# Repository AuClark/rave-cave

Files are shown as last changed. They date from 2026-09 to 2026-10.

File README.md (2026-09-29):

<p><picture><source media="(prefers-color-scheme: dark)" srcset="docs/brand/sektor5-stencil-white.svg">SEKTOR5</picture></p>

A light and visuals rig driven by the DJ decks. A Raspberry Pi Compute Module 4 (the **brain**) joins the Pioneer DJ Link network and listens to the mixer over USB. It reads what each deck is playing, analyses every loaded track ahead of time to find breakdowns, builds and drops, and drives the lights and projection from one scene engine.

**Status (27 Sep 2026):** running end to end in the workshop.
- Two XDJ-700s and a DJM-450 drive two LED tubes, a DMX par can and a mapped projector.
- The live deck follows the mixer faders.
- Generative visuals have 18 sketches with presets.
- Anyone can watch the dashboard from a public link; changes need an admin PIN.
- An LED pyramid is wired and taking test patterns, but isn't in the show yet.

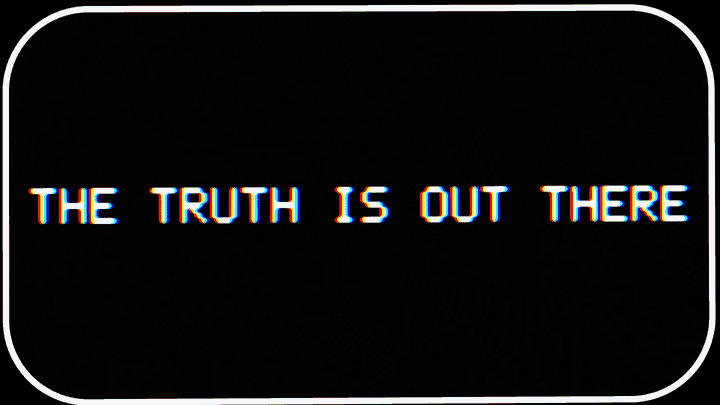
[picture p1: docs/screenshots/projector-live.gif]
The projector output: a generative sketch (subliminal) glitching in time with the music


## System

```mermaid
flowchart LR
  subgraph decks ["Decks"]
    d1["XDJ-700 #1"]
    d2["XDJ-700 #2"]
    djm["DJM-450"]
  end
  sw(["Ethernet switch<br/>Pro DJ Link"])
  d1 --- sw
  d2 --- sw

  subgraph brain ["brain/ · CM4"]
    dd["deckdash<br/>reads the decks · analyses tracks<br/>dashboard :8080"]
    mx["mixer<br/>fader levels · set recording"]
    sb["showbrain<br/>scene engine · 50 fps<br/>Commander :8090"]
    proj["projector<br/>projection mapping · stage :8100"]
    vis["visuals<br/>generative sketches :8110"]
    dd -->|"beats, status,<br/>track timelines"| sb
    mx -->|"which deck owns the mix"| sb
    sb -->|"scene state"| proj
    sb -->|"scene state"| vis
    vis -->|"sketch + live params"| proj
  end
  sw --- dd
  djm -->|"USB audio + MIDI"| mx

  subgraph fixtures ["fixtures/"]
    tubes["tubes/<br/>2 × ESP32 + WLED, 60 LEDs each"]
    pyr["pyramid/<br/>Pi 3 A+ → SP901E<br/>600 × WS2815"]
    par["parcan/<br/>RGBWA+UV uplight"]
    pj["Projector<br/>(Chrome)"]
  end
  sb -->|"DDP over Wi-Fi"| tubes
  sb -->|"DDP over Wi-Fi"| pyr
  sb -->|"USB DMX (uDMX)"| par
  proj -->|"WebGL page"| pj
```

## How it works

1. **Reading the decks.** `deckdash` joins Pro DJ Link as a virtual player (it shows up on the decks as *Sektor5*) using [beat-link](https://github.com/Deep-Symmetry/beat-link). It receives beats and each deck's status, and pulls metadata, artwork, beat grids and colour waveforms from the rekordbox USB.
2. **Reading ahead.** When a track loads, `deckdash` measures bass and energy for every bar and labels the track: intro, groove, breakdown, build, drop, outro.
3. **Following the mix.** `mixer` reads the DJM-450's post-fader levels over USB. The deck holding most of the mix drives the lights, with deck-state rules as a fallback. It also reacts to bass kills, filter and FX, and records every set to FLAC. See [docs/show-engine.md](docs/show-engine.md#which-deck-drives-the-lights).
4. **Scenes.** `showbrain` steps through GROOVE → BREAKDOWN → BUILD → PRE-DROP → DROP, timed in beats, so tempo changes and loops are handled. Each fixture renders its own look for the scene. LED fixtures get frames over DDP on UDP 4048, and the par can gets DMX over USB. Per-fixture delays make everything hit the drop together.
5. **Projection.** `projector` maps content onto surfaces with per-pixel homography in WebGL. One content source is the live sketch from `visuals`, which reacts to the beat, the scene and the playing track's waveform.
6. **Tempo.** The brain can be the DJ Link tempo master: BPM reset, tempo ramps, and an automix that lines up the kicks so drops land together. See [docs/show-engine.md](docs/show-engine.md#tempo-master-bpm-reset-and-automix-tempo-ramps).

## Pages

All pages are served by the brain (`sektor5.local` on the rig's network). Changing anything needs the admin PIN; viewers can look but not touch ([details](docs/brain.md#admin-pin-viewers-and-admins)).

| Page | Where | What it does |
|---|---|---|
| **Decks** (dashboard) | `:8080` | Live decks in XDJ-style waveform lanes with predicted sections and drops, plus a Serato-style track library. Click the logo for the **System** view: temperature, CPU, memory, services, clients, hardware and Tailscale. |
| **Lighting** (Commander) | `:8090` | Performance pads (strobe, blinder, blackout, flash), latched scenes, colour lock, per-fixture mute and level, tap clock, drop control. |
| **Projection** | `:8100/edit` | Mapping editor: surfaces, masks, content, presets. The projector itself opens `:8100/`. |
| **Visuals** | `:8110` | Choose and reshape the live generative sketch and its presets. `:8110/rd.html` is a GPU test lab. |
| **Stage** | `:8100/stage.html` | 3D view of the whole rig lit live from the show, with laser shows, projector brightness and a stage designer. |

| | |
|---|---|
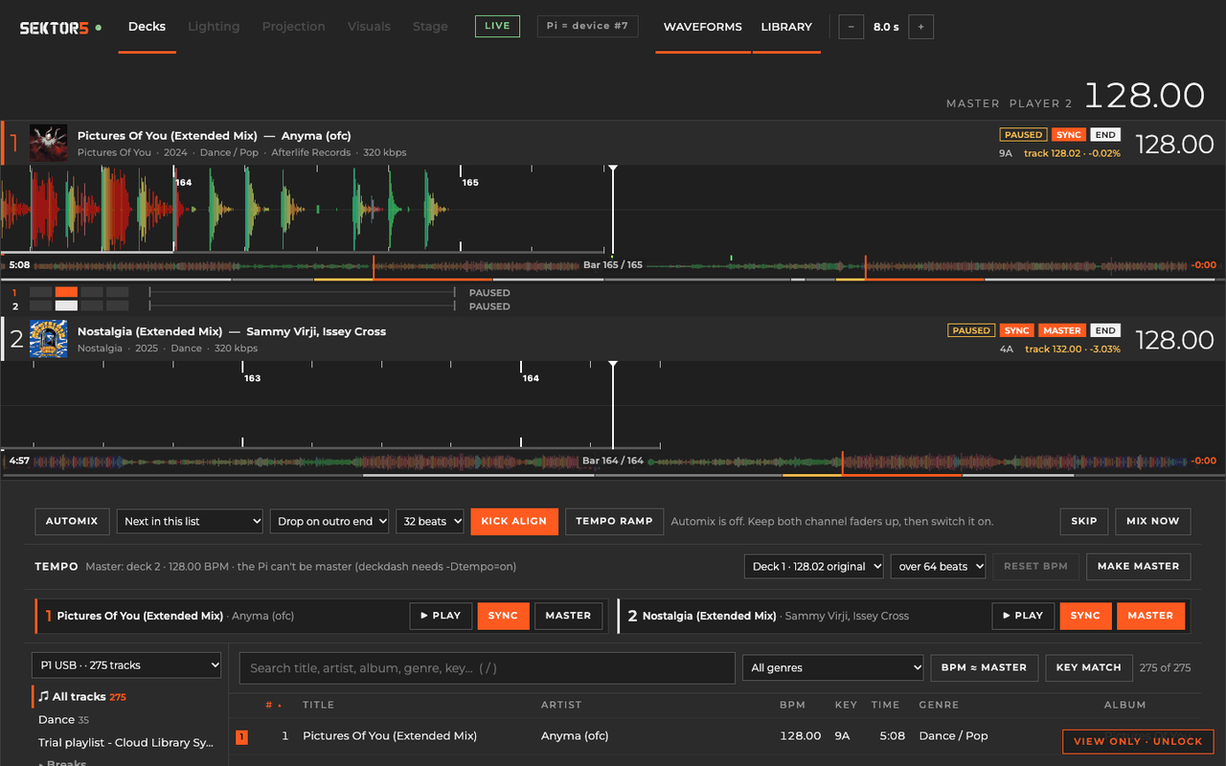
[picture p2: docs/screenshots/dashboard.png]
Decks: waveform lanes, automix and tempo controls, track library
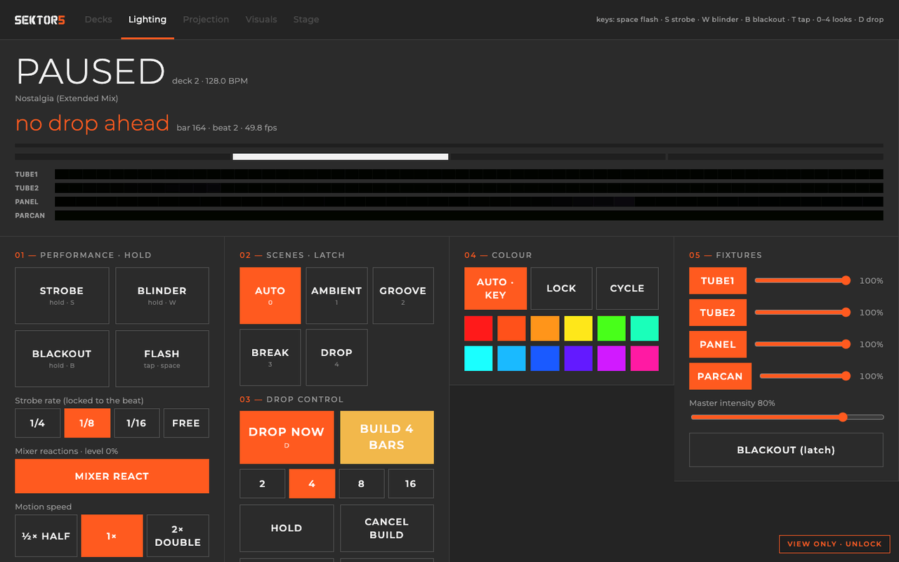
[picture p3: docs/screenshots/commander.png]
Lighting: performance pads, scenes, drop control, colours, fixture levels
|  **Decks** |  **Lighting** |
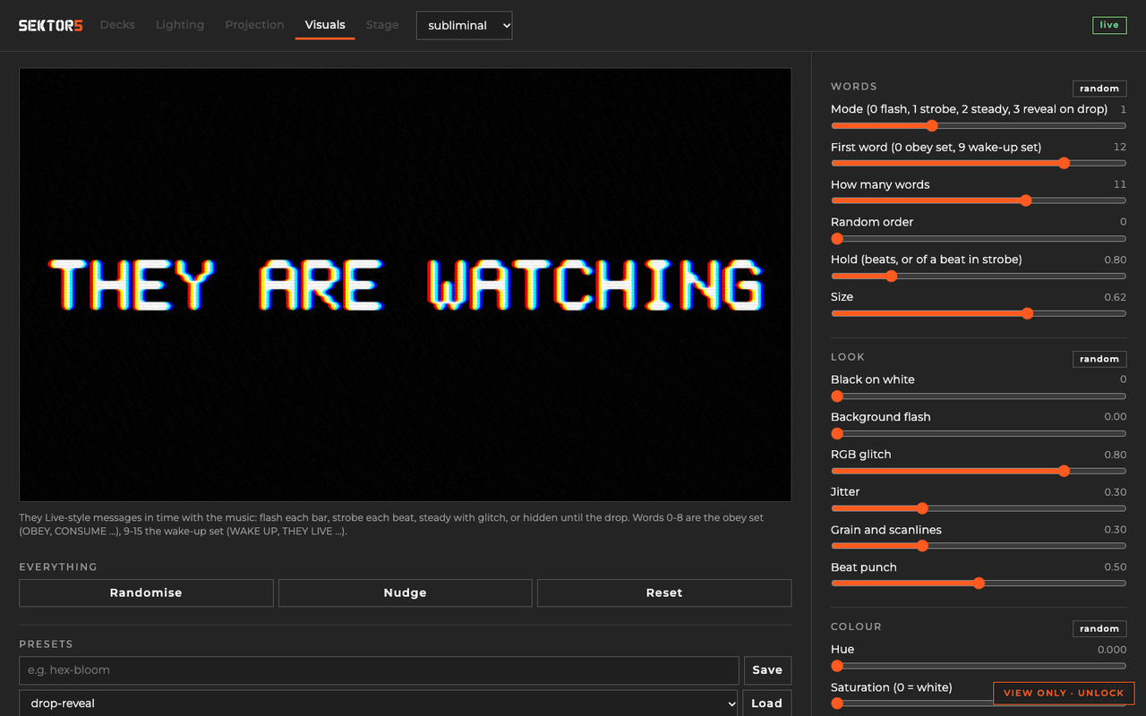
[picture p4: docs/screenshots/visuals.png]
Visuals: the live sketch with its parameters and presets
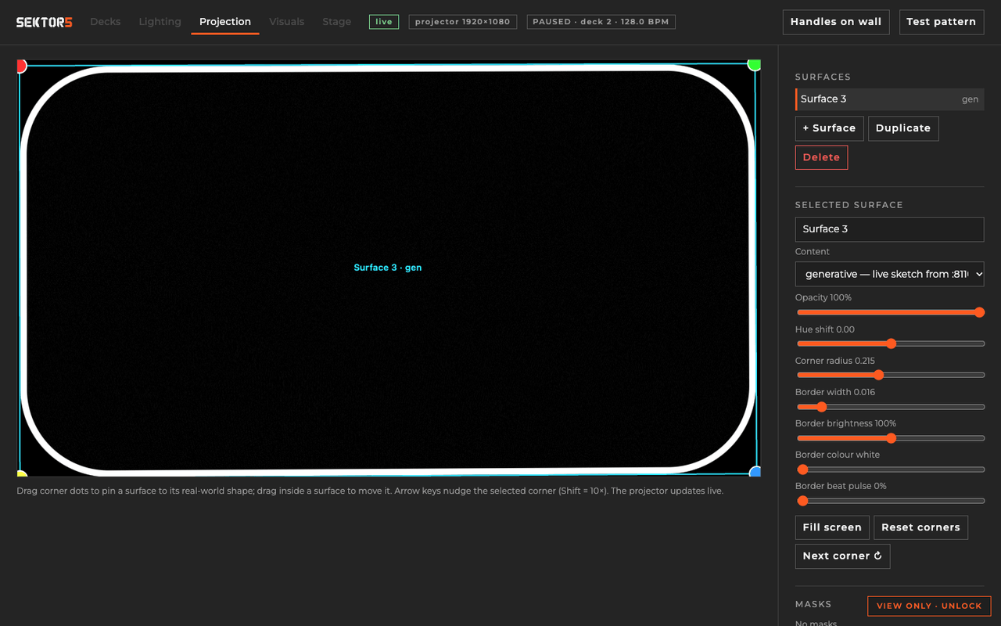
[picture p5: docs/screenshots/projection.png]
Projection: the mapping editor with a surface and its settings
|  **Visuals** |  **Projection** |
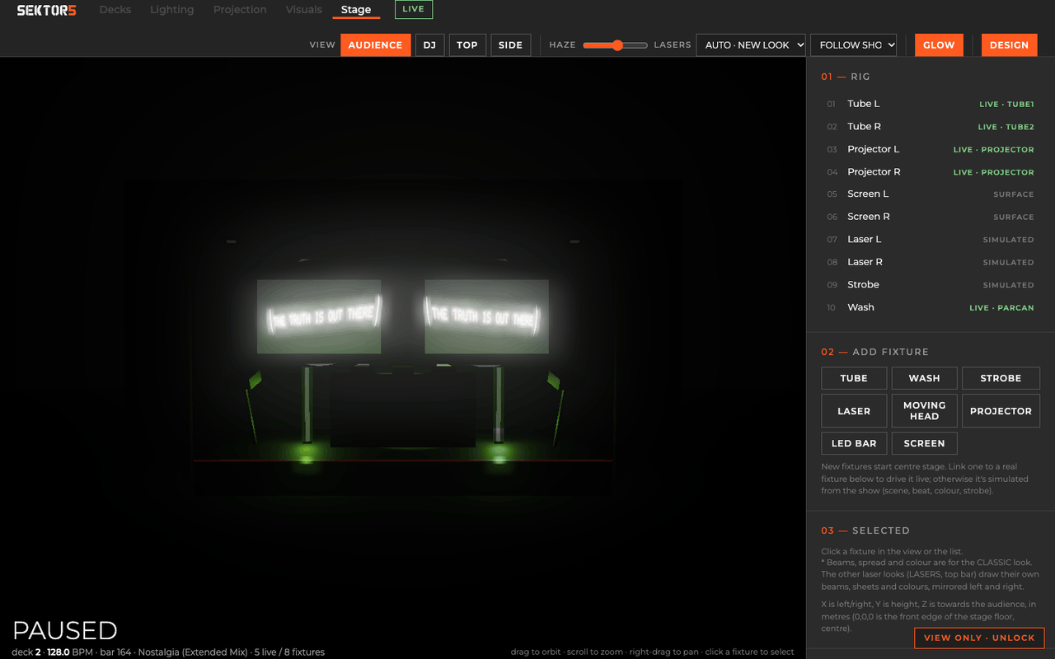
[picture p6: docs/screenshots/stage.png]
Stage: 3D view of the rig lit from the show
|  **Stage** | |

**Remote:** the brain is on Tailscale. The dashboard has a public, view-only link; the other pages are available to the team over the tailnet. See [docs/brain.md](docs/brain.md#remote-access-tailscale).

## Repository layout

| Folder | What's in it | Docs |
|---|---|---|
| [`brain/deckdash/`](brain/deckdash/) | Java Pro DJ Link client, track analyser, dashboard, system info, auth | [show-engine.md](docs/show-engine.md), [api.md](docs/api.md) |
| [`brain/showbrain/`](brain/showbrain/) | Python scene engine, looks, fixture outputs, Commander, `config.json` | [show-engine.md](docs/show-engine.md) |
| [`brain/mixer/`](brain/mixer/) | DJM-450 USB bridge: levels, MIDI, set recording | [show-engine.md](docs/show-engine.md#mixer-reactions-and-set-recording) |
| [`brain/projector/`](brain/projector/) | Projection mapping and the Stage visualiser | [projector.md](docs/fixtures/projector.md), [stage.md](docs/stage.md) |
| [`brain/visuals/`](brain/visuals/) | Generative sketches (GLSL + presets) and their control page | [visuals.md](docs/visuals.md) |
| [`brain/common/`](brain/common/) | Shared by every service: the admin PIN (`s5auth.py`, and `web/s5auth.js` for the pages) | [brain.md](docs/brain.md#admin-pin-viewers-and-admins) |
| [`brain/system/`](brain/system/), [`brain/provision/`](brain/provision/) | systemd units and config; cloud-init for flashing the CM4 | [brain.md](docs/brain.md#build-it-from-scratch) |
| [`brain/tools/`](brain/tools/) | `set_pin.py`, a receive-only DJ Link decoder | |
| [`brain/deploy.sh`](brain/deploy.sh) | Push code to the rig and restart services | |
| [`fixtures/`](fixtures/) | Tubes, pyramid, par can, and the retired HUB75 panels | [docs/fixtures/](docs/fixtures/) |
| [`docs/`](docs/) | Everything else, including [brand/](docs/brand/), [design.md](docs/design.md), `history/` and `manuals/` | |

## Hardware

| Part | Role |
|---|---|
| 2 × Pioneer XDJ-700 (fw 1.13) | Decks, linked through an unmanaged Ethernet switch |
| Pioneer DJM-450 | Mixer, USB to the brain for fader levels and recording |
| Raspberry Pi CM4 (4 GB, 32 GB eMMC, Wi-Fi), carrier board, fan | The brain. Ethernet to the decks, Wi-Fi to the fixtures |
| 2 × 103 cm RGB floor tubes, each with an ESP32 running WLED | LED tubes |
| Battery RGBWA+UV uplight, anyma uDMX | Par can, 10-channel DMX at address 1 |
| Projector with Chrome | Projection mapping and generative visuals |
| Raspberry Pi 3 A+, SP901E amplifier, 2 × 5 m WS2815 (12 V) | LED pyramid (not in the show yet) |

## Working on it

- **Team:** Richard owns the front end (dashboard, Stage), Chris owns projection mapping and visuals. The brain and fixtures expose everything they need through the [API](docs/api.md).
- **Changes** go through a PR to `main`; collaborators merge their own. `main` is what's running. See [CONTRIBUTING.md](CONTRIBUTING.md).
- **Deploy:** `brain/deploy.sh live <target>` deploys `origin/main`, one target at a time: `deckdash`, `web`, `preview`, `showbrain`, `mixer`, `projector`, `visuals`, `tools`, `pyramid`, `panel`. With no target it deploys every brain service.
- **Try page changes** at `:8080/preview/` against live data before going live.
- **Add a fixture:** list it in [`brain/showbrain/config.json`](brain/showbrain/config.json) (`strip`, `panel` or `dmx_par`) and deploy `showbrain`.
- **Secrets and site settings** (Wi-Fi, host overrides) live in a git-ignored `.env`; copy [`.env.example`](.env.example). Settings are `S5_*` (old `RAVE_*` names still work). Never commit SSIDs, passwords or addresses.

## Rebuilding the rig

1. **Brain:** flash and set up the CM4 → [docs/brain.md](docs/brain.md).
2. **Decks:** both players and the brain's Ethernet on one switch; a rekordbox-exported USB in a player. DJM-450 USB to the brain.
3. **Tubes:** ESP32 + WLED in each tube → [docs/fixtures/tubes.md](docs/fixtures/tubes.md).
4. **Par can:** uDMX into the brain, light on 10-channel DMX at address 1 → [docs/fixtures/parcan.md](docs/fixtures/parcan.md).
5. **Pyramid:** Pi 3 A+ → SP901E → strips → [docs/fixtures/pyramid.md](docs/fixtures/pyramid.md).
   **Leg pyramids** (the two side ones, not built yet): ESP32 + WLED, a strip per leg, a laser at the apex → [docs/fixtures/leg-pyramids.md](docs/fixtures/leg-pyramids.md).
6. List the fixtures in `config.json`, run `brain/deploy.sh`, then set the admin PIN (`ssh -t pi@sektor5.local 'python3 ~/tools/set_pin.py'`).

## Known limitations

- **Track analysis and drop detection aren't done.** The live decks use a waveform-only analyser checked by eye on a handful of tracks; it doesn't read rekordbox's phrase analysis yet, and it has known failure modes (a drop called inside a build). Commander marks fix individual tracks. The plan, with a labelled test set from the DJ's library, is in [docs/track-analysis.md](docs/track-analysis.md).
- **The pyramid's Wi-Fi** has dropped several times.
- **The Pi has no RTC**, so its clock is wrong until time syncs after boot.

## Next

Pyramid pixel map and looks, drop-prediction calibration, and laser and smoke outputs. Smoke will have hardware-enforced off-by-default, burst limits and arming. The brain is `sektor5` (the old `ravecave.local` still answers for now). The fixtures' hostnames, service account and `/srv/rave` paths still use the old Rave Cave name and move to `s5-box` / `s5-tube-N` in a later rename; logos and colours are in [docs/brand/](docs/brand/).
- **No hardware?** `brain/sim/run.sh` runs the whole app on your computer against a synthetic rig: decks, mixer and an auto-mixed set. See [docs/sim.md](docs/sim.md).

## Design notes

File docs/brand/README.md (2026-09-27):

# Sektor5 brand

**App logo: the stencil wordmark** (`sektor5-stencil-*.svg`, 568 × 100). It's cut from heavy, chamfered stencil letters, with **SEKTOR** in the text colour and the **5** in orange `#ff5a1f`. On the rig's pages it's inline SVG: `.s5word` takes `--text` and `.s5five` takes `--accent`. It's drawn as plain paths, with no font, mask or ids. The favicon (`sektor5-stencil-favicon.svg`) is the orange stencil 5 on charcoal.

Earlier set (radar mark + Michroma wordmark), kept for reference:

| File | Use |
|---|---|
| `sektor5-stencil-current/white/black.svg` | Stencil wordmark (the app logo) |
| `sektor5-stencil-favicon.svg` | Favicon: stencil 5 |
| `sektor5-logo-*.svg` | Mark + wordmark, horizontal (137.46 × 24) |
| `sektor5-wordmark-*.svg` | Wordmark only (105.46 × 9.6) |
| `sektor5-mark-*.svg` | Mark only, square (24 × 24): favicons, small spaces |
| `png/` | Raster versions: `sektor5-mark-16/32/64/180/512.png`, `sektor5-logo-orange.png`, `sektor5-logo-orange-on-black.png` |

Variants: `black`, `white`, `orange`, and `current` (uses CSS `currentColor`, so it takes the surrounding text colour; used inline on the rig's pages).

- **Accent:** orange `#ff5a1f` (the pages' `--accent`). On the pages the mark is orange and the wordmark is in the text colour.
- **Type:** the wordmark is set in **Michroma** (SIL Open Font License, `Michroma-OFL.txt`), converted to outlines in the SVGs, so no font needs installing.

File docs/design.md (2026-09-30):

# Design

Every control page (dashboard :8080, Commander :8090, projection mapping :8100/edit, the Stage view, visuals :8110) uses one look: **near-black and flat, zinc neutrals with 1 px borders, one orange accent, system type, sentence case**. Somewhere between a Pioneer screen, Ableton and shadcn. The projector's output page (:8100/) doesn't; it's what the audience sees.

## Where it lives

- **The shared theme** is in `brain/common/web/s5auth.js` (`themeCss()`), which every control page loads. It's appended last in `<head>`, so it wins over each page's own styles: the tokens, type, sentence case, control shapes, focus rings, inputs and scrollbars. Change the look there first.
- **Each page's own "design system" block** still sets its layout. Its colours are on the same neutral scale (below), so a page and the theme agree even where the theme doesn't reach, like canvas drawing.
- The top bar, section tabs and phone tab bar are styled in the same file (`barCss`).

## Light and dark

The sun / moon in every top bar cycles **Dark → Light → Match device**. It's one setting for the whole app, shared with Live (`localStorage` `s5theme`), applied before the first paint, and it follows other open tabs.

How it works: every neutral grey in the pages' styles is written as `var(--nRRGGBB, #rrggbb)`, the same colour in dark mode. Light mode (`html[data-theme=light]`, in `s5auth.js`) mirrors each one onto a light zinc scale with its role kept: page, panels, hover, lines, outlines, faint, dim, text. White overlays are `rgba(var(--inv), a)`, which flips to black. **Write new greys the same way**, or they won't flip.

**Displays stay dark in both:** the previews, deck waveforms, the 3D stage and the fixture strips are canvases, and they're what the room sees. Controls that sit on top of a display (`#hud`, `.lanectl`) keep the dark values.

## Tokens

| Token | Value | Use |
|---|---|---|
| `--bg` | `#0c0c0e` | page |
| `--panel` / `--card` | `#131316` | panels and cards |
| `--well` | `#08080a` | canvases, inputs, meters, the insides of things |
| `--line` / `--line2` | `#26262b` / `#3a3a41` | hairlines / button and input outlines |
| `--text` / `--dim` / `--faint` | `#fafafa` / `#a1a1aa` / `#6b6b74` | text / secondary text / hints |
| `--accent` | `#ff5a1f` | the one accent. It means live or on: an active button, drops, master, deck 1 |
| `--good` / `--warn` / `--bad` | `#4ade80` / `#fbbf24` / `#ef4444` | status only, as outlines or text, rarely fills |

**Deck colours:** 1 orange, 2 light grey, then amber and green. rekordbox's track colour tags keep their own colours.

**Type:** system fonts (Inter if installed, then SF / Segoe / Roboto). Nothing is fetched from the web: the brain is often offline at a venue.
- **Sentence case everywhere**, no uppercase labels or letter-spacing. The theme enforces it, so write labels the way they should read. Acronyms (BPM, USB, DJ) stay as they are.
- **Big numbers and scene names:** light weight, large.
- **Headings:** 600, in the dim colour.

## Page frame

The same on every page (in `s5auth.js`): the **display** (waveforms, preview, status, 3D view) and its **section tabs** run edge to edge; the chosen section sits in **one centred column**, `--s5col` (1280 px), straight on the page background, no box or border round it. Stage keeps its side panel. Don't cap a page at a max width or frame it.

## Components

- **Top bar:** the logo, then the page links as quiet text with the current page in a white pill, then the page's own controls. The **SIM / NO DECKS** pill and the **lock** sit at the right end.
- **Section tabs:** a row of quiet text tabs; the chosen one sits in a raised pill.
- **Buttons:** 8 px corners, a 1 px outline that brightens on hover, filled orange when on. Pressing nudges them down half a pixel.
- **Inputs and selects:** the well colour, a 1 px outline, and an orange focus ring.
- **Status tags:** small, 6 px corners, outlined in their status colour.
- **Pictures** (previews, the stage): square, like the projector's frame.
- **Intensity fader** (`VJ.fader` in `vj.js`, styled in `s5auth.js`): the whole bar is the control, an orange fill that breathes on the beat. On the Visuals page, the Launchpad and Live.
- **Live** (`/show.html`) has a design system of its own, with a light mode; it opts out of the shared theme with `<html data-s5-own-theme>`.

## Top bar and phones

- **One top bar on every page** (`.s5bar`, styled by `brain/common/web/s5auth.js`): 48 px (`--s5bar`, which everything pinned under it uses), never wraps. Logo (opens System) and page links on the left, in the same place on every page; page-specific bits fade in; the **SIM / NO DECKS** pill and the **lock** (orange view only, green admin) sit at the right end.
- **Phones (≤ 760 px):** the page links move to a bottom tab bar with icons, in the same order as Live's: Decks · Lighting · Visuals · Projection · Stage · Live. Pages must never be wider than the screen: tables and wide rows scroll sideways inside their panel.
- **Display first, controls in tabs:** on Lighting, Projection, Visuals and Stage the live view (Lighting's status and fixture strips, the projection preview, the visuals preview, the 3D stage) is pinned under the top bar, with **section tabs** under it (`S5AUTH.sectionTabs`); only the chosen section of controls shows, and the page remembers it. Projection and Visuals previews fill the width on phones and keep the projector's aspect ratio.

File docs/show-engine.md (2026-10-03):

# Show engine: read-ahead lighting from the decks

How the Sektor5 CM4 (`sektor5`) turns Pro DJ Link data from the XDJ-700s into lighting that anticipates the music: it detects drops ahead of time, builds suspense into them, and hits the drop on the beat.

Code: [`brain/deckdash/`](../brain/deckdash/) (deck data, timelines, dashboard) and [`brain/showbrain/`](../brain/showbrain/) (scenes, looks, Commander).

**Status (27 Sep 2026): phases 1-4 running** on `sektor5`:
- `deckdash` (Java, :8080): deck data, the track timeline analyser (`Timeline.java`, `/api/timeline/N`), a dashboard with sections, drops and a countdown on the waveforms, a stacked scrolling two-deck waveform, and a UDP feed to showbrain (127.0.0.1:9100).
- `showbrain` (Python + numpy, :8090 Commander): the scene engine at 50 fps (about 2.5 ms per frame), driving `rave-tube-1`, `rave-tube-2` (flipped role, comet hand-off) over DDP and the par can over USB DMX. Per-track overrides and drop-calibration marks are saved in `overrides.json` on the Pi, not in git.
- Deploy with `brain/deploy.sh`.

Still to do: add the pyramid, tune latency by eye, calibrate drop detection across the library, smoke controller.

## What the decks give us

| Data | Source | Use |
|---|---|---|
| Beat packets: beat-in-bar, BPM, pitch, time to next beat/bar | Broadcast by each player on every beat | The beat clock. Every effect locks to this. |
| Player status: playing, cued, looping, master, sync, beat number | Status packets to our virtual CDJ (#7) | Which deck is live; where it is in the track; detects loops and jumps |
| Beat grid: time of every beat | USB export via CrateDigger | Converts beats to bars and phrases; lets us schedule ahead in beats, not milliseconds |
| **Detailed colour waveform**: 150 frames/s for the whole track, red = bass, green = mids, blue = highs | USB export (.EXT) | **Read-ahead**: bass and energy per bar, so we find breakdowns, builds and drops before they play |
| Hot cues and memory points | USB export | Many DJs mark drops. Treat them as strong hints. |
| rekordbox phrase analysis (Intro / Up / Down / Chorus / Outro) | USB export, **only if analysed** | Best-quality labels. Not present in this library yet (see "Improve the input"). |
| Track metadata and artwork | USB export | Per-track palette (from the artwork or the key), dashboard |

Not available: channel faders and on-air (no DJM on the link). "Live deck" is inferred instead (below).

## Evidence so far

Bar-by-bar bass and energy from the detailed waveform, with bars grouped in 8s (`|`), for the two tracks loaded on 2026-09-26:

```
Five (Original Mix) - Dennis Cruz
energy ▁▁▁▁▁▁▁▁|▆▆▆▆▆▆▆▆|...|█▇▇▇▇▇▇▇|▁▁▁▁▁▁▁▁|▁▁▁▁▁▁▁▁|▁ ▁▂▂▅▇▇|▇▇█▇▇▆█▇|...
bass          |▇▇▇▇▇▇▇▇|...|█▇▇▇▇▇▇▇|▂▂▂▂▂▂▂▁|▁▁▁▁▁▁▁▁|▁ ▁▁▂▄▇▇|▇▇█▇▇▅█▇|...
-> beat-in bar 9 (0:15); breakdown bars 81-100; build 99-104; DROP bar 105 (3:16)

It Feels So Good (Extended Mix) - Sonique, Matt Sassari, Hugel
-> beat-in bar 25 (0:45); DROP bar 57 (1:45); DROP bar 113 (3:30), each after a bass-less breakdown
```

The rule used was: a phrase boundary (every 8 bars) where the next 4 bars carry at least 1.6x the bass of the previous 8. It caught every drop in both tracks, with no false positives. It needs validating across the whole library (285 tracks on the USB).

## Architecture

```mermaid
flowchart LR
  decks["XDJ-700 × 2"] -- "Pro DJ Link<br/>(Ethernet, link-local)" --> dd
  subgraph brain ["brain/ (CM4 sektor5)"]
    dd["deckdash<br/>beat-link client<br/>timeline analyser<br/>dashboard :8080"]
    sb["showbrain<br/>beat clock · scene state machine<br/>looks per fixture · Commander :8090"]
    dd -- "UDP :9100 beats + status<br/>HTTP /api/timeline/N" --> sb
  end
  sb -- "DDP over Wi-Fi" --> tubes["rave-tube-1 / 2"]
  sb -- "DDP over Wi-Fi" --> pyr["pyramid (rave-box)"]
  sb -- "USB DMX" --> par["par can"]
```

- **deckdash** is the single owner of the DJ Link connection (only one process can hold the ports).
- **showbrain** is Python for fast iteration on looks. It never talks to the decks directly.
- Each fixture has its own delay (`delay_ms`) so near-instant USB DMX lands with the Wi-Fi fixtures (about 40 ms).

## Track timeline (computed when a track loads)

For each loaded track, build a list of sections in **beats**:

```json
{"track": "Five", "bars": 166, "sections": [
  {"type": "intro",     "startBar": 1,   "endBar": 8},
  {"type": "groove",    "startBar": 9,   "endBar": 80},
  {"type": "breakdown", "startBar": 81,  "endBar": 98},
  {"type": "build",     "startBar": 99,  "endBar": 104},
  {"type": "drop",      "startBar": 105, "endBar": 120, "confidence": 0.9, "source": "waveform"},
  {"type": "groove",    "startBar": 121, "endBar": 158},
  {"type": "outro",     "startBar": 159, "endBar": 166}]}
```

Detection, in priority order (**the design; today only the waveform analysis and cue hints are implemented**, see [track-analysis.md](track-analysis.md)):
1. **rekordbox phrases** if present (not read yet): `Up` means build, `Down` means breakdown, and `Chorus` after `Up`/`Down` means drop (high-mood tracks).
2. **DJ cues**: a hot cue or memory point within a bar of a waveform candidate raises confidence. A cue comment containing "drop" confirms it.
3. **Waveform analysis**: per-bar bass share and energy. A breakdown is a run of at least 4 low-bass bars. The drop is the first phrase boundary (8/16/32 bars) where bass returns strongly. The build is the rising-energy bars before the drop, or at least the last 8 bars of the breakdown.
4. **Beat-in** (first bass after the intro) is its own event type. It gets a smaller hit than a real drop.

Per-track overrides from the Commander ("mark drop here", "not a drop") are saved by rekordbox ID and title, and take precedence next time.

## Which deck drives the lights

Rules in priority order (`Engine.live_deck`, reason shown as `show.live_reason` in the API):

1. **Locked** in the Commander ("follow deck 1 / 2").
2. **Mixer** (DJM-450 over USB, via `brain/mixer`): each channel's **post-fader** level gives its share of the mix. A deck takes over when its (smoothed) share stays at or above **70% for 2 s**, i.e. the DJ has brought its fader up and the other down. During a blend neither dominates, so the lights stay put. A deck cued in headphones with its fader down has ~0% share and can't take over. Settings: `mixer` in `config.json` (`channels` maps mixer channel → player, `takeover_share`, `takeover_s`, `smoothing`, `silent_db`).
3. **Deck state** (no mixer connected): mixer on-air flags if a DJ Link mixer is present; otherwise sticky: stay on the current deck while it plays, hand over when it stops/ends, when it has been in its outro 16 s while the other has played 30 s, or when the incoming deck hits a predicted drop while the outgoing one is in its outro.

## Scene flow (state machine)

```
IDLE ──track playing──> GROOVE <──────────────┐
                          │ section=breakdown  │ 8-16 bars after drop
                          v                    │
                       BREAKDOWN               │
                          │ build window opens │
                          v                    │
                        BUILD ──(DJ loops)──> HOLD (stay at current intensity)
                          │ 1 beat before drop │
                          v                    │
                       PRE-DROP (blackout/inhale)
                          │ drop beat (minus output latency)
                          v                    │
                        DROP ──────────────────┘
```

| Scene | Looks (tube and panel) | Timing |
|---|---|---|
| IDLE | WLED's own ambient effect (Pi stops streaming) | No deck playing |
| INTRO / OUTRO | A hit on every kick over a slow colour breath; the outro at 80% | Beat-locked |
| GROOVE | Hard pulse on every beat, stronger on beat 1, a flick on the off-beat hi-hat; palette from the artwork or key; comet or chase every bar | Beat-locked |
| BREAKDOWN | Slow breathing, desaturated, around 30% brightness, sparkles on the hi-hats | Bar-locked |
| **BUILD** | Brightness climbs; strobe rate doubles every 2 bars (1/4 → 1/8 → 1/16 → 1/32); fill rises up the tube; colour drifts to white; panel chase accelerates | Intensity = progress through the build window |
| HOLD | Freeze build intensity, keep strobing at the current rate | DJ is looping the build |
| **PRE-DROP** | Near-blackout for the last beat (or half bar) | The "inhale" |
| **DROP** | Full white hit on the drop beat, then 8-16 bars of the high-energy scene (strobe on the beat, saturated palette hits); **smoke burst** if armed | Fires early by the measured output latency |

Outside drops and builds the kick's punch scales with the track's energy in that bar (`drive()` in `looks.py`: 0.8× in the quietest bars, 1.3× in the loudest).

Robustness:
- **Loops**: never drop while looping. Drop when the loop exits and the playhead crosses the drop beat.
- **Pitch and tempo changes**: schedule in beats, so they're handled automatically.
- **Jumps and hot cues**: a position discontinuity re-evaluates the current section immediately.
- **DJ mixes out before the drop**: if the live deck changes or stops, cancel the build and fade to the new deck's state.
- **Paused / cued**: freeze, then fade to IDLE after about 5 s.

## Timing

- Beat packets carry *time until the next beat and bar*, so showbrain runs a beat clock (a phase-locked loop) and schedules effects ahead of time.
- **Output latency** (Wi-Fi plus WLED buffering, likely 20-60 ms) is measured once per output and subtracted, so drops land on the kick. Measure with a slow-motion phone video of the deck's beat counter next to the tube, or a tap test in the Commander.
- DDP frames at 60 fps. WLED's realtime mode falls back to its own effect if the stream stops, so the lights never freeze.

## Commander (control page on the Pi)

`http://sektor5.local:8090`, built for a phone or a laptop next to the decks. It works like SoundSwitch or rekordbox Lighting: the auto show runs underneath, and the Commander layers performance controls on top.

- **Status and live view:** scene, live deck, "DROP in N beats", build progress, beat-in-bar, and a live colour strip of what every fixture is outputting right now.
- **Performance pads (hold):** STROBE (locked to the beat at 1/4, 1/8 or 1/16, or FREE at 12 Hz), BLINDER (full white), BLACKOUT, and FLASH (tap: a white hit that decays over about a beat).
- **Scenes (latch):** AUTO, AMBIENT, GROOVE, BREAK, DROP. A latched scene overrides the auto show until AUTO is pressed. DROP NOW and BUILD still take priority.
- **Drop control:** DROP NOW, BUILD 2/4/8/16 bars, HOLD, CANCEL BUILD, SKIP NEXT DROP, MARK DROP HERE (saved as a per-track override).
- **Colour:** AUTO (from the track key), LOCK (tap a swatch), or CYCLE (moves round the wheel every 4 bars).
- **Motion speed:** ½× (half-time), 1×, 2× (double-time) for the beat-driven looks.
- **Fixtures:** on/off and a level fader per fixture, plus master intensity and a latched blackout.
- **Tap clock:** tap tempo, ±1 BPM, SYNC (downbeat now). It drives latched scenes and DROP/BUILD when no deck is playing, so the lights can still run between sets.
- **Setup:** AUTO/MANUAL, follow deck (auto / 1 / 2), output latency, RESET ALL OVERRIDES (fixture levels are kept).
- **Keyboard:** space flash, hold S strobe / W blinder / B blackout, T tap, 0–4 scenes, D drop now.
- To do: **Smoke: ARM / DISARM**, with the burst length shown and the cooldown remaining.

API: `POST /api/cmd {"cmd": ..., "value": ...}` with `mode`, `follow`, `intensity`, `lead_ms`, `hold`, `strobe`, `strobe_div`, `blinder`, `black_hold`, `flash`, `look`, `palette` (`{"mode", "hue"}`), `speed`, `fixture` (`{"name", "on", "level"}`), `tap`, `tap_bpm`, `tap_sync`, `drop_now`, `build`, `skip_drop`, `mark_drop`, `clear`.

## Dashboard: waveforms and library

`http://sektor5.local:8080`. The waveforms are the page's display: always on, pinned under the top bar with a one-line show-engine readout (scene, the deck it follows, the drop countdown, master BPM, zoom). Section tabs under them pick what shows below: **Library**, **Automix** (automix and tempo), **Mixer**, **Show engine**, **DJ Link**, **Media**, **Raw data**.
- **Waveforms:** one lane per deck, deck 1 on top, like the XDJ and rekordbox. Each lane has everything the old deck cards showed: artwork; title, artist, album, genre, label, rating and bitrate; status tags (PLAYING, CUED, LOOP, SYNC, MASTER, END); key, drop countdown, track BPM, pitch and effective BPM; the scrolling waveform with the beat grid and hot/memory cues in their rekordbox colours; and a whole-track overview with sections, drops, cues, playhead, and elapsed · bar · remaining. A phase meter between the lanes shows each deck's beat in the bar and its phase against the master.
- **Library** (tab) is a Serato-style browser for the rekordbox export on the USB/SD in the players (read with CrateDigger). It has crates and playlists on the left, and search, genre, "BPM ≈ master" and "key match" (Camelot) filters with sortable columns. Tracks already loaded on a deck and tracks already played are marked.
  - **Drag and drop:** drag a row (or a deck) onto a deck's waveform to load it there; Shift while dropping loads and plays. **On a phone,** press and hold the row for a moment, then drag it up onto the deck's waveform and let go.
  - **Load** with the per-row deck buttons, a double-click (loads the first deck that isn't playing), or ↑/↓ then Shift+←/→ for deck 1/2. `/` focuses search and Esc clears it. Loading onto a playing deck asks for confirmation first, and the server refuses unless it's forced.
  - **Deck buttons** are on each deck's waveform lane, right of its BPM: play/stop (DJ Link fader start), sync, tempo master.
  - **Columns:** load buttons first, then the track (artist under the title on phones), BPM, key, length, genre; album and date added on wide screens. Played tracks get a tick. On phones the crates are a row of chips above the list.
  - **Untested on the XDJ-700s:** load and transport are sent from virtual player 7. Pioneer players accept these from rekordbox and other players, but whether the XDJ-700 (fw 1.13) accepts them from a non-standard player number still needs checking on the rig. If it ignores them, the next thing to try is `setUseStandardPlayerNumber(true)` in `DeckDash.java`, since with only two decks, numbers 3 and 4 are free.

## Tempo master, BPM reset and automix tempo ramps

A deck that is tempo master can't be retimed remotely: nothing can move its pitch fader. So to glide the tempo, the **Pi becomes tempo master** and every deck with **SYNC** on follows it. `brain/deckdash/TempoMaster.java`, `/api/tempo`:

- **Off by default.** deckdash needs `-Dtempo=on`. That makes it join as a standard player number (1–4, so 3 with two decks) and send status packets, which the decks need before they'll take the Pi as master. It appears on the decks as another player. To turn it on, the owner adds a drop-in:
  ```bash
  sudo systemctl edit deckdash     # then:
  # [Service]
  # ExecStart=
  # ExecStart=/usr/bin/java -Dtempo=on -Djava.awt.headless=true -Xmx384m -Dweb=/srv/rave/deckdash-web -Dpreview=/srv/rave/deckdash-preview -Dorg.slf4j.simpleLogger.defaultLogLevel=warn -Dorg.slf4j.simpleLogger.log.org.deepsymmetry.beatlink.data.MetadataFinder=off -cp lib/*:classes DeckDash
  sudo systemctl restart deckdash
  ```
- **Taking master doesn't jolt the playing track.** The Pi waits for the current master's next beat, starts its own beat clock on that beat at the same tempo and beat-in-bar, and only then takes master.
- **Glides** ease in and out, and are counted in beats as they play.

**Dashboard, Tempo row** (library panel):
- **RESET BPM:** the Pi takes master if it hasn't, then glides every synced deck back to the chosen deck's **original track BPM** over 16, 32, 64 or 128 beats.
- **MAKE MASTER:** hands master to the chosen deck, ending the Pi's.

**Automix:**
- **Drop on outro end** (default): the incoming track starts early enough that its **first drop lands on the beat after the outgoing track's outro**, and the outgoing deck stops on that beat.
  - The Pi can load a track but can't move its playhead, so the lead-in is the distance from where the track loads to its drop.
  - If that's more than 128 beats, or it's already too late, automix uses the fixed overlap and says why.
- **Fixed overlap:** 16, 32 or 64 beats, starting where the outgoing track's outro begins.
- **KICK ALIGN** (default on): SYNC lines up the rekordbox beat grids, and a grid that sits a few ms off its kicks makes synced decks flam. So automix reads each track's grid error from its detailed waveform: the bass onset nearest each grid line in groove and drop sections, trusted only when the middle half agree within 15 ms. On the rig, the middle half of beats agreed within about 7.5 ms. Then:
  - just before the mix it takes SYNC off the incoming deck, but only if that deck still holds the same BPM without it;
  - it starts the incoming deck on the playing deck's actual beat (from its beat packets), shifted by the difference in grid errors, so the kicks line up rather than the grids;
  - after about 2.5 s it measures where the two grids actually landed (beat packets, about 1 ms), learns the deck's start delay for next time (saved in the browser), and puts SYNC back on if the kicks are over 25 ms apart.
  - It's off during TEMPO RAMP, which needs SYNC.
- **TEMPO RAMP** (needs `-Dtempo=on`): the Pi holds master, both decks get SYNC on, and during each mix the tempo glides to the incoming track's original BPM, arriving as the outgoing deck stops.

## Mixer reactions and set recording

`brain/mixer/mixer.py` reads the DJM-450 over USB. As well as the channel levels that pick the live deck (above), it analyses the master mix every 50 ms and records sets.

**Master-mix analysis** (`audio` in the mixer message): bass, mid and high energy; kicks; and **bass out**. Bass out compares the loudest bass of the last beat with the mids, against a slow reference taken while the bass is in. So it fires on an EQ kill, a filter sweep or a bass-less breakdown, whatever the volume. On synthetic test audio it trips about 0.75 s after the bass goes, which is within a beat, and clears 0.1 s after it comes back. It doesn't trip on the gaps between kicks.

**What the lights do** (`Engine.react`, toggle **MIXER REACT** in the Commander, default on from `mixer.react` in `config.json`):
- **Bass out:** GROOVE, DROP, INTRO and OUTRO switch to the sparse breakdown look. When the bass comes back there's a white hit (not during BUILD or HOLD, which have their own drop).
- **Fader level:** master loudness scales brightness from 60% to 100%, so the lights come down with the faders.
- **Kicks:** on a track with no beat grid, the kicks in the mix drive the beat.
- **Beat FX on:** strobes at the Commander's strobe rate.
- **Filter:** sweeps the colour on the live deck's channel.

Beat FX and filter need their MIDI controls mapped in `config.json`:

```json
"midi": { "fx_on": "B0 47", "ch1_filter": "B0 17", "ch2_filter": "B0 18" }
```

Those values are examples, not the DJM-450's. To find the real ones, move one control at a time and read the MIDI line in the dashboard's Mixer panel: each message is `status control value`, and the mapping is the first two bytes. `fx_on` is on when the value is 64 or more. A filter is centred at 64.

**Set recording** (`rec` in the mixer message, shown as **● REC** in the dashboard's Mixer panel):
- The master mix (Rec Out) is written to `/srv/rave/recordings` (`S5_REC_DIR`) as 24-bit 48 kHz **FLAC**, about 0.5 GB an hour. It needs `sudo apt install flac` on the brain. Without that it writes WAV, about 1 GB an hour.
- Recording starts after 3 s of music (keeping 3 s of pre-roll) and stops after 90 s of silence. It won't start with less than 2 GB free.
- Next to each recording it writes a tracklist, `set-….txt` and `set-….cue`, of the deck the lights follow, with timestamps.
- `S5_REC=off` in the mixer service's environment turns it off.

## Smoke safety (non-negotiable)

- Relay defaults **off** at boot and when commands stop (heartbeat timeout).
- Hard cap per burst (e.g. 3 s) and a minimum cooldown (e.g. 60 s), enforced **on the smoke controller itself**, not just in showbrain.
- Must be **armed** in the Commander. Auto drops only fire smoke while armed.
- Respect venue rules and detectors.

## Build phases

| # | Deliverable | Done when |
|---|---|---|
| 1 | **Beat clock + latency**: showbrain pulses the tube on the live deck's beats, with latency compensation | Tube pulses land on the kick by eye at 120-130 BPM |
| 2 | **Timeline analyser** in deckdash, `/api/timeline/N`, sections and drop markers on the dashboard waveform | Predicted drops match by ear on 20+ tracks from the USB |
| 3 | **Scene engine**: GROOVE / BREAKDOWN / BUILD / PRE-DROP / DROP on the tube | Cue a track 16 bars before a drop and it builds and hits on the beat |
| 4 | **Commander**: manual controls, deck follow, overrides, background pre-analysis of the whole USB library | The DJ can override anything from a phone; the next track's drops are known before it loads |
| 5 | **More fixtures**: tubes, par can (done); pyramid, stage strips, laser (DMX), smoke with the interlocks above (to do) | All outputs follow the same scene engine |
| 6 | **Rehearsal**: full set, log every scene decision, tune thresholds | A full set with no missed or false drops that matter |

## Improve the input (free)

In rekordbox: **Preferences > Analysis > Track Analysis Setting**, enable **Phrase**, re-analyse the library and re-export to the USB. That adds Intro / Up / Down / Chorus / Outro labels at exact beats. The waveform analyser stays as the fallback for anything not phrase-analysed.

## Open questions

- Pyramid pixel map (shape, edge lengths, strip route) and pyramid looks.
- Mixer: which DJM, and does it have a LINK port? On-air data would replace the live-deck rules.
- Smoke machine: DMX or switched mains? Which relay or controller?
- The rig network for shows: a dedicated travel router, so home, workshop and venue look identical.

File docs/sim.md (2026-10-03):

# Synthetic rig (working without the hardware)

`brain/sim/run.sh` runs the whole app on your computer against a **synthetic rig**, so you can work on it with the decks, mixer, lights and brain switched off.

```bash
brain/sim/run.sh               # an endless auto-mixed set at 126 BPM
brain/sim/run.sh --bpm 132     # faster
brain/sim/run.sh --no-auto     # nothing mixes itself; load and play from the dashboard
```

It opens the Decks page. The other pages are at the usual ports on `localhost`:

| Page | Address |
|---|---|
| Decks | http://localhost:8080 |
| Lighting (Commander) | http://localhost:8090 |
| Projection | http://localhost:8100/edit |
| Stage | http://localhost:8100/stage.html |
| Visuals | http://localhost:8110 |

Press Ctrl-C to stop everything. Each service's log is in `brain/sim/logs/`. Edits to the pages show when you refresh; edits to the Python services need a restart.

## What's real and what's synthetic

- **Real:** showbrain, the projector service and the visuals service. They're the actual code from the repo, unchanged, doing exactly what they do on the brain.
- **Synthetic:** `brain/sim/fakerig.py` stands in for deckdash (the Java service that talks to the XDJs) and the DJM mixer bridge.
  - It speaks the same protocols: the dashboard API on :8080, and showbrain's UDP feed on :9100 (deck status 20×/s, a packet per beat, and mixer messages).
  - It plays an endless DJ set of 40 generated tracks. Each track has a real phrase structure: intro, grooves, breakdowns, 8–16 bar builds, drops, outro.
  - For each track it provides what the real deckdash would: a timeline with drops, sections, energy and a beat grid; overview and detailed waveforms; and library entries. Playlists are Warm up, Peak time and Trance.
  - **Auto-mix:** the next track starts on the outgoing track's outro, synced to its tempo. Its fader comes up over 8 bars, then the bass and tempo master swap. The old track fades out over 8 bars, and the next track is loaded behind it.
  - **Mixer:** channel levels, share, bass-out (in breakdowns and on the bass swap) and kicks all follow what's playing.
  - **Dashboard controls:** load, play (it starts on the other deck's next beat), stop, SYNC, MASTER and seek all work. With `--no-auto`, you run the set yourself.
- **Not simulated:**
  - Light output: showbrain sends to 127.0.0.1, so nothing lights up. Use the Commander's fixture preview or the Stage view instead.
  - The admin PIN: it's off locally, so everyone is admin.
  - Tempo-master control, album art, set recording and the System view's Pi stats.

## Requirements

- Python 3 with `numpy`. On macOS with Homebrew Python, a global `pip install` is refused (PEP 668), so `run.sh` makes a virtualenv at `brain/sim/.venv` and installs numpy there the first time it needs to. It only does this if `numpy` is genuinely missing, so a machine that already has it is untouched.
- Ports 8080, 8090, 8100 and 8110 must be free. The script checks and names any that are taken.

**About `s5auth.js`:** on the brain, `deploy.sh` copies it next to each service. Locally, `run.sh` links it into place instead. The links are git-ignored.

## On the brain

The brain can run the same synthetic rig, so a Pi on the bench (or at home, with no decks) shows the whole app working, and the real lights follow the generated set.

- **When no decks are found**, every page shows a **NO DECKS** pill at the top right, next to the lock. Tap it for **Start simulation** (needs admin, the PIN) or **Not now**.
- **While it runs**, an amber **SIM** pill replaces the page's LIVE pill (it's the simulator, not the decks). Tap it for sound, volume and **Back to real decks**. Everything else is real: showbrain, the lights, projection, visuals, the Stage view, the admin PIN and the System view.
- **Nothing sticks:** stopping it, restarting deckdash or rebooting goes back to the real decks.
- API: `GET /api/sim`, `POST /api/sim {"on": true|false, "bpm": 126}` (admin). Also in `/api/system` as `sim`.

How it works: deckdash ([`Sim.java`](../brain/deckdash/Sim.java)) runs `fakerig.py` (copied to `~/sim/` by `brain/deploy.sh deckdash`) on port 8079, passes the deck data API through to it (`/api/state`, `/api/events`, timelines, waveforms, library, `/api/deck`, `/api/tempo`), and stops sending its own deck feed to showbrain while fakerig sends the synthetic one. The mixer service is paused meanwhile, because with no DJM it would keep telling showbrain the mixer is unplugged. Its log is `/tmp/fakerig.log`.

### Sound

Tap the **speaker** (left of the SIM pill in the top bar) for sound in that browser, in time with the show. The sound lives in a small player page (`/shell`, [`s5shell.html`](../brain/common/web/s5shell.html)) that shows the control pages inside itself, so it keeps playing while you switch between Decks, Lighting, Projection, Visuals and Stage. Tapping the speaker on a normal page moves you into the player (it looks the same; the address bar shows `/shell#…`); going back to the real decks leaves it. Browsers need one tap before they'll make sound: until then the speaker pulses. The **SIM** pill's panel has the volume.

- **Real tracks** (below) play their actual audio, one player per deck, following the deck's position, pitch, fader and bass EQ as the sim mixes (the bass swap is a real low cut). It stays within a few tens of milliseconds of the deck, at the deck's exact pitch. When the page is busy (a heavy sketch or a transition on the same machine) it holds its course instead of jumping to catch up: a late position reading is ignored, and it only jumps when the smoothed drift is over 200 ms or the deck really moved (a seek, a new track).
- **Synthetic tracks** have no audio, so [`s5audio.js`](../brain/common/web/s5audio.js) synthesises house music that follows showbrain's beat clock: kick, hats, clap and bassline in grooves and drops; a pad and a dark filter in breakdowns; a filter sweep, snare roll and riser in builds; a beat of silence before the drop.

### Your own tracks

The sim on the brain can play real tracks: put them in `/srv/rave/sim/tracks/` (never in git: they're the DJ's music). They come first in the library (**My tracks**), and the auto set plays only them when there are any. One folder per track:

```
/srv/rave/sim/tracks/01-artist-title/
  track.mp3                          the audio
  track.json                         {"title", "artist", "genre", "bpm", "key", "duration"}
  ANLZ0000.DAT  ANLZ0000.EXT  ANLZ0000.2EX   the track's rekordbox analysis, from the USB's PIONEER/USBANLZ/…
```

[`realtracks.py`](../brain/sim/realtracks.py) reads the analysis: the beat grid (so the decks run on the track's real grid, first downbeat included), rekordbox's phrases (intro / up / down / chorus / outro become intro / build / breakdown / drop / outro) and the colour waveform for the dashboard. Keys become Camelot. Restart the sim (or deckdash) to pick up new folders.

**Only tracks with full rekordbox analysis are used:** phrases (turn on **Phrase** in rekordbox's analysis settings), a key, and at least one drop in the phrases. Anything else is skipped (the reason is in `/tmp/fakerig.log`): the sim is for testing the show against tracks whose structure is known, so nothing is guessed. The current set (2026-09-29) is six tech house tracks from the DJ's USB, 123–127 BPM.

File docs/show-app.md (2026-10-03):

# The Show app (Live)

The app has two modes. The **full pages** (Decks, Lighting, Projection, Visuals, Stage) are for setting up and for detail; **Live** is this page, the phone-first remote for running the night. Every full page's top bar (and the phone tab bar) has a **Live** link. In Live, **Full controls** (top right) opens the full page for the screen you're on. The Launchpad is on Live's Visuals screen, and its back button returns to wherever you came from. The **Launchpad** (`/pad.html`, from the Visuals page) is the visuals played as pads.

One page for running a night: the lights and the visuals, each on its own screen (the decks, mapping and stage are on their full pages), with the controls laid out round the picture rather than in tabs. It's served by the `visuals` service: **`http://sektor5.local:8110/show.html`** (on a phone, use the brain's IP). Code: [`brain/visuals/web/show.html`](../brain/visuals/web/show.html).

It drives the rig through the existing APIs, so nothing on the servers changes and every other page keeps working alongside it:

| Screen | Talks to |
|---|---|
| Lights | showbrain `:8090` (`/api/state`, `/api/cmd`) |
| Visuals | visuals `:8110` (this service); the projectors' level from projector `:8100` (`/api/layout`); the track that's playing from deckdash `:8080` (`/api/state`, `/api/art/N`) |

Addresses go through `S5AUTH.url`, so the page works on the rig's network and over HTTPS alike. POSTs go through the shared PIN check; a refused one says why in a toast instead of failing silently.

## The screens

- **Lights.** Scene, the hits (Strobe, Blinder, Flash, Blackout), a colour ring with **Follow the music** in the middle, and the master level.
- **Visuals.** **Now playing**, right above the picture (and pinned with it on phones): the track the show is following (showbrain's live deck, else whichever is on air), its artwork, artist and key, the tempo, the time left and a line with its drops, and what's loaded and waiting on the other deck (Up next). Then the preview (with a Live / Frozen / Reconnecting badge top left and the bar's four beats top right, with the bar number in the phrase beside them: 1 to 4, tap it to count to 8, 16 or 2, one setting shared with the Visuals page) with Freeze and Next look, an **Intensity** fader (calm to full on, played live: it glides, and only moves how strongly the picture reacts, the A / B / C drive amounts and amplitudes like kick punch and glow, never speeds, counts or the look itself; a sketch can opt a setting in or out with `"intensity": true/false`; see `VJ.intensityValues`), and the projectors' output level. On the left, the **look**: the themes, the looks in the one you pick (tap one to mix to it), and **Shuffle** (on/off, every 1–32 bars, Skip, and when the next change lands). The theme you pick is the one Shuffle plays from. On the right, energy (Calm / Groove / Drop), the presets, **Randomise** (a random preset for this look, **R**), and **Words** for looks that draw type. On a phone the picture stays pinned at the top while everything else scrolls under it; the Intensity fader and energy come straight after. The **Audio monitor** (Setup → Audio monitor, shared with the Visuals page's waveform button and the V key) is the track's waveform in its own panel under the picture, for the person running the visuals: never on the projector. Scroll, pinch or −/+ to zoom from 1 to 16 bars. On phones Lights' fixture strips are pinned the same way. **Changes** (under Randomise, in both views) sets how one look hands over to the next: Auto, Cut, Fade, **Pick** (tick the transitions you like; each change picks one of them at random, never the same twice running) or any other transition, landing now, on the beat, on the bar or on the drop (the visuals service's `/api/transition`).

The **Autopilot** pill at the top says what the room is doing that the music didn't ask for (a latched scene, a locked colour, frozen visuals…); tap it to hand everything back. **Setup** (the gear) holds Appearance (dark, light or match the device), the Audio monitor, and links to the full pages for everything done before the night.

## Keys

Space flash · S / W strobe, blinder (hold) · B blackout · 0–4 scenes · D drop now · Z / X / C visuals calm, groove, drop · N next look · R randomise · L Shuffle on/off · F freeze · ? Setup and the key list · Esc closes Setup. Esc no longer hands everything back to autopilot: it's the key you reach for to get out of something, and it shouldn't also drop a blackout mid-set. Use the pill, which says **Reset** while anything is overridden.

## Look

The page has its own design system (it opts out of the shared theme with `<html data-s5-own-theme>`, which is what keeps its light mode working; the lock sits in its header, in `[data-s5lock]`), not the charcoal-and-hairline one in [design.md](design.md): near-black and flat, zinc neutrals with 1 px borders, sentence case, a light mode. The tokens are at the top of the stylesheet. One accent, Sektor orange, and it only means live or on: the look, energy or preset that's playing, Shuffle running, a held hit. A selected choice (a segment, a chip, a theme) is white; blackout is red. Radius 8 / 12 / 16; controls 32–40 px on desktop and at least 44 px on phones. It uses system fonts, so nothing is fetched from the web (the brain is often offline at a gig). The screen stays awake while the page is open (Wake Lock), and hover styles are off on touch screens so a tapped tile doesn't stay lit. The pictures (preview, mapping, stage) stay dark in both themes. On a laptop or desktop every screen fits the window; on a phone the picture comes first and the controls stack under it, at 40 px or more to tap.

## Not here yet

Live has two screens, Lights and Visuals; the decks (automix, the music, waveforms), projection mapping and the stage are on their full pages (Setup, or **Full controls** from the screen you're on). Also still only on the full pages: every sketch setting, saving presets, transition settings, Shuffle's per-look tick-outs and queueing a look for next, the Launchpad's effects and quantised launch; build lengths other than 4 bars, hold / cancel build, skip or mark a drop, strobe rate, motion speed, tap tempo, Mixer React, per-fixture levels; kick align and tempo ramps; projector output latency and resolution; the simulation and System controls.

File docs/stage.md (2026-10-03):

# Stage: 3D visualiser and designer

`http://sektor5.local:8100/stage.html` (the **Stage** link at the top of every control page). It's served by the projector service. The 3D engine is three.js r160, included in `brain/projector/web/vendor/` with its MIT licence, so it works offline.

## What it shows

The stage in 3D: a 4.8 × 3 m platform, a back wall, a lighting truss, and the DJ booth with two XDJs, and the mixer. Your rig sits on it, lit from the running show.

| Fixture | Default position | Driven by |
|---|---|---|
| Tube L / Tube R | Either side of the DJ | **Live:** each tube's real 60 LEDs (`tube1`, `tube2`) |
| Projector L | Outside the tubes, on a stand | **Live:** the projector's output as mapped (its own `render.js` and layout), onto Screen L |
| Projector R | Outside the tubes, on a stand | **Live:** the Visuals page's generative sketch (`:8110`), full frame, onto Screen R |
| Screen L / R | Back wall | Projection surfaces |
| Laser L / R | Top left and right of the truss | **Simulated** laser shows from the show's beat clock and scene (see [Laser shows](#laser-shows)) |
| Strobe | Top middle | **Simulated:** Commander strobe, blinder, and the drop hits |
| Wash | Top middle | **Live:** the par can's DMX colour (`parcan`) |

- **Live fixtures** use what the show engine actually sends each light: `preview` in its state (every LED of a strip, with the fixture's brightness applied; the par can's emitters mixed into one colour), via the projector's `/api/events` feed. Showbrain keeps its last four output frames (50 fps, time-stamped, each fixture as one hex string). The projector sends each frame once, only to pages that ask for them (`/api/events?frames=1`, the Stage page), and leaves the per-LED preview out of the normal state stream. The page plays the frames back at their real spacing, behind by the measured delivery spread plus 50 ms (it adapts if Wi-Fi delivery gets bursty), so rain, sparkles and fills move as smoothly as on the real tubes.
  - Tubes and LED bars are drawn as one continuous strip blended between LEDs, like the real diffuser. A tube is the real one: a 26 mm OD, 1.03 m tube standing in the collar of a four-leg fold-out base.
  - Leg pyramids ([leg-pyramids.md](fixtures/leg-pyramids.md)) draw their four legs' strips from one 225-pixel fixture (56 per leg, foot to apex, then the laser), and their laser straight up from the apex.
  - Drive levels are linear light, so they're read as linear RGB and scaled as a whole (never clipped per channel), which keeps hues exact.
  - Strobe, blinder and the drop's white hit are drawn by the page on the same beat clock, frame-exact, so they can't fall between updates.
  - **Match real lights** (saved with the layout): an LED display gain, a wash gain, a **Projectors** trim, and gamma (1.0 = as sent, WLED's realtime default; 2.8 if the fixture applies its own gamma). Set these by eye against the real rig.
- **Projectors** each show the projector output (as mapped), the Visuals page (generative), or nothing. To make the *real* projector show the visuals, set its surface content to "generative" on the Projection page.
  - A projector throws a 16:9 picture, **Throw** being its horizontal angle, so it lands where the real one would. It's also a camera: **LOOK THROUGH**, **SEND TO EDITOR** (the Projection editor's backdrop) and **MAP ONTO** (surfaces for the faces of a part of the set, e.g. the pyramid), under Selected. See [projector.md](fixtures/projector.md#mapping-from-the-stage-view).
- **Simulated fixtures** follow the scene, beat, colour, strobe and blackout.
- **Linking:** any fixture can be linked to a real fixture from the panel.

## Laser shows

The simulated lasers play full laser shows, locked to the show's beat clock and following its scene. The engine is in `brain/projector/web/lasershow.js`.

- **Looks (LASERS in the top bar, saved with the layout).** They're modelled on the big touring shows, but none of them uses an artist's actual show data.
  - **Epic:** Prydz-style. Cool white plus the track's colour; liquid skies, tunnels, rippling fans.
  - **Red & white:** SHM-style. Crossfire, knives, chases and lattices, chopped in drops.
  - **Trance green:** ASOT-style. Cones, liquid skies, fan waves.
  - **Dark & cinematic:** Afterlife-style. Sparse white and violet blades, slow sheets.
  - **Mainstage rainbow:** Garrix-style. Rainbow bursts, scans, zigzags.
  - **Warehouse techno:** strobing white with amber.
  - **Classic:** the old simple fan, using the fixture's own colour, beam count and spread.
  - **Auto** (the default) picks a new look for each track.
- **Cues:**
  - **Fan:** a wide fan swinging on the beat.
  - **Wave:** a dense fan with a ripple travelling across it.
  - **Tunnel:** a turning cone, drawn as a scanned surface.
  - **Liquid sky:** a rippling sheet over the crowd's heads.
  - **Crossfire:** beams from each side shooting across the centre.
  - **Knives:** a vertical fan slicing sideways.
  - **Chase:** beams jumping to new spots on every step.
  - **Audience scan:** a fan tilting from the floor up over the crowd.
  - **Sunburst:** spokes bursting out once a bar.
  - **Zigzag lattice:** beams crossing into a diamond mesh.
  - **Converge:** a fan closing to a point, used in builds.
- **When cues change:** every 8 bars, or every 4 in a drop, so the show follows the track's phrasing.
- **Mirroring:** every laser in the rig takes part. Left and right mirror each other.
- **Sections:**
  - **Builds** narrow, spin faster and stutter at ¼, then ⅛, then 1/16 as they rise.
  - **Drops** open after the white hit. The 4th bar of each drop phrase stutters.
  - The **pre-drop blackout** cuts them.
- **Physical behaviour:** beams stop at the floor, and **HAZE** sets how visible they are.
- **Section preview:** the second LASERS menu makes the lasers play one section (GROOVE, BUILD, DROP, BREAKDOWN or INTRO) on the show's clock, or at 128 BPM when no deck is playing. It's for designing and only affects your view. **FOLLOW SHOW** returns to normal.
- **Laser fixtures:** add more with **Add fixture → Laser** and place them on the truss or the stage front for a fuller field. Each fixture draws up to 72 beams plus a sheet.

## Venues

A layout can stand in a **venue** instead of the built-in room: a set modelled elsewhere, with its own cameras, ground and light. Pick one under **Layout → Venue**. That loads the venue with its starting rig and replaces the current layout, so EXPORT the current one first to keep it. **RESET TO MY RIG** goes back to the room.

- Venues live in `brain/projector/web/venues/`. `index.json` lists them. Each `<id>.json` holds the venue (`model`, `floor`, `cams`, `light`) and its fixtures; `<id>.glb` is the set as glTF (three.js's GLTFLoader, in `vendor/`).
- The set is only scenery. The fixtures are ordinary Stage fixtures, so they're linked, simulated and edited as usual. Projectors' images land on the set, and the set casts shadows from them. In a venue, fixtures don't get the room's stands or truss clamps, because the model has its own mounts.
- **Lights inside the set:** a wash with `inside` set to the name of a part of the venue model (for example `"inside": "Side_Pyramid_L"`) lights that part from within. The part glows in the light's colour and level, and spills a little light around it; there's no beam.
- **Parts the rig replaces:** `venue.hide` lists parts of the model that aren't drawn (they're hidden, not deleted), for when a fixture now models the thing itself. The outdoor venue hides `Side_Pyramid_L` / `_R`, which the leg pyramids replace.
- **LED strips on the set:** an LED bar with `onto` set to a strip in the venue model (`"onto": "Arch_LED_Strip"`) lays its LEDs along that strip, from one foot of the arc to the other, with a soft halo like the tubes. It's driven like any strip: simulated, or linked to a real one.
- **Daylight** (View tab, saved with the layout) runs from night (0, the room as it always was) to a day sky (1): the sky, haze colour, ambient light and a low sun with shadows come up together. A venue sets its own default (`light.day`) and can override the colours (`light.sky`, `hemiSky`, `hemiGround`, `sun` position). The outdoor venue starts at dusk (0.55), so you can see the set and still see the lights.
- Venue coordinates are the same as the room's (metres, x right, y up, z towards the audience). The venue says where (0, 0, 0) is.

**Outdoor tarp stage** (`outdoor-tarp`) is Chris's Blender design: a 3 × 3 m tarp on four poles, the DJ table with a half-pyramid facade, a side pyramid and PA stack each side, a moon-gate arch 18 m out and the star chill tent beyond it. (0, 0, 0) is the tarp's front edge, on the ground.

| Fixture | Where | Driven by |
|---|---|---|
| Mapping projector | Crossbar between the front poles, aimed at the centre pyramid's front faces (72° short throw, 35% so a 2 m throw doesn't blow out) | Projector output (as mapped) |
| Laser (tripod) | Behind the DJ, on the laser/smoke tripod at 3 m, aimed at the tent roof | Simulated |
| Table par (uplight) | On the DJ table, straight up at the tarp | Live: `parcan` |
| Tube L / R | Floor tubes just outside the gazebo, beside the speakers | Live: `tube1`, `tube2` |
| Leg pyramid L / R | The two side pyramids, built to the real frame ([leg-pyramids.md](fixtures/leg-pyramids.md)): LED strips up the legs, a red laser up from the apex, cover optional (Selected → Cover) | Simulated; View → Section previews their looks |
| Arch LED strip | Round the inside of the arch, foot to foot (240 LEDs) | Simulated (link to a real fixture from the panel) |
| Tent par | Base of the tent pole, up into the roof | Simulated |

It's exported from the Blender file with `export_sektor5.py` (next to `stage.blend`): `Blender -b stage.blend -P export_sektor5.py -- brain/projector/web/venues`. That script reads positions, aims, beam angles and colours from the model, so re-run it after changing the design. The leg pyramids, the tubes' new positions and `venue.hide` were edited into `outdoor-tarp.json` by hand (30 Sep 2026): carry them into the Blender file before the next export, or it will put the old side pyramids and tube positions back.

## Designing

- **Add** a tube, wash, strobe, laser, moving head, projector, LED bar, leg pyramid or screen.
- **Select** a fixture by clicking it in the view or the list.
- **Move and aim:** **MOVE** (or M) drags the fixture; **AIM** (or A) drags the orange dot it points at. You can also type positions in metres. X is left/right, Y is height, Z is towards the audience, and (0, 0, 0) is the front edge of the stage floor, centre.
- **Per-fixture settings:** projector **brightness** (0–150%), beam angle or projector throw, LED or beam count, colour for simulated fixtures, and screen size.
- **Views:** AUDIENCE, DJ, TOP and SIDE. **HAZE** controls how visible the beams are. **GLOW** is a bloom effect; turn it off on slow machines. **DESIGN** hides the panel for a full-screen show view.
- **Saving:** the layout saves to the brain (`/api/stage`, stored in `brain/projector/layouts/stage.json`, not in git) and updates on every open copy. **EXPORT** and **IMPORT** move a layout as a JSON file. **RESET TO MY RIG** restores the table above.

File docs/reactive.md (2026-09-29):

# Audio-reactive drivers

Sketches whose features are driven by *frequency* and *tempo* together: the kick's low end punches one thing, the hats tick another, the chords swell a third, each on its own loop length.

After pwnisher's [How I Create Audio-Reactive Art](https://www.youtube.com/watch?v=12J2XH2UxDc) (Touch Designer crash course, Aug 2025). `sisyphus` is the first sketch built on it; `cathedral` and `inkwell` followed.

## What carries over from the video

He builds one look and then bolts a handful of named **moves** onto it — Swell, Flip, Pulse, Shift, Colours, Float — and each move is one driver wired to one parameter:

| In the video | Here |
|---|---|
| Swell: an **LFO CHOP** on a size parameter | a loop of *N* beats, shaped as a swell |
| Flip / Pulse: a **KeyboardIn CHOP** or MIDI note fires an event | a frequency band crossing into a beat slot |
| Shift: a slow **Noise** value wandering | a slow loop re-rolling a random value |
| Playing it live on a MIDI controller | the track itself plays it |

Two things are worth stealing beyond the operators. First, **the moves are few and named** — six knobs you can hold in your head and perform, not a routing matrix. Second, **each move runs at its own speed**, so they drift in and out of phase and the picture never looks like one metronome. That's what makes an 8-bar swell under a 4/4 punch read as music rather than as a strobe.

What we drop: he triggers by hand (keyboard, MIDI, game controller). We trigger from the track, because the brain already knows the beat grid and the frequency content.

## What we already have to drive it with

No new service, no FFT, no extra plumbing. Every sketch already gets these (see [`render.js`](../brain/projector/web/render.js) `COMMON`):

| Source | What it is |
|---|---|
| `wave(beat)` | `(height, bass, mids, highs)`, each 0..1, at any beat of the **live track**, from the rekordbox colour waveform. 8 samples per beat. |
| `u_beat` | the track's beat position, smooth and fractional |
| `u_bwb` | beat within the bar, 1..4 — gives us the downbeat |
| `u_frac`, `kick()` | position within the beat; `kick()` is 1 on the beat, decaying |
| `u_energy`, `u_scene`, `u_sp` | the show engine's energy, section and progress through it |

So `wave().y` **is** the kick's low end, `wave().w` **is** the hats, `wave().z` **is** the chords and mids. See [visuals.md](visuals.md#the-live-tracks-waveform).

Two honest limits. It's the **analysed** waveform of the track as rekordbox measured it, not live audio off the mixer — so a bass kill, a filter sweep or a fader move doesn't show up in it, and the level is the recording's, not the room's. And it's per beat-grid, so the finest event it resolves is a 32nd note. In exchange it's rock solid through tempo changes, it's identical on every surface with no drift, and it can **read ahead**: `wave(u_beat + 16.0)` is four bars from now, so a visual can start a swell before the chord actually lands.

## The model: band × loop × shape × depth

One driver = four numbers. Everything below is one slot.

```
      BAND            LOOP             SHAPE            DEPTH
   which frequency  how often it    what it does     how much it
   decides how      fires           between fires    moves the picture
   hard it hits
```

Band and loop are the pairing the whole thing turns on: **the loop says *when*, the band says *how hard*.** Set the loop to a bar and the band to kick, and you get a thump on every downbeat, hard on the loud ones and barely there on the quiet ones. Set the loop to 8 bars and the band to mids, and the picture opens up on whichever chord change happens to be loudest.

### Bands

| Value | Band | Reads |
|---|---|---|
| 0 | **Off** | always 1.0 — not gated by sound, pure tempo (the video's LFO) |
| 1 | **Kick** | `wave().y` — the low end |
| 2 | **Chords** | `wave().z` — the mids |
| 3 | **Hats** | `wave().w` — the highs |
| 4 | **Everything** | `wave().x` — overall level |
| 5 | **Energy** | `u_energy` — the show engine's read on the section |

### Loops

Bar-aligned, so anything a bar or longer lands on the downbeat.

| Value | Loop | Beats |
|---|---|---|
| 0 | 1/2 beat (8ths) | 0.5 |
| 1 | every beat (4/4) | 1 |
| 2 | 1 bar | 4 |
| 3 | 2 bars | 8 |
| 4 | 4 bars | 16 |
| 5 | 8 bars | 32 |
| 6 | 16 bars | 64 |

### Shapes

What the driver does across one loop.

| Value | Shape | Curve |
|---|---|---|
| 0 | **Follow** | tracks the band continuously — no trigger, just the level |
| 1 | **Punch** | snaps to the band's level at the trigger, decays away |
| 2 | **Ramp** | climbs 0 → 1 across the loop, then drops |
| 3 | **Swell** | eases 0 → 1 → 0 across the loop |
| 4 | **Gate** | hard on for the first half of the loop, off for the second |
| 5 | **Step** | holds one random value, re-rolls every loop |

Follow + kick is a woofer cone. Punch + kick + 4/4 is a strobe on the beat. Swell + chords + 8 bars is a breath. Step + off + 16 bars is the video's slow noise wander. Gate + hats + 8ths is a shutter.

## The dictionary: three slots, fixed jobs

Every reactive sketch exposes the **same three slots with the same ids**, and each sketch documents what its three are wired to. Learn it once and every sketch works the same way — that's the point.

| Slot | Job | Wired to something that is… | Typical |
|---|---|---|---|
| **A — Hit** | short, sharp, per-event | instant and forgiving of being spammed | scale punch, flash, shake, RGB split |
| **B — Move** | continuous motion | smooth, cumulative | rotation, drift, scroll, warp, wobble |
| **C — Change** | structural, slow | expensive or jarring to change often | re-roll the layout, shift the palette, switch mode, reveal |

Twelve parameters in one **Reactivity** group, always identical:

```json
{"name": "Reactivity", "params": [
  {"id": "aband",  "label": "A Hit · band (0 off, 1 kick, 2 chords, 3 hats, 4 all, 5 energy)", "min": 0, "max": 5, "step": 1, "default": 1},
  {"id": "aloop",  "label": "A Hit · loop (0 ½beat, 1 beat, 2 bar, 3 2bar, 4 4bar, 5 8bar, 6 16bar)", "min": 0, "max": 6, "step": 1, "default": 1},
  {"id": "ashape", "label": "A Hit · shape (0 follow, 1 punch, 2 ramp, 3 swell, 4 gate, 5 step)", "min": 0, "max": 5, "step": 1, "default": 1},
  {"id": "aamt",   "label": "A Hit · amount", "min": 0, "max": 1, "step": 0.01, "default": 0.6},

  {"id": "bband",  "label": "B Move · band",  "min": 0, "max": 5, "step": 1, "default": 3},
  {"id": "bloop",  "label": "B Move · loop",  "min": 0, "max": 6, "step": 1, "default": 0},
  {"id": "bshape", "label": "B Move · shape", "min": 0, "max": 5, "step": 1, "default": 0},
  {"id": "bamt",   "label": "B Move · amount","min": 0, "max": 1, "step": 0.01, "default": 0.4},

  {"id": "cband",  "label": "C Change · band",  "min": 0, "max": 5, "step": 1, "default": 2},
  {"id": "cloop",  "label": "C Change · loop",  "min": 0, "max": 6, "step": 1, "default": 5},
  {"id": "cshape", "label": "C Change · shape", "min": 0, "max": 5, "step": 1, "default": 3},
  {"id": "camt",   "label": "C Change · amount","min": 0, "max": 1, "step": 0.01, "default": 0.5}
]}
```

Those defaults are the house sound: kick punching on every beat, hats shimmering in 8ths, chords swelling over 8 bars. A sketch keeps its own look parameters (size, colour, detail) in its own groups on top, same as every sketch today.

## The code

One block in `COMMON` in [`render.js`](../brain/projector/web/render.js), next to `kick()`. No new uniforms — it's built from what's already there, so every sketch and the projector's built-in content get it for free.

```glsl
// --- Audio-reactive drivers (docs/reactive.md) ------------------------------
// One frequency band of the live track, 0..1. 0 = off, and off means 1.0:
// not gated by sound, so the shape runs on tempo alone.
float band(float b, float beat) {
  if (b < 0.5) return 1.0;
  vec4 w = wave(beat);
  if (b < 1.5) return w.y;          // kick / low end
  if (b < 2.5) return w.z;          // chords / mids
  if (b < 3.5) return w.w;          // hats / highs
  if (b < 4.5) return w.x;          // everything
  return u_energy;                  // the show engine's energy
}

// Loop length in beats: half a beat, a beat, then 1, 2, 4, 8, 16 bars.
float loopBeats(float r) {
  if (r < 0.5) return 0.5;
  if (r < 1.5) return 1.0;
  if (r < 2.5) return 4.0;
  if (r < 3.5) return 8.0;
  if (r < 4.5) return 16.0;
  if (r < 5.5) return 32.0;
  return 64.0;
}

// The beat counter shifted so that every downbeat is a multiple of 4, which puts
// every loop of a bar or longer on the "1" rather than wherever the track started.
float barBeat() { return u_beat - mod(floor(u_beat) - (u_bwb - 1.0), 4.0); }

// A driver, 0..1: the loop says when it fires, the band says how hard.
float drive(float bd, float rate, float shape, float amt) {
  float L  = loopBeats(rate);
  float bb = barBeat();
  float ph = fract(bb / L);                                     // 0..1 through this loop
  float n  = floor(bb / L);                                     // which loop we're in
  // How loud the band was when the loop fired. Two samples over the first beat, so a long
  // loop isn't decided by whatever happened to be in one 32nd note.
  float hit = max(band(bd, n * L + 0.15), band(bd, n * L + 0.55));
  float v;
  if      (shape < 0.5) v = band(bd, u_beat);                   // follow
  else if (shape < 1.5) v = hit * exp(-5.0 * ph * max(L, 1.0)); // punch
  else if (shape < 2.5) v = hit * ph;                           // ramp
  else if (shape < 3.5) v = hit * (0.5 - 0.5 * cos(6.2831 * ph));  // swell
  else if (shape < 4.5) v = hit * step(ph, 0.5);                // gate
  else                  v = hit * hash(vec2(n, bd));            // step
  return amt * clamp(v, 0.0, 1.0);
}
```

A sketch then reads its three slots in one line each:

```glsl
uniform float p_aband, p_aloop, p_ashape, p_aamt,
              p_bband, p_bloop, p_bshape, p_bamt,
              p_cband, p_cloop, p_cshape, p_camt;

vec3 content(vec2 uv) {
  float A = drive(p_aband, p_aloop, p_ashape, p_aamt);   // Hit    -> scale punch
  float B = drive(p_bband, p_bloop, p_bshape, p_bamt);   // Move   -> spin
  float C = drive(p_cband, p_cloop, p_cshape, p_camt);   // Change -> palette
  ...
}
```

`drive()` is four texture lookups at worst and runs per pixel; on a scene using all three slots that's fine, but a sketch that wants a driver in a loop should hoist the three calls to the top of `content()` and pass the values down.

## Presets

Ship the combinations as named presets so a slot config is one tap, not twelve slider moves.

## Gotcha: band 0 is not "off"

Band 0 means *not gated by sound* — `band()` returns 1.0, so the driver runs on tempo alone at full strength. To actually silence a slot, set its **amount** to 0. Setting the band to 0 does the opposite of what the label suggests.

## Gotcha: a driver must not be able to empty the picture

A slot's amount is a range, not a nudge, and the sketch has to be worth looking at across all of
it — including the loudest hit in the track, which is the one the audience sees. `cathedral`
learned this the hard way: B Move was wired straight to the fold angle of its fractal, and about
a seventh of a turn on that angle throws the fractal apart, so on the loud hats the picture went
black. The fix was to map the slider and the driver onto the window of the parameter that always
builds something, rather than onto its whole mathematical range.

So before wiring a slot to a parameter, sweep that parameter end to end and look at it. Anything
with a dead zone gets remapped, not just given a smaller amount — a smaller amount only makes the
blackout rarer, which is worse than making it reliable.

The same habit catches parameters no driver is anywhere near. `wormhole`'s **Mirror** folds the
angle into a wedge of `TAU/(2m)`, but the word lookup was still dividing by a whole `TAU` — so
every setting above 1 quietly sampled only the first `1/(2m)` of the word, a quarter of it at
Mirror 2. It read as the letterforms falling apart, which looked enough like "kaleidoscopes are
just hard on type" to be written off; it was arithmetic, and the fix was one term. A fold, a `mod`
or a `clamp` narrows the domain of everything downstream of it, and nothing warns you.

## The one exception: Hz

Everything in this rig is in cycles per beat, and that is the rule. There is exactly one place it
is broken on purpose. A parameter's **automation** (see [visuals-live.md](visuals-live.md)) has a
**Hz** toggle: with it on, that one LFO free-runs on wall time (`u_time`) instead of the beat.

It is there because some movement should not be musical — a hue drifting over a minute and a half,
a slow wander that would look mechanical if it locked to the bar. Turning it on is a decision to
come off the grid, so it is labelled on the control and it is off by default.

Note what it does **not** do. A sketch's own speed parameters (the ones marked `"kind": "rate"`,
like `speed` in `rings.json`) are multiplied by `u_beat` inside the shader, so they cannot free-run
without changing the shader; they snap to note values and stay on the beat. Hz applies to the
automation LFOs only, which are evaluated in `render.js` where wall time is to hand.

## Testing at home

`wave()` falls back to the looped demo track when no deck is live, so all of this can be dialled in on a laptop. For a real track's bands, capture one on the rig: `python3 brain/visuals/tools/capture_wave.py http://<brain IP>:8080`. Note that `u_energy` and `u_scene` only move when showbrain is running, so bands 5 and the section-driven looks stay flat at home.

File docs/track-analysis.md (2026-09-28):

# Track analysis and drop detection

**Status: not done.** The show engine needs to know, ahead of time, where each track's breakdowns, builds and drops are. What we have works on some tracks and is wrong on others, and it has only been checked by eye on a handful. This page says what exists, where it fails, and how we'll get it right, measured rather than assumed.

## Why it matters

The lights build suspense into a drop and hit it on the beat ([show-engine.md](show-engine.md#scene-flow-state-machine)). A drop called too early fires the big look while the track is still building (and then there's nothing left for the real drop); a missed drop just plays as a groove. Wrong is worse than missed.

## What exists today

There are three separate pieces, and they don't share logic yet.

| Where | Used for | How | Reads rekordbox phrases? |
|---|---|---|---|
| `brain/deckdash/Timeline.java` | **The real decks** (live shows) | Waveform only: bass and energy per bar from the player's detailed waveform. A breakdown is 4+ bars with normalised bass under 0.30. A drop is a 4- or 8-bar phrase boundary (counted from the beat-in) where the next 4 bars carry ≥1.6× the bass of the previous 8 (2.24× off the 8-bar grid), refined to the beat where bass returns. A hot cue or memory point within a bar raises its confidence. | **No.** [show-engine.md](show-engine.md#track-timeline-computed-when-a-track-loads) describes phrases as the first source; that's the design, not the code. |
| `brain/showbrain/showbrain.py` (Commander) | Fixing individual tracks live | **Mark drop here** / **skip drop** in the Commander, saved per track in `overrides.json` and used next time. | n/a |
| `brain/sim/realtracks.py` | **Simulation** with the DJ's own tracks | rekordbox phrases (PSSI) only: tracks without phrases, a key or a drop are skipped. (A crude bass fallback was tried and removed after the Dombresky failure below.) | **Yes**, required. |

## Evidence so far

Checked by eye only. No systematic test has been run.

| Track | Method | Result |
|---|---|---|
| Dennis Cruz – Five (Original Mix) | Timeline.java | Drop at bar 105 correct (2026-09-26) |
| Sonique, Matt Sassari, Hugel – It Feels So Good (Extended Mix) | Timeline.java | Drops at 57 and 113 correct |
| Patrick Topping – Be Sharp Say Nowt | rekordbox phrases (sim) | Correct: build 5–20, drop 21, breakdown 69–84, build 85–100, drop 101 |
| FISHER, Kita Alexander – Atmosphere | rekordbox phrases (sim) | Not checked yet |
| **Dombresky – Simple Hit** | bass rule (sim) | **Wrong:** marked a drop while the track was still building (2026-09-29). Removed from the sim with the rule. |

Two correct tracks from the live analyser and one clear failure from the fallback is not evidence that either works.

## Where the waveform approach goes wrong

Expected failure modes (the first is the one we've seen):

- **Builds that keep the bass**: risers, snare rolls and filtered basslines carry low end, so "bass came back" can fire inside the build. That's the Dombresky case.
- **Drops without a bass change**: in tech house the drop is often the same groove with the bass line or percussion arriving, not bass returning from nothing.
- **Tracks whose intro has bass**: no low-bass stretch before the first drop, so no drop is found, or the beat-in is taken as the drop.
- **Many candidates**: psytrance and minimal have bass nearly throughout; bass dips give false drops.
- **Off-grid phrasing**: drops not on 4/8-bar boundaries from the beat-in, or a wrong beat grid, put the drop a bar or more out.
- **The sim's old bass fallback** worked on 8-bar blocks with fixed thresholds, couldn't place a drop inside a block and misread builds. Removed: the sim now only takes tracks with rekordbox phrases.

## What rekordbox already gives us

On the DJ's USB (JC-A, 1,033 tracks, 2026-09-29):

- **459 tracks (44%) have phrase analysis** (PSSI: Intro / Up / Down / Chorus / Outro at exact beats, for "high mood" tracks). 458 of them have a chorus, i.e. a drop. rekordbox 6 masks this data; `realtracks.py` unmasks it.
- **1,032 have the 3-band waveform** (PWV7: low / mid / high per 1/150 s), much better input than the single-band waveform the live analyser uses.
- Turning on phrase analysis in rekordbox (**Preferences → Analysis → Track Analysis Setting → Phrase**, then re-analyse and re-export) would label the other 56%.

## Plan

1. **Test set.** Take the 459 phrase-analysed tracks as labelled data: rekordbox's drops, builds and breakdowns are the reference. Spot-check a sample by ear, since rekordbox is also sometimes wrong. Keep the labels and analysis files private (outside git, like the sim tracks); commit only the evaluation code.
2. **Measure.** An offline harness runs each analyser over the test set's analysis files (no decks needed) and reports, per method: drops found within ±1 bar (recall), drops that aren't drops (false drops), and section accuracy. Results go in this page, per change, so we can see if a change helps.
3. **Use phrases on the real decks.** When the loaded track has phrases, Timeline.java uses them first (beat-link can fetch the PSSI tag from the player), with the waveform as the fallback. Then the doc claim becomes true.
4. **A better fallback for the rest.** Rebuild the waveform analyser on the 3-band waveform, with the thresholds fitted on the test set, not guessed. Share one implementation between the live decks and the sim.
5. **Learn from the Commander.** Every "mark drop" / "skip drop" is a labelled mistake: log them with the track and feed them into the test set.
6. **Done means measured.** For example: at least 90% of drops within a bar, and under 10% false drops, on the test set, for tracks without phrases. Until a number like that is met and written here, this page's status stays "not done".

Related: [show-engine.md](show-engine.md) (how the show uses the timeline), [sim.md](sim.md#your-own-tracks) (real tracks in the simulation).

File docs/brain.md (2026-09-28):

# The brain (`sektor5`)

The computer that reads the decks and runs the show. Code: [`brain/`](../brain/).

- **Hardware:** a Raspberry Pi with 4 GB RAM and Wi-Fi. `sektor5` is a Compute Module 4 (32 GB eMMC) on a carrier board with heatsink and fan; `sektor5-2` is a Raspberry Pi 4 Model B on a microSD card. Power either from a solid 5 V / 3 A USB-C supply: a bad cable caused brownouts. The CM4's fan runs flat out from 5 V: at full load the CPU stays under 40 °C.
- **OS:** Raspberry Pi OS Lite 64-bit (Debian 13), user `pi`, SSH key login only.
- **Network:** Ethernet to the deck switch (link-local only, never the default route), Wi-Fi to the fixtures and the rest of the network.
- **Services:** `deckdash` (dashboard :8080), `showbrain` (Commander :8090), `mixer` (DJM-450 USB bridge) `projector` (projection mapping :8100, opened in Chrome on the projector) and `visuals` (generative visuals control :8110, see [visuals.md](visuals.md)). All start on boot and restart on failure.

## Set up a new brain

From a blank card to a working brain in about 30 minutes, mostly waiting. Everything runs from the Mac, in this repo, on a clean `main`.

**You need:** a Pi 4 (4 GB) and a microSD card of 32 GB or more in a card reader, or a CM4 with eMMC on its carrier; a 5 V / 3 A USB-C supply; [Raspberry Pi Imager](https://www.raspberrypi.com/software/); Raspberry Pi OS Lite 64-bit (`.img.xz`) in `~/tools/rpi/`; your SSH key in `~/.ssh/id_ed25519.pub`. The Mac must be on the same Wi-Fi as the brain for the `.local` names to work.

1. **Write the first-boot config.** Pick a name that isn't already on the network (`sektor5` is taken):
   ```bash
   S5_HOSTNAME=sektor5-2 python3 brain/provision/make_cloudinit.py
   ```
   It asks for every Wi-Fi network the brain should know (workshop, home…) and joins whichever is in range. Passwords are typed hidden and stay in `~/tools/rpi/cloudinit/`, outside the repo. Forgot one? `python3 brain/provision/make_cloudinit.py --add-wifi`.
2. **Flash it.** Pi 4: put the card in the reader. CM4: set the boot jumper and run `rpiboot` first (see step 1 below).
   ```bash
   brain/provision/flash_card.sh
   ```
   It only offers external, removable disks, shows the disk, image, hostname and Wi-Fi networks, and asks you to type `yes`. Imager ejects the card when it's done.
3. **Boot it.** Card in the Pi (or remove the CM4's jumper), power on, wait 2–3 minutes, then `ssh pi@sektor5-2.local`.
4. **Set it up** (packages, accounts, folders, services, deck Ethernet):
   ```bash
   brain/provision/setup_brain.sh sektor5-2.local
   ```
5. **Deploy the code** and reboot:
   ```bash
   S5_BRAIN_HOST=sektor5-2.local brain/deploy.sh
   ssh pi@sektor5-2.local 'sudo reboot'
   ```
6. **Set the admin PIN** (typed hidden): `ssh -t pi@sektor5-2.local 'python3 ~/tools/set_pin.py'`
7. **Check it.** Open `http://sektor5-2.local:8080/` and click the logo: the System view should show every service running and no under-voltage. With no decks connected, the **NO DECKS** pill at the top right offers **Start simulation**, which runs the whole rig on a synthetic DJ set ([sim.md](sim.md#on-the-brain)).
8. **Optional:** [Tailscale](#remote-access-tailscale) for remote access and a public link (set the PIN first), and [accounts for collaborators](#access-for-collaborators).

To work on it from the Mac, put `S5_BRAIN_HOST=sektor5-2.local` in front of `brain/deploy.sh …`, or in `.env`.

### If something goes wrong

- **The card doesn't show up on the Mac.** Card readers behind USB hubs and docks drop out (the hub's USB 3 side disconnects). Plug the reader straight into the Mac and push the card fully in; `diskutil list external` should list it.
- **A card with only `recovery.bin`, `pieeprom.bin` and `vl805.bin` on it** is the Pi 4 bootloader recovery image, not an OS. It's fine for updating a new Pi 4's firmware (boot it once: the green LED blinks fast when done), then flash the card properly.
- **The brain never appears on the network.** It only knows the networks you gave `make_cloudinit.py`, and it reads them on the first boot only: changing the file on the card afterwards does nothing. Either reflash, or plug the Pi into your router with a network cable (Ethernet uses DHCP until `setup_brain.sh` runs) and add the network: `ssh -t pi@sektor5-2.local '~/tools/add_wifi.sh "Home Wi-Fi"'`.
- **Nothing on USB when the Pi is plugged into the Mac.** Normal: the Pi 4's USB-C port only takes power. A Mac port may not supply enough for a Pi 4; check `vcgencmd get_throttled` is `0x0`.
- **`ssh` warns the host key changed** after reflashing a card with the same name: `ssh-keygen -R sektor5-2.local`.

## What the setup does, step by step

The scripts above do all of this. It's here for reference, and for building a brain by hand.

### 1. Flash the eMMC (from a Mac)

1. Set the carrier's USB boot jumper and connect its USB port to the Mac. It shows up as `BCM2711 Boot`.
2. Build and run `rpiboot` (from [raspberrypi/usbboot](https://github.com/raspberrypi/usbboot), needs `brew install libusb pkgconf`). The eMMC appears as a disk.
3. Put the Wi-Fi SSID and password in the repo's `.env` ([`.env.example`](../.env.example)), then write the cloud-init files:
   ```bash
   python3 brain/provision/make_cloudinit.py      # writes ~/tools/rpi/cloudinit/ (outside the repo)
   ```
   It asks for as many Wi-Fi networks as you like (workshop, home…); the brain joins whichever is in range. `--add-wifi` adds one more to files you've already written, keeping the rest. In `.env` they're `S5_WIFI_SSID`/`S5_WIFI_PASSWORD`, `S5_WIFI2_…`, `S5_WIFI3_…`.
   This sets hostname `sektor5` (`S5_HOSTNAME` in `.env` to change it), user `pi` with your `~/.ssh/id_ed25519.pub`, no password login, Australia/Sydney, Wi-Fi, and `avahi-daemon`.
4. Flash with Raspberry Pi Imager's command-line mode:
   ```bash
   "/Applications/Raspberry Pi Imager.app/Contents/MacOS/rpi-imager" --cli \
     --cloudinit-userdata ~/tools/rpi/cloudinit/user-data \
     --cloudinit-networkconfig ~/tools/rpi/cloudinit/network-config \
     raspios-trixie-arm64-lite.img.xz /dev/diskN
   ```
5. Remove the boot jumper and power-cycle. First boot takes 2–3 minutes. Then `ssh pi@sektor5.local`.

### 2. Network: Ethernet to the decks

The deck switch has no router or DHCP. The decks give themselves 169.254.x.x addresses, so the brain does the same on `eth0` and never routes through it:

```bash
sudo nmcli con mod netplan-eth0 ipv4.method link-local ipv4.never-default yes \
  ipv6.method link-local ipv6.never-default yes
```

On Raspberry Pi OS the NetworkManager profile is generated by netplan. Also put `dhcp4: false`, `dhcp6: false` and `link-local: [ipv4, ipv6]` under `eth0` in `/etc/netplan/90-NM-*.yaml` so it survives regeneration. IP forwarding stays off, so the brain never bridges the deck network and Wi-Fi.

Plug `eth0` into a free port on the deck switch. Every device connects to the switch; don't also cable the decks to each other, or you create a loop.

### 3. Packages and system config

**One command does this step, the `/srv/rave` folders and accounts, the eth0 link-local setup (step 2) and the beat-link download (step 4)**, from the Mac:

```bash
brain/provision/setup_brain.sh sektor5-2.local     # or no argument for S5_BRAIN_HOST / sektor5.local
S5_BRAIN_HOST=sektor5-2.local brain/deploy.sh      # then the code
ssh pi@sektor5-2.local 'sudo reboot'               # eth0 switches to link-local at boot
```

It's safe to run again. What it does, by hand:

```bash
sudo apt-get update && sudo apt-get -y full-upgrade
sudo apt-get -y install openjdk-21-jdk-headless python3-numpy python3-usb tcpdump alsa-utils flac avahi-utils
```

I2C on and the IR receiver overlay (`dtoverlay=gpio-ir,gpio_pin=23`) for an [Argon ONE case](#argon-one-case). Accounts and folders: group `rave`, system user `ravesvc` (group `rave`, no login), `pi` in `rave`, and `/srv/rave/{deckdash-web,deckdash-preview,projector,visuals,recordings}` owned `pi:rave`, mode `2775`. eth0: `/etc/netplan/60-sektor5-eth0.yaml` with `dhcp4: false`, `dhcp6: false`, `link-local: [ipv4, ipv6]`.

From [`brain/system/`](../brain/system/):

| File | Install to | Purpose |
|---|---|---|
| `deckdash.service`, `showbrain.service`, `mixer.service`, `projector.service`, `visuals.service` | `/etc/systemd/system/` | The services (then `sudo systemctl enable deckdash showbrain mixer projector visuals`) |
| `50-udmx.rules` | `/etc/udev/rules.d/` | Lets the `pi` user drive the uDMX (par can) without root |
| `journald-rave.conf` | `/etc/systemd/journald.conf.d/rave.conf` | Persistent logs, capped at 100 MB |
| `argon-fan.service`, `argon_fan.py` | `/etc/systemd/system/`, `/usr/local/lib/sektor5/` | Argon ONE case fan: speed from the CPU temperature over I2C (off below 50 °C, full at 65 °C). Installed, not enabled: turn on after testing (see [Argon ONE case](#argon-one-case)). Shown in the System view. |
| `avahi-alias-ravecave.service` | `/etc/systemd/system/` | Transition only: also answers the old name `ravecave.local` (needs `avahi-utils`). Only on the brain renamed from `ravecave`; remove it once nothing uses the old name. |

### 4. Code

From the Mac, in the repo:

```bash
ssh pi@sektor5.local 'mkdir -p ~/deckdash/web ~/showbrain'
scp brain/deckdash/fetch_libs.sh pi@sektor5.local:deckdash/ && ssh pi@sektor5.local 'bash ~/deckdash/fetch_libs.sh'
brain/deploy.sh          # copies every brain service, compiles, restarts them
```

It refuses unless your checkout is a clean `main` matching `origin/main`. To test a pull request use `brain/deploy.sh --pr N <target>`, and `brain/deploy.sh live` to go back to `main`. See [CONTRIBUTING.md](../CONTRIBUTING.md#deploying-to-the-rig). Each deploy records its commit in `~/.deployed/<target>` on the Pi.

`deploy.sh` also copies the repo's `.env` to the Pi (as `~/showbrain/.env`) if present. It's never committed.

## How the two services fit together

- **deckdash** ([`brain/deckdash/`](../brain/deckdash/)) is the only process on the DJ Link network. It joins as virtual player 7, which stays clear of the decks' numbers. Metadata comes from the rekordbox export over NFS (CrateDigger), because the players' database server only answers to players 1–4.
  - Web: `/` dashboard, `/api/state`, `/api/events` (SSE), `/api/art/N`, `/api/waveform/N`, `/api/wavedetail/N`, `/api/timeline/N`.
  - Pushes beat events and 20 Hz status to `showbrain` over UDP on localhost:9100.
- **showbrain** ([`brain/showbrain/`](../brain/showbrain/)) runs the scenes. See [show-engine.md](show-engine.md). Fixtures are listed in `config.json`, where hosts can use `${VAR:-default}` from `.env`.
- **tools/prodj_listen.py** is a receive-only Pro DJ Link decoder, useful for checking a new deck setup without joining the network.

## Access for collaborators

Each collaborator gets their own account on the brain, never the `pi` user (which has passwordless root and runs the show).

| Account | Can | Can't |
|---|---|---|
| `pi` | Everything (owner) | |
| `richard` | Edit the dashboard page in `/srv/rave/deckdash-web` (live) and `/srv/rave/deckdash-preview`; `sudo systemctl restart deckdash` / `status deckdash`; read logs (`systemd-journal` group) | Touch `showbrain`, the fixtures, system config, or anything else as root |
| `chris` | Edit the projection mapping and generative visuals in `/srv/rave/projector` and `/srv/rave/visuals` (code, sketches, saved layouts and presets); `sudo systemctl restart` / `status` for `projector` and `visuals`; read logs | Touch `showbrain`, `deckdash`, the fixtures, system config, or anything else as root |
| `ravesvc` | Runs the `projector` and `visuals` services (no login, no sudo, group `rave`), so editing their code never gives anyone root | |

Shared folders are owned by `pi:rave`, group-writable and setgid, so files stay editable by the group. The narrow sudo rule lives in `/etc/sudoers.d/<user>`.

**Adding someone:**
```bash
sudo adduser --disabled-password --gecos "Name" name
sudo usermod -aG rave,systemd-journal name
sudo install -d -m 700 -o name -g name /home/name/.ssh
echo "<their ssh-ed25519 public key>" | sudo tee /home/name/.ssh/authorized_keys
sudo chown name:name /home/name/.ssh/authorized_keys && sudo chmod 600 /home/name/.ssh/authorized_keys
```
Removing them: `sudo deluser --remove-home name` (and delete any `/etc/sudoers.d/name`).

**Working on projection mapping and visuals (Chris):**
- Code lives in `/srv/rave/projector` and `/srv/rave/visuals`, and runs as `ravesvc`. Edit in place over SSH (`ssh chris@sektor5.local`), then `sudo systemctl restart visuals` (or `projector`). A new sketch in `/srv/rave/visuals/sketches/` shows up in the control page's menu after a restart.
- Page-only changes (`web/`) just need a browser reload.
- Anything worth keeping goes into a PR. `brain/deploy.sh projector` / `visuals` overwrites the code with what's in git (saved layouts, presets and live values are kept).

**Working on the dashboard page:**
- `http://sektor5.local:8080/` serves `/srv/rave/deckdash-web/index.html`, re-read on every request (no restart).
- `http://sektor5.local:8080/preview/` serves `/srv/rave/deckdash-preview/`, a work-in-progress copy with the same live data. Break it freely.
- API reference: [api.md](api.md). The API allows cross-origin requests, so the page can also be developed on a laptop against `http://sektor5.local:8080/api/...`.
- From the repo: `brain/deploy.sh preview` (test) and `brain/deploy.sh web` (live). Live changes go through a PR to `main` first.

## Admin PIN (viewers and admins)

Anyone can open the pages and watch. **Changing anything needs admin**: loading or playing tracks, tempo, the Commander, projection layouts, visuals. Each service enforces this itself: a change without the admin cookie gets `401`. So hiding a button isn't what protects the rig.

- **Unlocking:** enter the PIN once (any page: the orange lock at the right end of the top bar, or the prompt that appears when you try to change something). The browser gets a signed `s5_admin` cookie for 5 years. Cookies are per host, not per port, so one unlock covers every page on that address (`sektor5.local`, the Tailscale name and the public link each need one unlock).
- **Locking a browser:** click the green (open) lock.
- **Set or change the PIN** (hidden input, stored only as a salted PBKDF2 hash in `/srv/rave/auth.json`, group `rave`, mode 640):
  ```bash
  brain/deploy.sh tools                                # once, copies set_pin.py to the brain
  ssh -t pi@sektor5.local 'python3 ~/tools/set_pin.py'
  ```
  Changing the PIN signs every browser out. `--sign-out` keeps the PIN and signs everyone out (lost phone); `--off` removes it. Services pick changes up immediately.
- **Brute force:** each check takes about 0.5 s, and 8 wrong PINs in 10 minutes lock PIN entry for 10 minutes (per service). Use 6+ digits if the rig is on a public link.
- **Until a PIN is set, auth is off** and everyone is admin, as before.
- Code: `brain/common/s5auth.py` (Python services) and `brain/deckdash/Auth.java` (same token format, so the cookie works on every port). `brain/common/web/s5auth.js` is the shared page script. `deploy.sh` copies these into each service.

## Remote access (Tailscale)

The brain is on the owner's tailnet as `sektor5` (MagicDNS `sektor5.<tailnet>.ts.net`; the real name is in the Tailscale admin console, not in git).

- **Public link (Tailscale Funnel):** `https://sektor5.<tailnet>.ts.net/`. Funnel can only publish one port, so it publishes the dashboard, and **every other page goes through the dashboard's address by path**: `/lighting/`, `/projection/edit`, `/projection/stage.html`, `/visuals/` (deckdash [`Proxy.java`](../brain/deckdash/Proxy.java) passes them to showbrain, the projector and visuals, event streams included). Anyone with the link can look at every page; changes need the admin PIN, as everywhere (each service checks the cookie, which is passed through). Over the tailnet the same `https://…ts.net/` address and paths work.
- **On the rig's network** each page keeps its own port (`http://sektor5.local:8090/` etc.). The page links (and the phone tab bar) pick the right form: ports over plain HTTP, paths over HTTPS. [`s5auth.js`](../brain/common/web/s5auth.js) sends a page's own `/api/...` requests and event streams through its path.
- **Top-bar page links** (`a[data-port]`, wired by `s5auth.js`) are greyed out for viewers.
- **Controls:** the System panel (click the logo) has a Tailscale card: status, devices online, the public link, and buttons to turn the public link or Tailscale itself off and on (admin). Turning Tailscale off while you're using it cuts you off; turn it back on from the rig's Wi-Fi.
- **Setup (done once):** `sudo tailscale up --hostname=sektor5`, `sudo tailscale set --operator=pi` (so deckdash can run the CLI without sudo) and `tailscale funnel --bg --https=443 http://127.0.0.1:8080`. That's all: every page is on 443 by path. Never serve a service's own port (8090/8100/8110) over Tailscale: that service then can't restart (`Address already in use`). All of it survives reboots. Check with `tailscale serve status`.
- **Sharing with a collaborator:** share the `sektor5` machine from the admin console (Machines → sektor5 → Share) or invite them to the tailnet.
- Funnel needs HTTPS certificates and the `funnel` node attribute enabled in the tailnet policy (both already on).

## Renaming the brain

The brain was renamed from `ravecave` to `sektor5` on 27 Sep 2026. What that took, for next time:
- `sudo hostnamectl set-hostname sektor5`, and the `127.0.1.1` line in `/etc/hosts`.
- cloud-init resets the hostname on every boot from `/boot/firmware/user-data` (`hostname:`), so change it there too. `/etc/cloud/cloud.cfg.d/99-sektor5-hostname.cfg` (`preserve_hostname: true`) stops it resetting.
- `sudo systemctl restart avahi-daemon` for the new `.local` name. `avahi-alias-ravecave.service` keeps the old name answering (it publishes the Wi-Fi address at start; restart it if that address changes).
- Tailscale: `tailscale set --hostname=sektor5`, then rebuild the serve config for the new name: `tailscale serve reset` and the funnel line from above. The old `ts.net` link stops working.

## Auto-update

The brain follows GitHub's `main` on its own: `s5-update.timer` runs [`s5_update.sh`](../brain/system/s5_update.sh) 3 minutes after boot and every 15 minutes. It keeps a copy of the repo in `~/sektor5`, compares each target's deployed commit (`~/.deployed/<target>`) with `main` for that target's files, and deploys only what's behind (`S5_BRAIN_HOST=local brain/deploy.sh live <target>`, running on the brain itself). So a merged PR is live within about 15 minutes, without anyone running `deploy.sh`.

- **It waits while a real deck is playing** (a restart would drop the lights mid-set) and tries again next time. The simulation doesn't count.
- **It never touches `/preview/`** (the dashboard test page).
- `setup_brain.sh` installs and enables it. Check with `/usr/local/lib/sektor5/s5_update.sh --check`; logs: `journalctl -u s5-update`; turn it off with `sudo systemctl disable --now s5-update.timer`.
- Deploying from the Mac still works as before and records the same markers, so the two don't fight: a PR deployed for testing (`--pr N`) is replaced by `main` at the next check.

## Argon ONE case

`sektor5-2` (the Pi 4) lives in an Argon ONE case. `setup_brain.sh` sets it up; on another board those parts do nothing.

- **Fan:** run by a chip in the case at I2C address `0x1a` (`sudo i2cdetect -y 1` shows `1a`). The speed is one byte, 0-100; other values are commands to the case (0xFF cuts the power), so only `argon_fan.py` should write to it. `setup_brain.sh` installs the `argon-fan` service but doesn't start it: test the fan first (`python3 -c "import smbus; smbus.SMBus(1).write_byte(0x1a, 100)"`, then `0`), then `sudo systemctl enable --now argon-fan`. The service sets it from the CPU temperature: off below 50 °C, then 25 / 50 / 75 / 100 % from 50 / 55 / 60 / 65 °C, stepping down 3 °C later than up. The System view shows it (Hardware). Logs: `journalctl -u argon-fan`.
- **IR receiver:** on GPIO 23, as `/dev/lirc0`. Test with `sudo ir-keytable -c -p all -t` and press buttons on any remote. The case can't send IR: that needs an IR LED (with a transistor) on a spare GPIO under the case's magnetic top, and the `gpio-ir-tx` overlay.
- **Power button:** a long press (3 s) cuts power in hardware. Short presses aren't wired to a clean shutdown yet, so use `sudo poweroff` first.

## Operations

- Logs: `journalctl -u deckdash -f`, `journalctl -u showbrain -f`.
- Health: `vcgencmd get_throttled` (should be `0x0`), `vcgencmd measure_temp`.
- **No RTC:** the clock is wrong until time syncs after boot. deckdash builds its show feed from per-device status lookups because of this (a timestamp-based lookup came back empty after the clock jumped).
- **The fan's control wire** is unused. If you use it, check its voltage first (a GPIO pin can't take 5 V) and use GPIO18 (pin 12) with the `gpio-fan` overlay.

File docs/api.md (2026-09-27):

# Dashboard API (deckdash, port 8080)

The data the brain exposes for the dashboard front end. Served by `deckdash` on the brain: `http://sektor5.local:8080`. Every response sends `Access-Control-Allow-Origin: *`, so a page on any origin (a laptop, `/preview/`) can use it.

Ownership: the **front end** (the page) is Richard's. The **data behind it** (these endpoints, the fixtures, the services) is maintained by the rig side. If you need something that isn't here, ask for it in an issue or PR. Fields are only ever added, not renamed or removed, without warning.

## Endpoints

**Changes need admin.** Every `POST` (e.g. `/api/deck`, `/api/tempo`) returns `401 {"error":"admin PIN required"}` without the `s5_admin` cookie once a PIN is set. `GETs` stay open. Pages that include `/s5auth.js` get the PIN prompt and retry automatically. See [brain.md](brain.md#admin-pin-viewers-and-admins).

| Endpoint | Returns |
|---|---|
| `GET /api/state` | Full snapshot (JSON), described below |
| `GET /api/events` | Server-Sent Events: the same snapshot pushed about 10× per second as `data: {...}` lines. Use `new EventSource(url)`. |
| `GET /api/timeline/N` | Read-ahead timeline for player N's loaded track: sections, predicted drops, per-bar energy and bass, beat times. `404` until analysed. |
| `GET /api/wavedetail/N` | Detailed colour waveform for player N as binary: 150 frames/s, 4 bytes per frame (height 0-31, r, g, b). Header `X-Wave-Key` identifies the track. |
| `GET /api/waveform/N` | Waveform preview (1200 segments) as JSON: `heights`, `colors`, `maxHeight` |
| `GET /api/art/N` | Album art for player N (JPEG), `404` if none |
| `GET /api/auth` | `{"enabled", "admin"}` for this browser. `POST /api/auth {"pin"}` sets the admin cookie; `POST /api/auth/logout` clears it. Same on every service's port. |
| `GET /api/system` | Brain health, sampled every 2 s (see below). Shown in the dashboard's System panel (click the logo). |
| `POST /api/system/tailscale` | Admin. `{"funnel": true\|false}` turns the public link on/off (off keeps the dashboard on the tailnet); `{"up": true\|false}` turns Tailscale on/off. Returns the new `tailscale` object. |
| `GET /` | The live page (`/srv/rave/deckdash-web/index.html`) |
| `GET /preview/…` | The preview page and any files beside it (`/srv/rave/deckdash-preview/`) |

## `/api/state`

Top level: `now` (ms epoch), `uptimeSec`, `self`, `master`, `devices`, `media`, `mixer`, `show`, `players`.

### `self`, `master`, `devices`, `media`

| Field | Meaning |
|---|---|
| `self.deviceNumber`, `self.name`, `self.address` | The brain on the DJ Link network (virtual player 7) |
| `master.player`, `master.name`, `master.bpm` | The current tempo master and its BPM |
| `devices[]` | Every DJ Link device: `number`, `name`, `address`, `mac`, `seenMsAgo` |
| `media[]` | Mounted rekordbox media: `player`, `slot`, `name`, `created`, `tracks`, `playlists`, `totalBytes`, `freeBytes`, `type` |

### `players[]` (one per deck)

| Field | Meaning |
|---|---|
| `number`, `name`, `address`, `firmware` | Deck identity |
| `status.playing`, `paused`, `cued`, `looping`, `searching`, `atEnd`, `reverse` | Play state flags |
| `status.tempoMaster`, `synced`, `bpmSynced`, `onAir` | Sync state. `onAir` needs a DJ Link mixer, so it's always false here. |
| `status.trackBpm`, `pitchPct`, `effectiveBpm` | Track BPM, pitch fader %, the resulting live BPM |
| `status.beatWithinBar` (1-4), `beatNumber` | Beat position |
| `status.playState1/2/3`, `cueCountdown`, `loopBeats` | Raw player state |
| `status.rekordboxId`, `trackSourcePlayer`, `trackSourceSlot`, `trackType` | Where the loaded track comes from |
| `beat.msSinceLast`, `beat.count` | Time since this deck's last beat packet (flash on < 120 ms), beats seen |
| `position.ms`, `definitive`, `precise` | Playhead position in the track |
| `track.title`, `artist`, `album`, `genre`, `key` (Camelot), `label`, `remixer`, `comment`, `durationSec`, `bpm`, `rating`, `year`, `bitRate`, `dateAdded`, `color`, `colorHex`, `ref` | rekordbox metadata (`track` is absent until loaded) |
| `track.cues[]` | Hot cues and memory points: `hotCue` (0 = memory point, 1 = A…), `loop`, `ms`, `loopMs`, `comment`, `color` |
| `grid.beats`, `grid.bar`, `grid.bars` | Beat grid: total beats, current bar, total bars |
| `hasArt`, `waveformKey`, `timelineKey` | Whether art is available; keys that change when the track changes (use them to refetch waveform or timeline) |
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

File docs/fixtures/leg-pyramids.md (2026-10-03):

# Leg pyramids

Two small pyramids, one either side of the stage. Each is four aluminium legs slotted into a 3D-printed top junction. A WS2815 strip runs up the outside of each leg, an ESP32 at the top drives each leg from its own pin, and a red laser points straight up out of the apex. A white fabric cover over the frame is optional.

**Status (3 Oct 2026):** being built. Pyramid L's controller is set up (WLED, below); strips are being cut. Pyramid R isn't started. Showbrain already drives them (`pyramidL`, `pyramidR` in [`config.json`](../../brain/showbrain/config.json), kind `pyramid`), and the Stage view shows what it sends, so the show can be worked out before the hardware exists. Until the controllers are on the network the output goes nowhere.
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

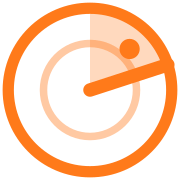
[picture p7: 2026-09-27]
docs/brand/png/sektor5-mark-180.png

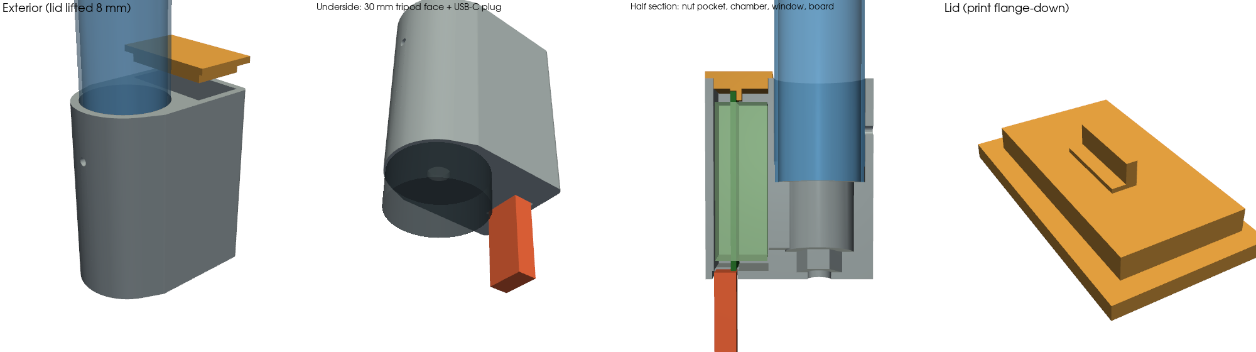
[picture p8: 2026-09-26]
fixtures/tubes/enclosure/out/esp32_devkit38_preview.png

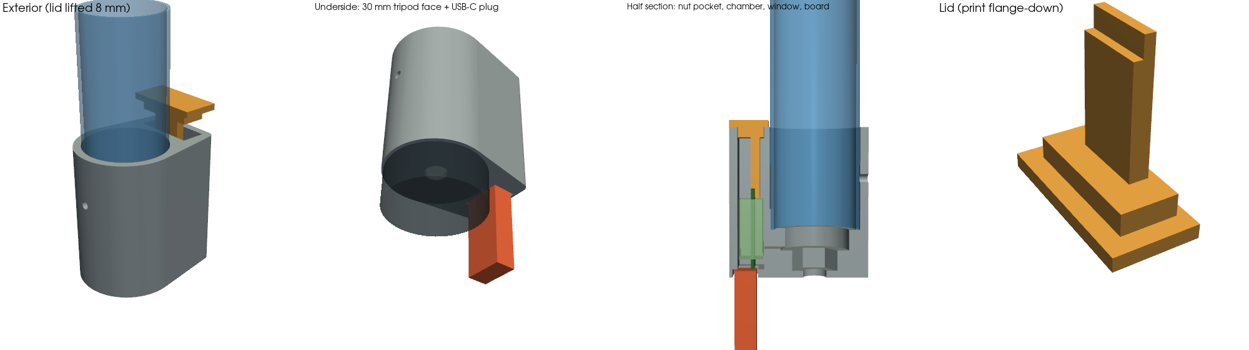
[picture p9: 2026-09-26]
fixtures/tubes/enclosure/out/esp32_c3_zero_preview.png

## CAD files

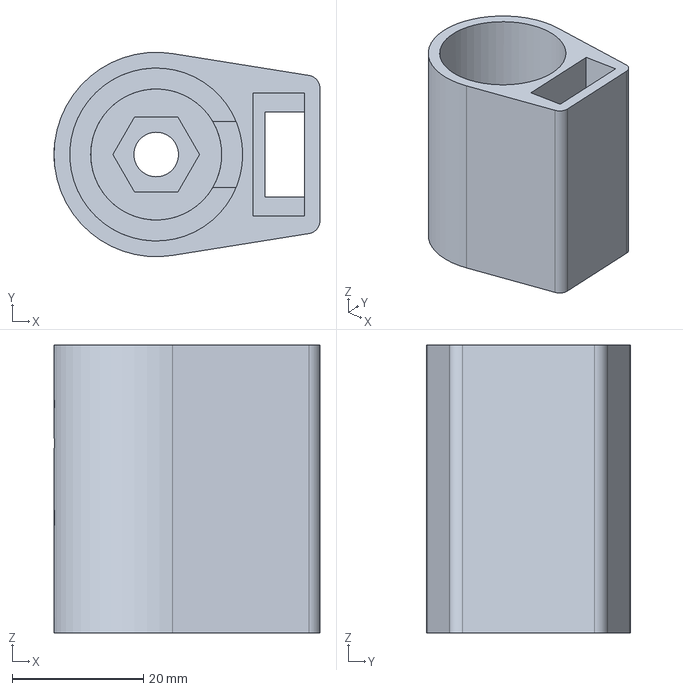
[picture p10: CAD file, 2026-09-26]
fixtures/tubes/enclosure/out/esp32_c3_zero_body.step
40.6 x 31.2 x 44.0 mm

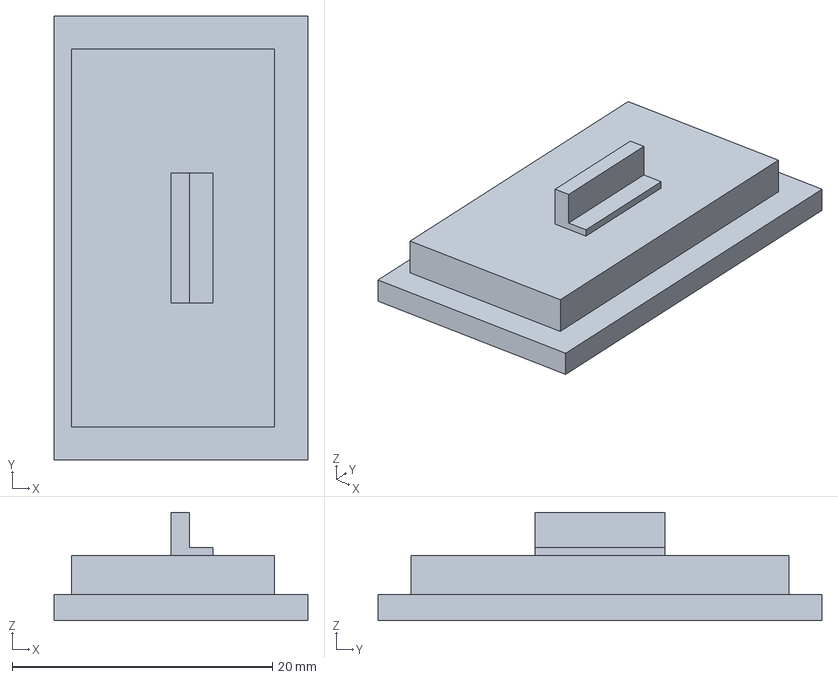
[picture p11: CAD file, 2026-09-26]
fixtures/tubes/enclosure/out/esp32_devkit38_lid.step
19.5 x 34.1 x 8.30 mm

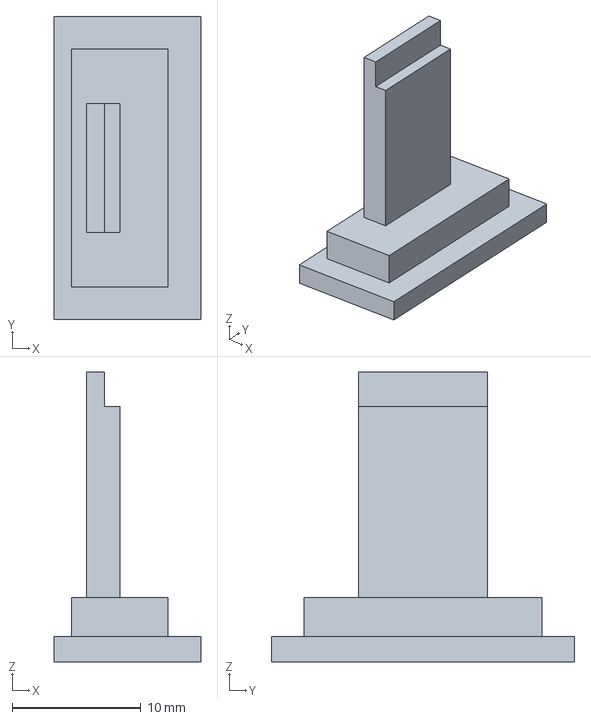
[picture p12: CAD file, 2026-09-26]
fixtures/tubes/enclosure/out/esp32_c3_zero_lid.step
11.4 x 23.6 x 22.6 mm

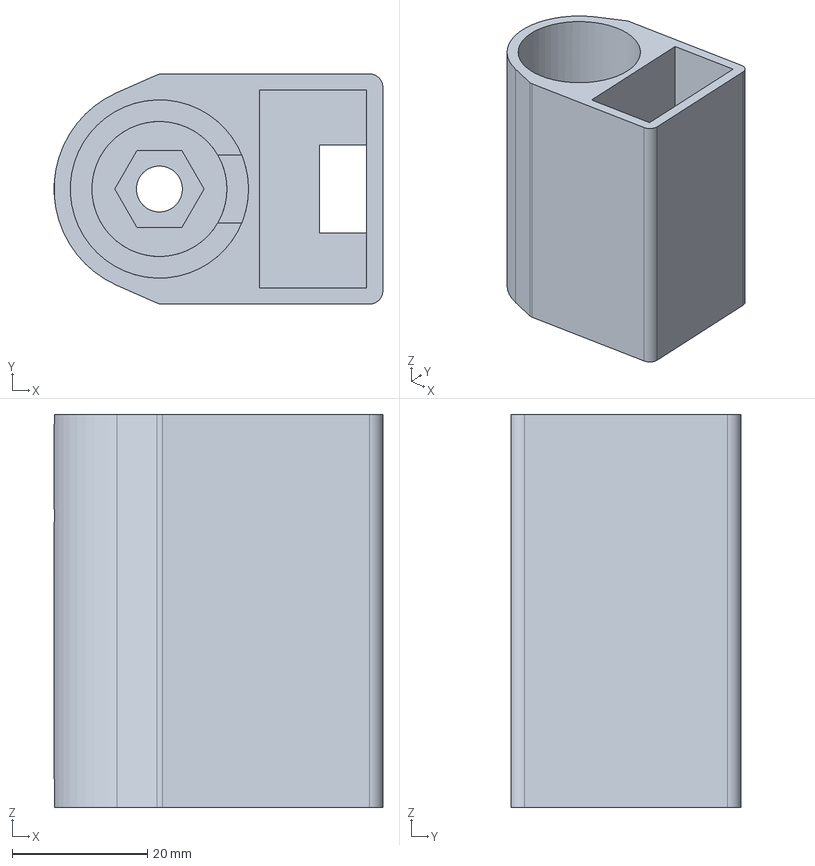
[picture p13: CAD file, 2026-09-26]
fixtures/tubes/enclosure/out/esp32_devkit38_body.step
48.7 x 34.1 x 58.2 mm

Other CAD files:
fixtures/tubes/enclosure/out/esp32_c3_zero_body.stl
fixtures/tubes/enclosure/out/esp32_c3_zero_lid.stl
fixtures/tubes/enclosure/out/esp32_devkit38_body.stl
fixtures/tubes/enclosure/out/esp32_devkit38_lid.stl

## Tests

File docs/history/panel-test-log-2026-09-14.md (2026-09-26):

> **Historical.** First panel bring-up session (14 Sep 2026). The later per-panel tests are in [../fixtures/panel.md](../fixtures/panel.md).

# Panel test log (rave-box)

## Hardware under test
- Pi: Raspberry Pi 3 Model A+ (`rave-box`, `rave-box.local` on workshop Wi‑Fi), user `raver`, SSH key auth (`ssh rave-box`)
- Replaced a BeagleBone controller that was dead (no power LED, no Ethernet link)
- Driver: genuine Adafruit RGB Matrix Bonnet (ADA3211, Core Electronics) — no HAT EEPROM on i2c-1 (expected)
- Library: hzeller/rpi-rgb-led-matrix on Pi at `~/rpi-rgb-led-matrix`, mapping `adafruit-hat`, `--led-slowdown-gpio=2`
- Panels: 4× outdoor HUB75 `YR PH6-8S-V1.2` (P6, 1/8 scan), 192×96 mm, 32×16 px, ~13–18 mm thick, labelled A–D, daisy-chained — treat modules as **32×16** unless proven otherwise
- Power: 5V brick into Bonnet barrel / LED board (not Mac microUSB). Throttle went from active undervolt `0x50005` to historical-only `0x50000` once on proper brick, **but undervoltage warnings still showed after the switch to the barrel jack** — power is not yet proven clean.

## Software commands that worked
```bash
cd ~/rpi-rgb-led-matrix/examples-api-use
# rotating square
sudo ./demo --led-rows=16 --led-cols=32 --led-chain=1 --led-gpio-mapping=adafruit-hat --led-slowdown-gpio=2 -D0
# full wash (custom)
sudo ./rgb-wash --led-rows=16 --led-cols=32 --led-chain=1 --led-gpio-mapping=adafruit-hat --led-slowdown-gpio=2 --led-brightness=40
```
Note: demos were often run with `--led-chain=1` while multiple panels were physically daisy-chained — remapped/half-looking output can be config, not just faults. **To fix:** set `--led-chain=N` to the number of panels physically connected (4 for the full chain → 128×16 logical), and keep `--led-rows=16 --led-cols=32`.

## Session observations (2026-09-15)
Solid R / G / B washes: dead regions in the **same places** across colours → not single-colour LED dies or software; points to interconnects (ribbons, IDC connectors), row/column drivers, traces, or old tiles.
- Horizontal black lines (esp. first/left panel) → row path (decoder / row FETs / cracked row trace).
- Vertical notches / dark columns → column shift-register / IDC pin / ribbon.
- Bottom half often OK while top half dies further down chain → suspect daisy ribbon or first panel OUT / `R2G2B2` upper-half data path; also verify chain length in software.
- Rainbow wash top≠bottom colour is partly normal (per-row hue); trust solids for fault mapping.

Bonnet+Pi path: **works**. Old PH6 tiles: some salvageable, some maybe turf.

## Next steps (summary)
1. Better bracket, off the ground.
2. Reseat every ribbon and connector.
3. Inject 5V power per panel.
4. Bring up one panel at a time; swap chain order to isolate the bad tile or cable.
5. Correct chain/rows/cols in software before judging chained output.

## Careful bring-up guide (do this next)
Goal: get as many of the 4 panels honest as possible; turf only after isolated proof.

1. **Mechanical** — off the floor on a proper bracket; strain-relief ribbons; label panels A–D and both ribbon ends IN/OUT.
2. **Power** — 5V to **each** panel's pads (or inject every panel). Confirm `vcgencmd get_throttled` is `0x0` (or only historical bits) before judging LEDs. Multimeter ≥4.9V on Pi 5V pin under load.
3. **One panel alone** — Bonnet → panel A only. Run solid R, G, B, white at brightness ~40. Photograph. Record dead rows/cols on a sketch.
4. **Swap order** — put B in the first slot alone. If dead row moves with the panel → panel fault. If it stays "first position" → cable/Bonnet/power.
5. **Add second panel** — set `--led-chain=2`. Reseat daisy IDC. Solids again. If upper half of panel 2 dies, reseat/replace daisy cable before condemning panel 2.
6. **Chain 3 then 4** — only after 1–2 look sane. Use `--led-chain=N` matching physical count.
7. **Turf criteria** — whole rows/cols dead when tested **alone** with known-good cable + good 5V → candidate scrap. Cosmetic single pixels OK for stage.

## Panel scorecard (fill in later)
| ID | Alone solids OK? | Dead rows | Dead cols | Notes | Keep? |
|----|---|---|---|---|---|
| A  | | | | | |
| B  | | | | | |
| C  | | | | | |
| D  | | | | | |

## Out of scope for now
- Pi Camera Rev 1.3 / OV5647: enumerates on I2C, CSI capture times out — likely ribbon or undervoltage. Parked. Fix: reseat the ribbon; no need to reflash the SD card.
- Chrome `ERR_ADDRESS_UNREACHABLE` to :8080 while Safari works — use Safari.
- Web UI MJPEG stream auto-start wedged the browser — stream now stays off until "Start stream" is pressed.

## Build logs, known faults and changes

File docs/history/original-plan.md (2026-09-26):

> **Historical.** This is the original weekend plan, written before the hardware was known. It assumes Engine DJ decks over StageLinQ and a Pi 4B. The rig as built uses Pioneer XDJ-700s over Pro DJ Link and a CM4; see the [README](../../README.md). Kept for the parts list, power budget and safety notes.

# Rave Cave: Generative DJ-Synced Lighting (Pi 4B + StageLinQ)

**Goal:** Build a beat-synced lighting rig in one weekend that pulls live data from Engine DJ decks via StageLinQ and drives generative lighting code on a Raspberry Pi 4B. Outputs: ESP32 WLED pixel strips (stage left/right/backdrop), cheap USB-DMX laser, optional BLE tubes, optional smoke relay. MAX open data, NOT proprietary fixture puppets. This is for Jonathan Clark's Sydney show—vibe-coded with friends, parts on the table Friday night, live by Sunday.

---

## Architecture Diagram

```mermaid
flowchart TD
    DECK1[Engine DJ Deck 1<br/>SC5000/SC6000/Prime]
    DECK2[Engine DJ Deck 2<br/>SC5000/SC6000/Prime]
    MIXER[X1800/X1850 Mixer<br/>or All-in-One]
    
    DECK1 -.->|StageLinQ UDP 51337| SWITCH[Gigabit Switch]
    DECK2 -.->|StageLinQ UDP 51337| SWITCH
    MIXER -.->|StageLinQ UDP 51337| SWITCH
    
    SWITCH -->|Ethernet| PI[Raspberry Pi 4B<br/>Show Brain<br/>StageLinQ client + generator]
    
    PI -->|WiFi/Ethernet<br/>DDP or Art-Net| ESP32_L[ESP32-WROOM-32<br/>WLED Segment: Stage Left]
    PI -->|WiFi/Ethernet<br/>DDP or Art-Net| ESP32_R[ESP32-WROOM-32<br/>WLED Segment: Stage Right + Backdrop]
    
    ESP32_L -->|Data + 12V| SP901E_L[SP901E Pixel Amp<br/>Level Shift]
    ESP32_R -->|Data + 12V| SP901E_R[SP901E Pixel Amp<br/>Level Shift]
    
    SP901E_L -->|12V 10A| WS2815_L[WS2815 5m Strip<br/>300 LEDs, Stage Left]
    SP901E_R -->|12V 10A| WS2815_R[WS2815 5m Strip<br/>300 LEDs, Stage Right/Backdrop]
    
    PI -->|USB DMX<br/>cheap Ali FTDI stick| LASER[ALIEN SLP-RGB500<br/>500mW RGB Laser<br/>10ch DMX, IEC C14 240V]
    
    PI -.->|Optional BLE/IR| TUBES[103cm RGB CCT Floor Tubes<br/>5V USB, BLE/IR remote<br/>stretch goal]
    
    PI -.->|Optional USB HID relay<br/>or ESP32 mains relay| SMOKE[Smoke Machine<br/>240V mains or DMX]
    
    style PI fill:#fc9,stroke:#333
    style ESP32_L fill:#9cf,stroke:#333
    style ESP32_R fill:#9cf,stroke:#333
    style TUBES stroke-dasharray: 5 5
    style SMOKE stroke-dasharray: 5 5
```

---

## Why Not SoundSwitch / Micro DMX?

**Jonathan wants MAX open data and generative code, NOT proprietary fixture puppets.**

SoundSwitch path problems:
- **Closed ecosystem:** Micro DMX + SoundSwitch Pro licence (US$7.99/mo, $79.99/yr, $199.99 perpetual) required for DMX. Basic mode is Hue/Nanoleaf only.
- **Fixture Profiles = puppet mode:** You patch RGB PARs at DMX addresses and SoundSwitch autoscript writes canned cues. Lasers need Attribute Cues (gobo/pattern mode). You're puppeting fixtures, not generating from data.
- **No raw BPM / beat / waveform API:** SoundSwitch DLW runs on a PC, exports a baked project to the deck. You can't live-code against StageLinQ waveforms or infer drops in a Python script during the show.
- **VID/PID locked USB:** Only SoundSwitch-branded hardware works (Micro DMX, Control One). Can't plug a cheap Ali USB-DMX into the deck and script it.

**Pi 4B + StageLinQ path:**
- **Open protocol:** StageLinQ is reverse-engineered (https://github.com/chrisle/StageLinq). Engine DJ decks broadcast StateMap (play state, BPM, pitch, faders, crossfader, hotcues, loops), BeatInfo (realtime beat position, total beats), FileTransfer (3-band waveform blobs, beat grid, artwork). UDP 51337 discovery, TCP JSON/binary.
- **Generative code:** Pull BPM, beat-in-bar, fader positions, crossfader L/R, 3-band waveform energy. Write Python/Node/Rust to map that to WLED segments (L/R chases, brightness from faders, drop detection from waveform spikes) and DMX laser patterns. Vibe-code it on Saturday.
- **Cheap USB-DMX on the Pi:** Ali FT232-based USB-DMX is fine on Pi Linux (QLC+ or Python pyusb/pyserial). Engine DJ decks reject cheap dongles, but the Pi doesn't care.
- **WLED is pixels, not RGB PARs:** DDP/Art-Net from the Pi can address every LED in a strip (300 LEDs = 900 DMX channels as RGB, or 1200 as RGBW). SoundSwitch treats WLED as "1 DRGB fixture" (whole strip same colour). Here you get per-pixel chases.

**Trade-off:** You write the generator yourself. No autoscript. That's the point.

---

## StageLinQ Data Map

### What We Get (Protocol Layers)

| Layer | Content | Format | Use Case |
|---|---|---|---|
| **Discovery** | Device announce (deck, mixer) | UDP 51337 broadcast, JSON | Find devices on LAN, get IP + port for TCP |
| **StateMap** | Track title/artist/path, play state, pitch, BPM, master/sync flag, faders (deck volume, filter), crossfader, hotcues, loops, deck assignment | TCP JSON stream | Live mix state: is deck playing? BPM? Fader up? L/R on crossfader? |
| **BeatInfo** | Realtime beat position (0.0–1.0 within bar), total beats played, current BPM (including pitch bend) | TCP JSON stream | Trigger on beat 1, chase across 4 beats, pulse on every kick |
| **FileTransfer / DB** | Waveform overview (3-band zlib blobs: low/mid/high frequency energy per time slice), beat grid (quantized beats), track artwork, performance data (play count, last played) | TCP binary + JSON | Drop detection (spike in mid/high vs baseline), pre-cue next track's energy profile, visual waveform on a screen |

### What We Infer (Not Native Flags)

| Inference | Method | Code Hint |
|---|---|---|
| **Drop incoming** | Waveform energy drop → build → spike. Track 3-band mid/high across 8–16 bars; if current bar is <30% of 16-bar avg and next bar spikes to >150%, that's a classic build/drop. | Decompress zlib, parse 3-band blob, sliding window energy avg, threshold trigger 4 beats before spike → flash white + strobe |
| **Deck active** | `play_state == 'playing' && deck_fader > 0.1 && (crossfader left/centre or right/centre depending on deck)` | If Deck A fader > 0 and crossfader left/centre, that deck is audible. Assign WLED segment to that deck's BPM. |
| **Mix transition** | Crossfader moving from L to R (or R to L) over >2 sec while both decks fader > 0 | Blend L/R segment brightness via crossfader position. |
| **Hotcue jump** | StateMap hotcue triggered → beat position resets → resync pixel chases | Re-align chase phase to new beat grid position. |

### Libraries

| Library | Language | Features | Link | Notes |
|---|---|---|---|---|
| **StageLinq (chrisle)** | TypeScript | Discovery, StateMap, BeatInfo, FileTransfer, waveform decode | https://github.com/chrisle/StageLinq | **Fullest reverse-engineering.** BeatInfo + waveforms. Use this or port to Python. |
| **PyStageLinQ** | Python | Discovery, StateMap only | https://github.com/Jaxc/PyStageLinq | No BeatInfo, no waveforms. Good for quick fader/BPM demo, not enough for drops. |
| **Mixboard** | Electron (TypeScript) | Live dashboard to inspect StageLinQ firehose | https://github.com/LaokeQwQ/Mixboard | Run this Friday night to confirm decks are broadcasting. Great debug tool. |

**Protocol docs:** https://github.com/honusz/stagelinq-js/blob/main/docs/PROTOCOL.md

---

## Hardware Map

### Already Ordered (AliExpress, Sep 2026)

| Item | Qty | Spec | Power | Use |
|---|-----|---|---|-----|
| **ESP32-WROOM-32 DevKit** | 2 | USB-C, CP2102, dual-core 240 MHz, WiFi | 5V USB (500mA) | WLED endpoints for L/R strips. NOT the brain (that's the Pi). |
| **12V 10A power brick (AU plug)** | 2 | 120W, switch-mode | 240V mains → 12V DC | One per 5m WS2815 roll. Inject both ends. |
| **ALIEN SLP-RGB500 laser** | 1 | 500mW RGB, 10ch DMX, IEC C14 inlet, 100–240V | IEC C13 kettle lead (240V AU mains) | Brazil plug SKU, same unit. Use AU PC power cable. |
| **WS2815 12V 60 LED/m IP67** | 2× 5m | White PCB, 300 LEDs per roll, dual-data line | 12V, ~2.4A/m full white = 12A per 5m | 10m total. 30/m would be easier; 60/m is OK with two bricks + brightness cap. |
| **SP901E pixel amp** | 2 (confirm cart) | 12V input, 5V data output, 2048 px, SPI support | 12V from same brick as strip | Level shift 3.3V ESP32 GPIO → 5V WS2815 data. NOT blue I2C BSS138 modules. |
| **SN74AHCT125N DIP** | Backup | Quad buffer, 5V VCC, 3.3V input tolerant | 5V (NOT 12V) | DIY level shift if SP901E fails. 74AHCT125 VCC = 5V, input = 3.3V ESP32, output = 5V data line. |

### Still Need to Buy

| Item | Why | Approx Price | Where | Notes |
|---|-----|---|---|---|
| **Cheap USB-DMX (3-pin XLR)** | Laser control from Pi | ~AU$20–40 | AliExpress, eBay | Look for FT232 chipset (FTDI-based, Linux-friendly). "USB to DMX512" 3-pin XLR female out. Avoid CH340 (flaky). |
| **3-pin DMX cable (3m+)** | Pi USB-DMX → laser XLR IN | ~AU$10–15 | Jaycar, DJ City, AliExpress | 3-pin (not 5-pin). Stage-length. |
| **Gigabit switch** (if not owned) | Decks + Pi on one LAN for StageLinQ | ~AU$20–30 | Officeworks, Jaycar | 5-port unmanaged. Only if decks aren't already on a switch/router. |
| **IEC C13 AU kettle lead** | Laser mains power (IEC C14 inlet on laser) | ~AU$5–10 | Jaycar, Officeworks | Standard PC power cable, AU 240V plug. |
| **Spare USB-C cables** | ESP32 power (can use phone chargers) | ~AU$5 | Anywhere | 5V 2A USB bricks (phone chargers OK). |
| **USB HID relay or ESP32 relay** (if smoke is mains-switched only) | Trigger smoke bursts from Pi | ~AU$10–30 | AliExpress | **Mains-rated SSR or relay in an enclosure.** Do NOT switch 240V with toy 5V relay modules. See Risks. |

### Do NOT Buy (Wrong Path / Already Covered)

| Item | Why Skip |
|---|---|
| **SoundSwitch Micro DMX / Control One** | VID/PID locked to Engine DJ decks. We're using Pi + StageLinQ, not Engine Lighting firmware. Waste of AU$64–429. |
| **Gledopto USB LED controller** | Closed protocol. We have ESP32 + WLED + SP901E. |
| **XIAO ESP32-C6** | WLED unsupported (as of Sep 2026). Stick with WROOM-32 or S2/S3. |
| **Analog Magic Home 5V 30m USB strips** | Analog RGB (not addressable). We have WS2815 digital. |
| **Blue I2C level shifter modules (BSS138)** | Wrong protocol (I2C, not SPI). Use SP901E or 74AHCT125. |

---

## Power Budget

### 12V Rails (WS2815 Strips)

| Strip | Length | LEDs | Full White Current (40mA/LED) | Brick Spec | Margin |
|---|---|---|---|---|---|
| Strip 1 (Stage L or R) | 5m | 300 | 300 × 40mA = 12A | 12V 10A brick | **Overspec'd by 20%.** Cap WLED brightness to ~80% or inject both ends. |
| Strip 2 (Stage R or Backdrop) | 5m | 300 | 12A | 12V 10A brick | Same. |

**Mitigation:** Power injection both ends of each 5m strip (solder 12V+GND at start + end). WLED brightness limit 50–80% for night one (full white RGB is worst case; colours are 1/3 current). 60 LED/m is dense; 30/m would've been safer, but two bricks + injection + brightness cap = doable.

### 5V / USB (ESP32s)

| Device | Current | Source |
|---|---|---|
| ESP32-WROOM-32 (each) | ~500mA (WiFi active) | USB-C phone charger (5V 2A) |

### 240V Mains (Laser, Smoke, Pi)

| Device | Power | Plug |
|---|---|---|
| ALIEN SLP-RGB500 laser | ~50–80W (guess, LED pumps + scanner galvos) | IEC C13 AU kettle lead |
| Raspberry Pi 4B | ~15W (USB-C PD 5V 3A official PSU) | AU 240V → USB-C brick |
| Smoke machine (if owned) | ~400–1000W (heater element) | AU 240V mains, direct or relay-switched |

**Total 240V load:** ~500W + smoke (if used). Standard AU 10A circuit (2400W) is fine.

---

## Pi 4B Setup

### Network Config

1. **Ethernet to decks:** Pi eth0 → gigabit switch ← Engine DJ decks + mixer. StageLinQ discovery is UDP 51337 broadcast on LAN. Decks get DHCP or static 169.254.x.x / 192.168.x.x. Pi needs to be on the same L2 network.
2. **WiFi to WLED ESP32s (or second ethernet NIC):** Pi wlan0 as AP (hostapd) or client on separate WiFi network. If venue has shit WiFi, USB gigabit adapter for a second wired network to ESP32s (WT32-ETH01 boards if you want Ethernet WLED endpoints, but WROOM + WiFi is simpler for weekend v1).
3. **Test:** `ping` deck IPs. Run Mixboard or `stagelinq-discover` CLI to confirm decks appear.

### OS / Packages

- **Raspberry Pi OS Lite (64-bit, Bookworm 2024+):** headless, SSH enabled, `pi` user or custom.
- **Packages:**
  ```bash
  sudo apt update && sudo apt install -y \
    python3 python3-pip python3-venv git \
    nodejs npm \
    libusb-1.0-0-dev libudev-dev \
    bluez bluez-tools python3-bluez \
    screen tmux
  ```
- **Python venv:**
  ```bash
  python3 -m venv ~/rave-cave-env
  source ~/rave-cave-env/bin/activate
  pip install pyserial pyusb requests pyyaml bleak
  ```
- **Node (if using chrisle/StageLinq):**
  ```bash
  npm install -g pnpm
  git clone https://github.com/chrisle/StageLinq.git
  cd StageLinq && pnpm install
  ```

### USB-DMX on Linux (Caveats)

- **FTDI FT232-based dongles:** Linux kernel `ftdi_sio` driver claims them as serial ports (`/dev/ttyUSB0`). QLC+ and Python `pyserial` can open them at 250kbaud (DMX512 baud rate). **This works.**
- **CH340 / random Ali chipsets:** Flaky. Prefer FT232 in the listing.
- **udev rules:** Add `pi` user to `dialout` group:
  ```bash
  sudo usermod -a -G dialout pi
  ```
  Logout/login or reboot.
- **Test:** Plug in USB-DMX, `ls /dev/ttyUSB*`. Should see `/dev/ttyUSB0`. Python:
  ```python
  import serial
  dmx = serial.Serial('/dev/ttyUSB0', baudrate=250000, stopbits=2)
  dmx.write(b'\x00' + bytes([255, 0, 0] + [0]*9))  # Ch1-3 = R255 G0 B0 (red), rest off
  ```

### StageLinQ Client Test

1. **Friday night:** Decks on, Pi on same switch.
2. **Run Mixboard (GUI on laptop):** https://github.com/LaokeQwQ/Mixboard — download AppImage, run on a laptop plugged into the same switch. Should see decks appear, StateMap/BeatInfo live.
3. **OR CLI (Pi SSH):**
   ```bash
   cd StageLinq
   node examples/discovery.js  # Should print deck IPs
   node examples/statemap.js <DECK_IP>  # Stream play state, BPM, faders
   ```
4. **Capture JSON Friday night:** Run a track, dump StateMap + BeatInfo to a file. That's your session zero data structure.

---

## Endpoints

### WLED on ESP32-WROOM-32

**Setup (Friday night per ESP32):**

1. **Flash WLED:** https://install.wled.me/ — Chrome/Edge, select ESP32, flash latest stable (0.14.x+ or 0.15.x).
2. **Connect to WLED AP:** SSID `WLED-AP`, password `wled1234`. Open http://4.3.2.1.
3. **WiFi config:** Join Pi AP or venue network. Note IP (set static if possible).
4. **LED Settings:**
   - GPIO: 2 or 16 (common ESP32 pins; check your devkit pinout).
   - Count: 300 (5m × 60 LED/m).
   - Type: WS281x (WS2815 is WS281x-compatible).
   - Colour order: GRB or RGB (test, most WS2815 is GRB).
5. **Sync Interfaces:**
   - **DDP enabled** (port 4048, simpler than Art-Net for this use case).
   - OR **Art-Net enabled**, Universe 0 (L strip) and Universe 1 (R strip), start address 1.
6. **Segments:** If both strips are on one ESP32, define two segments (0–299 = strip 1, 300–599 = strip 2). If separate ESP32s (recommended), one strip per board.

**SP901E Wiring (per strip):**

```
ESP32 GPIO (3.3V) ---> SP901E Data IN (isolated, 3.3V tolerant)
12V brick (+) -------> SP901E 12V+ (powers SP901E + feeds strip)
12V brick (-) -------> SP901E GND + ESP32 GND (common ground)
SP901E Data OUT (5V) -> WS2815 Data IN (strip pin DI)
SP901E 12V OUT ------> WS2815 12V+ (strip pin +12V, inject both ends)
SP901E GND OUT ------> WS2815 GND (strip pin GND, inject both ends)
```

**74AHCT125 Backup (if no SP901E):**

```
ESP32 3.3V ----> (nothing to 74AHCT125 input; it's 3.3V tolerant)
ESP32 GPIO ----> 74AHCT125 pin 1A (input)
5V rail -------> 74AHCT125 VCC (pin 14, NOT 12V!)
GND -----------> 74AHCT125 GND (pin 7) + ESP32 GND + 5V rail GND
74AHCT125 1Y (output, pin 3) -> WS2815 Data IN
WS2815 12V+ <---- 12V brick (+)
WS2815 GND <----- 12V brick (-) = common GND
```

**5V rail:** Buck converter (12V → 5V) or separate 5V PSU. Do NOT connect WS2815 12V to 74AHCT125 VCC (will fry the chip).

**DDP from Pi:**

```python
import socket
# DDP header: 0x01 (version), channel, control, data
# Example: set all 300 LEDs to RGB (255, 0, 0) = red
pixels = [255, 0, 0] * 300  # 900 bytes
sock = socket.socket(socket.AF_INET, socket.SOCK_DGRAM)
sock.sendto(bytes([0x01, 0x00, 0x00]) + bytes(pixels), ('WLED_IP', 4048))
```

### ALIEN SLP-RGB500 Laser (10ch DMX)

**DMX Channels (typical for cheap RGB lasers; confirm with manual if seller provides one):**

| Ch | Function | Values |
|----|---|---|
| 1 | Mode | 0–49: off, 50–99: static, 100–149: patterns, 150–199: sound, 200–255: auto |
| 2 | Pattern / Gobo | 0–255: pattern index (if mode = pattern) |
| 3 | Strobe | 0: off, 1–255: strobe speed |
| 4 | Red | 0–255: red LED brightness |
| 5 | Green | 0–255: green LED brightness |
| 6 | Blue | 0–255: blue LED brightness |
| 7 | X Position | 0–255: horizontal galvo angle |
| 8 | Y Position | 0–255: vertical galvo angle |
| 9 | X Speed | 0–255: horizontal scan speed |
| 10 | Y Speed | 0–255: vertical scan speed |

**Patch as DMX address 1 (or 11 if WLED is using 1–10, but WLED is DDP not DMX here).**

**Python DMX send:**

```python
import serial
dmx = serial.Serial('/dev/ttyUSB0', baudrate=250000, stopbits=2)
# DMX frame: start byte 0x00 + 512 channels
frame = [0] * 513
frame[0] = 0  # DMX start code
# Channels 1–10: laser
frame[1] = 100  # Mode = pattern
frame[2] = 5    # Pattern 5
frame[3] = 0    # No strobe
frame[4] = 255  # Red full
frame[5] = 0    # Green off
frame[6] = 255  # Blue full = magenta
frame[7] = 128  # X centre
frame[8] = 128  # Y centre
frame[9] = 50   # X speed slow
frame[10] = 50  # Y speed slow
dmx.write(bytes(frame[:11]))  # Send start + 10 channels
```

**Safety (brief, not a lecture):** If 500mW RGB is real, it's Class 3B or 4 (combined wavelengths). AU entertainment use typically requires a laser safety officer or WorkSafe notification. For weekend v1: **aerials/wall/ceiling patterns only, never audience scanning.** Mount laser at back of stage pointing up/away, or at ceiling. Test in a dark room before the show. If it burns paper instantly, it's Class 4; get qualified sign-off or don't use it. Budget RGB lasers often overrate (actually 100–200mW), but don't assume.

### 103cm RGB CCT Floor Lamp Tubes (BLE, Stretch Goal)

**Protocol:** Bluetooth Low Energy. Investigated from the Mac with `bleak`; full notes in [docs/fixtures/tubes.md](../fixtures/tubes.md).

- The tubes are STAR LIGHTING `XSD-DD15` and advertise as `STARLIGHT` (a generic cheap LED BLE controller) and `TUYA_` (Tuya/Smart Life BLE).
- `STARLIGHT` connects without pairing. Commands go to characteristic `FFF3` (service `FFF0`); replies come back on `FFF4`.
- Common LED command packets were accepted without error, but **none has been visually confirmed yet**. Next step is to rerun a solid-colour test while watching the tube, then try other packet families or sniff the official app.
- `TUYA_` would need Smart Life pairing and a local key, so it is the fallback path.

**Reality check:** The tubes are still a stretch goal. They're not DMX or DDP, so they don't integrate cleanly. Hack on them AFTER the core rig (WLED + laser) is live.

### Smoke Machine (Mains Relay, Optional)

**If smoke machine has DMX XLR:** Patch it on the same USB-DMX universe (e.g. Ch 21, usually 1 channel: 0–127 off, 128–255 on). Easy.

**If smoke machine is just a power switch (240V mains):**

1. **USB HID relay (safe, enclosed):** AliExpress "USB relay module 240V" in a proper enclosure. Example: https://www.aliexpress.com/item/... (search "USB 5V relay 240V mains"). Pi Python:
   ```python
   import serial
   relay = serial.Serial('/dev/ttyUSB1', 9600)  # HID relay on another USB port
   relay.write(b'\xA0\x01\x01\xA2')  # Example: relay ON (check manual)
   ```

2. **ESP32 + mains SSR (DIY, needs enclosure):**
   ESP32 GPIO → solid-state relay (SSR) rated 240V 10A (Fotek SSR-25DA or similar) → smoke machine mains. **CRITICAL: SSR in an IP-rated enclosure, strain relief, fused.** Do NOT use 5V toy relay modules (blue boards) for mains; they're not isolated enough. If unsure, don't switch mains yourself.

**Reality check:** If the smoke machine is DMX, great. If it's mains-switched, decide Saturday if you have time to build a safe relay. Otherwise, trigger it manually.

---

## Weekend Build Order

### Friday Night (Setup + Session Zero)

1. **Inventory check:**
   - Pi 4B, SD card with Raspberry Pi OS, SSH enabled, ethernet cable.
   - Decks, mixer, gigabit switch, all on same LAN.
   - ESP32s × 2, USB-C cables, 5V phone chargers.
   - WS2815 strips × 2 (still in packaging), 12V 10A bricks × 2, SP901E × 2.
   - ALIEN laser, IEC C13 AU kettle lead, USB-DMX stick, 3-pin DMX cable.
   - Laptop for Mixboard.

2. **Pi network:**
   - Plug Pi eth0 into switch. SSH in, `ip addr`, confirm 192.168.x.x or 169.254.x.x.
   - Install packages (see Pi 4B Setup above).
   - Clone StageLinq repo (TypeScript, https://github.com/chrisle/StageLinq) OR PyStageLinQ if you prefer Python.

3. **StageLinQ discovery test:**
   - Decks on, playing a track.
   - Run Mixboard on laptop (same switch): https://github.com/LaokeQwQ/Mixboard
   - Should see decks appear, StateMap (BPM, play state, faders), BeatInfo (beat position).
   - **Dump JSON:** Capture StateMap + BeatInfo to a file while mixing. That's your data structure. Open it, read it, understand it.

4. **Flash WLED on ESP32s:**
   - https://install.wled.me/ — USB-C to laptop, flash both boards.
   - Connect to each WLED AP (SSID `WLED-AP`), configure WiFi (join Pi network or venue WiFi), note IPs.
   - LED Settings: GPIO 2 or 16, 300 LEDs, WS281x, GRB colour order.
   - Sync: DDP enabled, port 4048.
   - **DO NOT WIRE STRIPS YET.** Test DDP from Pi (Python script) with a short LED segment or just WLED web UI (confirm it responds).

5. **USB-DMX test:**
   - Plug USB-DMX into Pi, `ls /dev/ttyUSB0`.
   - Python script: send a DMX frame (all zeros except Ch1=255, Ch2=0, Ch3=0 for red). Don't connect laser yet; just confirm serial port opens.

6. **Session zero summary:** By midnight Friday, you have:
   - Pi seeing decks via StageLinQ (JSON dumps of BPM, faders, beat).
   - WLED responding to DDP from Pi (test with 10 LEDs red → green → blue).
   - USB-DMX serial port opens (`/dev/ttyUSB0`).
   - You've read the StageLinq JSON structure and know where BPM, beat-in-bar, fader, crossfader live.

### Saturday (Wire Strips + Laser, Code Generator v0)

1. **Wire WS2815 strips (one at a time):**
   - Strip 1: SP901E data IN from ESP32 GPIO 2, 12V brick to SP901E 12V+GND, SP901E data OUT to strip DI, 12V OUT to strip +12V (inject both ends: solder wires at 0m and 5m to +12V/GND from brick).
   - **Test:** WLED web UI → set strip solid red. If it lights, good. If flicker, check common ground (ESP32 GND = 12V brick GND). If wrong colours, swap GRB to RGB in WLED.
   - Repeat for Strip 2 + ESP32 #2.

2. **Mount strips (quick for testing):**
   - Gaff tape to a ladder or wall. L strip = stage left, R strip = stage right or backdrop. Not permanent yet; just get them visible.

3. **Wire laser:**
   - IEC C13 AU kettle lead to laser IEC C14 inlet, plug into 240V mains.
   - 3-pin DMX cable: USB-DMX (on Pi) → laser XLR IN.
   - **Power on laser.** It should boot (fans spin, maybe a default pattern).
   - **DO NOT LOOK INTO BEAM.** Point it at a wall/ceiling before powering on.

4. **Test laser DMX:**
   - Python script: send Ch1=100 (pattern mode), Ch4=255, Ch5=0, Ch6=0 (red), Ch7=128, Ch8=128 (centre). Laser should project a red pattern on the wall.
   - Adjust Ch2 (pattern index), Ch7/Ch8 (position). Confirm control works.

5. **Code generator v0 (beat-in-bar chase):**
   - **Input:** StageLinq BeatInfo (beat position 0.0–1.0 within 4-beat bar).
   - **Output:** DDP to WLED (300 LEDs), DMX to laser.
   - **Algorithm:** 
     - Beat 1 (0.0–0.25): LEDs 0–74 red, rest off. Laser red, pattern A.
     - Beat 2 (0.25–0.5): LEDs 75–149 green. Laser green.
     - Beat 3 (0.5–0.75): LEDs 150–224 blue. Laser blue.
     - Beat 4 (0.75–1.0): LEDs 225–299 white. Laser white (R+G+B).
   - **Code (pseudocode):**
     ```python
     while True:
         beat_pos = stagelinq.get_beat_position()  # 0.0–1.0
         segment = int(beat_pos * 4)  # 0, 1, 2, 3
         pixels = [(0,0,0)] * 300
         start = segment * 75
         end = start + 75
         color = [(255,0,0), (0,255,0), (0,0,255), (255,255,255)][segment]
         for i in range(start, end):
             pixels[i] = color
         send_ddp(pixels, WLED_IP)
         send_dmx(laser_channels_for_color(color))
         time.sleep(0.02)  # 50 Hz refresh
     ```
   - **Test:** Play a track on deck. Watch strip chase across 4 beats, laser change colour. If it's in sync, you've won.

6. **Iterate:** Adjust thresholds, add fader brightness (StateMap deck fader * pixel brightness), crossfader L/R (if xfader left, L strip brighter; if right, R strip brighter).

### Sunday (Drop Detection, Full Rig, Vibe Coding)

1. **Drop detection (waveform energy):**
   - StageLinq FileTransfer: pull track waveform (3-band zlib blob).
   - Decompress, parse low/mid/high energy per 0.1 sec slice.
   - Sliding window: avg mid+high over last 16 bars. If current bar is <30% of avg (energy drop = "build"), set a flag. If next bar spikes >150% (drop), trigger: all LEDs white strobe, laser fast X/Y scan, smoke burst (if wired).
   - **Code:** Cache waveforms per track (StageLinq track ID). On track load, parse waveform, find drop timestamps. On playback, if `current_time` matches a drop, trigger effect.

2. **Crossfader L/R segments:**
   - StateMap crossfader position: -1.0 (full left), 0.0 (centre), +1.0 (full right).
   - Map L strip brightness to `1.0 - (crossfader + 1.0) / 2.0` (full left = 1.0, full right = 0.0).
   - R strip brightness to `(crossfader + 1.0) / 2.0`.
   - Test: Mix two tracks, move crossfader, L/R strips should fade opposite directions.

3. **Full rig run-through:**
   - Decks on, Pi StageLinQ client running, WLED + laser live.
   - Play a set: beatmatched mix, crossfader transitions, drop on track 2.
   - Confirm: Strips chase on beat, brightness follows faders, crossfader fades L/R, drop triggers white strobe + laser madness.

4. **Vibe coding:**
   - Saturday afternoon + Sunday = tune thresholds, add colour palettes (BPM < 120 = warm colours, BPM > 130 = cool), hotcue jump re-sync, loop detection (StateMap loop active → freeze chase pattern), EQ filter → colour shift (low-pass filter active → red shift).
   - **This is the fun part.** No autoscript. You have BPM, beat, faders, waveform, crossfader. Code whatever feels right.

5. **Optional stretch goals (if time):**
   - BLE tubes: connect to `STARLIGHT`, write colour to `FFF3` (see docs/fixtures/tubes.md). If it works, add them as ambient fill. If not, skip.
   - Smoke relay: if DMX or safe mains relay is wired, trigger on drops (1 sec burst).

6. **Final test:** Full set, no laptop, Pi runs headless. Confirm it's stable for 30 min (no crashes, no desync).

---

## Risks

| Risk | Impact | Mitigation |
|---|---|---|
| **StageLinQ firmware drift** | Medium: Engine OS updates may break protocol | chrisle/StageLinq is actively maintained (2024). Pin Engine OS version if possible. Test Friday night; if decks aren't broadcasting, check firmware version (old OS may predate StageLinQ). |
| **Cheap USB-DMX chipset on Pi** | Medium: non-FTDI may not enumerate or drop frames | Buy FT232-based dongles (search "FTDI USB DMX"). Test Friday with `ls /dev/ttyUSB0`. If CH340, it may work but flaky. |
| **Laser safety (Class 3B/4)** | **HIGH if 500mW is real:** eye damage, AU legal liability | **Aerials/wall/ceiling only.** Never audience scan. Mount at back pointing up, or at ceiling. If it burns paper, it's Class 4; get a laser safety officer or don't use it. Budget lasers often overrate (100–200mW real), but don't gamble. One paragraph, not a lecture, but this is serious. |
| **BLE tubes reverse-engineering** | Low: may not finish in a weekend | Connection works and the command channel is known (see docs/fixtures/tubes.md); the colour packet is still unconfirmed. Skip if it's not working by Sunday lunch. Core rig (WLED + laser) is enough. |
| **Mains relay for smoke** | **HIGH if DIY mains wiring is unsafe:** fire, electrocution | If machine is mains-switched: buy a USB HID relay in an enclosure OR an ESP32 + **mains-rated SSR (240V 10A) in an IP-rated box** with strain relief and fuse. Do NOT use 5V toy relay modules (blue boards) for 240V. If unsure, trigger smoke manually or skip. |
| **WS2815 60 LED/m power draw** | Medium: 12A per 5m at full white exceeds 10A brick | Power injection both ends (solder +12V/GND at 0m and 5m from brick). WLED brightness cap 50–80%. Full white RGB is worst case; colours (R or G or B alone) are 1/3 current. Don't run full white for more than a few seconds. |
| **IP67 soldering in rain** | Low if indoor; HIGH if outdoor | Strips are IP67 (splash-proof), but solder joints at injection points are NOT unless heat-shrunk. If outdoor or near drinks, heatshrink all joints + silicone. If indoor, electrical tape is OK for weekend v1. |
| **ESP32 3.3V → WS2815 5V data** | High: no level shift = flicker / no response | SP901E is the level shifter (12V powered, 3.3V input, 5V output). OR 74AHCT125 (VCC = 5V, NOT 12V). Test Friday with 10 LEDs before wiring 300. |
| **WLED WiFi dropouts** | Medium: UDP DDP packets lost = stuttering | Pi + ESP32 on same AP (Pi as hostapd if venue WiFi is shit). OR WT32-ETH01 boards (Ethernet WLED) if you want 100% reliability (AU$15–20 per board, need CAT5 runs). WiFi is fine for weekend v1 if signal is strong. |
| **StageLinQ discovery fails (VLAN / firewall)** | High: no data = no sync | Decks + Pi must be on same L2 network (same switch, no router/firewall between). Test with Mixboard Friday. If corporate venue network blocks UDP 51337, bring your own gigabit switch (AU$20). |

---

## Open Questions for Jonathan

| Question | Why It Matters |
|---|---|
| **Exact Engine DJ hardware model?** | Confirm StageLinQ support (SC5000, SC6000, Prime 4, Prime Go, SC Live all have it; older models may not). Also: where does USB-DMX plug? (Not needed here, but good to know deck setup.) |
| **Show date?** | AliExpress WS2815 strips + laser shipped yet? If show is <2 weeks, check tracking. If late, pivot to local LED strip (K&A Electronics, more expensive but in stock). |
| **Indoor or outdoor?** | WS2815 IP67 is splash-proof, not submersion. If outdoor + rain, all solder joints need heatshrink + silicone. If indoor, electrical tape is OK. |
| **Backdrop dimensions?** | 10m WS2815 (2× 5m rolls) = 600 LEDs total. What's the layout? Stage left 5m vertical, stage right 5m vertical? Or L/R 2.5m each + 5m backdrop horizontal? Affects segment mapping. |
| **Smoke machine: DMX or mains-switched?** | If DMX XLR IN on back, easy (same USB-DMX universe). If just a power switch, need mains relay (see Risks). What make/model? |
| **Floor lamp tubes: BLE, IR, or Tuya?** | Answered: BLE. They expose a generic `STARLIGHT` LED controller plus a `TUYA_` device. See docs/fixtures/tubes.md. Open item is confirming which colour packet works. |
| **Pi 4B: how much RAM?** | 2GB is enough; 4GB/8GB is overkill but fine. Confirm you have official 5V 3A USB-C PSU (cheap PSUs brownout under WiFi load). |
| **Already own gigabit switch?** | If decks + Pi are on separate networks (e.g. deck WiFi, Pi ethernet), StageLinQ won't work. Need them on one LAN. Do you have a switch or need to buy one (AU$20)? |
| **Already own USB-DMX?** | If yes, what chipset (FT232, CH340, PL2303)? If no, buy FT232-based (~AU$30 Ali). |

---

## References

- **StageLinQ protocol (fullest library, TypeScript):** https://github.com/chrisle/StageLinq (Discovery, StateMap, BeatInfo, FileTransfer, waveform decode)
- **StageLinQ protocol notes:** https://github.com/honusz/stagelinq-js/blob/main/docs/PROTOCOL.md
- **PyStageLinQ (Python, StateMap only):** https://github.com/Jaxc/PyStageLinq
- **Mixboard (live dashboard, debug tool):** https://github.com/LaokeQwQ/Mixboard
- **WLED install:** https://install.wled.me/
- **WLED DDP protocol:** https://github.com/Aircoookie/WLED/wiki/UDP-Realtime-Control (DDP = Distributed Display Protocol, simpler than Art-Net for point-to-point)
- **SP901E pixel amp (AliExpress):** Search "SP901E 2048 pixel SPI amplifier" (verify 12V input, WS2815 support)
- **WS2815 datasheet:** https://www.led-stuebchen.de/download/WS2815_V10_EN.pdf (12V, dual-data, SPI-compatible)
- **74AHCT125 datasheet:** https://www.ti.com/lit/ds/symlink/sn74ahct125.pdf (quad buffer, 5V VCC, 3.3V input tolerant)
- **Engine DJ Engine OS:** https://enginedj.com/ (confirm your deck model supports StageLinQ)

---

**Done when:** Friday night StageLinQ is live, Saturday strips + laser respond to beats, Sunday drops trigger white strobes and you're laughing. Vibe-code it, don't puppet it.

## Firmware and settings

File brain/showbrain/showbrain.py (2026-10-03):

#!/usr/bin/env python3
"""Sektor5 show brain: read-ahead lighting driven by the decks.

Inputs:  deckdash feed (UDP 127.0.0.1:9100: beats + 20 Hz status) and
         per-track timelines (http://127.0.0.1:8080/api/timeline/N).
Outputs: DDP frames to every configured fixture (WLED tube, HUB75 panel...).
Control: Commander page + JSON API on :8090.

Scene flow (see docs/show-engine.md):
  IDLE -> INTRO/GROOVE <-> BREAKDOWN -> BUILD (-> HOLD while looping)
       -> PRE-DROP (blackout, last beat) -> DROP -> GROOVE ... -> OUTRO

    python3 brain/showbrain/showbrain.py [config.json]
"""
import bisect
import collections
import colorsys
import json
import math
import random
import socket
import sys
import threading
import time
import urllib.request
from http.server import BaseHTTPRequestHandler, ThreadingHTTPServer
from pathlib import Path

import numpy as np

from ddp import DDPOutput
import s5auth
from dmx import UDMX
import looks

HERE = Path(__file__).parent
import envcfg
envcfg.load_env()
CONFIG = json.loads(envcfg.expand((Path(sys.argv[1]) if len(sys.argv) > 1 else HERE / "config.json").read_text()))


# ---------------------------------------------------------------- deck feed

class Decks:
    """Latest deck status and beat events from deckdash, plus track timelines."""

    def __init__(self):
        self.lock = threading.Lock()
        self.status = {}        # player -> dict (+ "_rx" local receive time)
        self.master = 0
        self.beats = {}         # player -> (rx_time, bwb, bpm)
        self.mixer = None       # latest DJM message from brain/mixer (+ "_rx")
        self.timelines = {}     # ref -> timeline dict
        self.fetching = set()
        threading.Thread(target=self._listen, daemon=True).start()

    def _listen(self):
        s = socket.socket(socket.AF_INET, socket.SOCK_DGRAM)
        s.bind(("127.0.0.1", CONFIG.get("feed_port", 9100)))
        while True:
            msg = json.loads(s.recv(65536))
            now = time.time()
            with self.lock:
                if msg["t"] == "status":
                    self.master = msg.get("master", 0)
                    seen = set()
                    for p in msg["players"]:
                        p["_rx"] = now
                        self.status[p["n"]] = p
                        seen.add(p["n"])
                        ref = p.get("ref")
                        if ref and ref not in self.timelines and ref not in self.fetching:
                            self.fetching.add(ref)
                            threading.Thread(target=self._fetch, args=(p["n"], ref), daemon=True).start()
                    for n in list(self.status):
                        if n not in seen and now - self.status[n]["_rx"] > 3:
                            del self.status[n]
                elif msg["t"] == "beat":
                    self.beats[msg["player"]] = (now, msg["bwb"], msg["bpm"])
                elif msg["t"] == "mixer":
                    msg["_rx"] = now
                    self.mixer = msg

    def _fetch(self, player, ref):
        for _ in range(30):
            try:
                with urllib.request.urlopen(f"http://127.0.0.1:8080/api/timeline/{player}", timeout=3) as r:
                    t = json.loads(r.read())
                if t.get("ref") == ref:
                    with self.lock:
                        self.timelines[ref] = t
                        self.fetching.discard(ref)
                    log(f"timeline: {t.get('title')} - drops at bars {[d['bar'] for d in t.get('drops', [])]}")
                    return
            except Exception:
                pass
            time.sleep(1)
        with self.lock:
            self.fetching.discard(ref)

    def snapshot(self):
        with self.lock:
            return dict(self.status), self.master, dict(self.beats), self.timelines

    def mixer_state(self):
        with self.lock:
            m = self.mixer
        if not m or not m.get("connected") or time.time() - m["_rx"] > 1.0:
            return None
        return m


# ---------------------------------------------------------------- helpers

def log(msg):
    print(time.strftime("%X"), msg, flush=True)


def hsv(h, s=1.0, v=1.0):
    return colorsys.hsv_to_rgb(h % 1.0, max(0.0, min(1.0, s)), max(0.0, min(1.0, v)))


def mix(a, b, t):
    return tuple(x + (y - x) * t for x, y in zip(a, b))


def key_hue(key):
    """Camelot key like '9B' -> hue, so each track gets its own colour."""
    try:
        return ((int(key[:-1]) - 1) / 12 + (0.04 if key[-1] in "Bb" else 0)) % 1.0
    except (TypeError, ValueError):
        return 0.83


# ---------------------------------------------------------------- engine

class Engine:
    def __init__(self, decks):
        self.decks = decks
        self.mode = "auto"              # auto | manual | blackout
        self.follow = 0                 # 0 = auto, else player number
        self.lead_ms = CONFIG.get("lead_ms", 40)
        self.intensity = CONFIG.get("intensity", 0.8)
        self.hold = False
        self.strobe = False
        self.forced = None              # {"kind": "build"|"drop", "player", "start", "drop"} in beats
        # Performance layer (Commander pads), applied on top of the auto show.
        self.strobe_div = 2             # strobe flashes per beat; 0 = free-running 12 Hz
        self.blinder = False            # hold: everything full white
        self.black_hold = False         # hold: momentary blackout
        self.flash_t = 0.0              # tap: white hit decaying over about a beat
        self.look = None                # latched scene: INTRO | GROOVE | BREAKDOWN | DROP
        self.look_t = 0.0
        self.palette_mode = "auto"      # auto (track key) | lock | cycle
        self.palette_hue = 0.83
        self.speed = 1.0                # 0.5 half-time, 1, 2 double-time
        # Mixer reactions (DJM-450 via brain/mixer): bass kill, level, kicks, and mapped MIDI controls.
        self.mixer_react = CONFIG.get("mixer", {}).get("react", True)
        self.bass_was_out = False
        self.fx_active = False          # Beat FX on (needs mixer.midi.fx_on mapped)
        self.filters = {}               # mixer channel -> filter offset -1..1 (needs mixer.midi.chN_filter)
        self.midi_t = 0.0               # newest MIDI message already handled
        self.mix = {}                   # what the mixer is doing now, for the Commander
        # The last few output frames (time, {fixture: preview}), so a viewer polling at 25 Hz still
        # gets every 50 fps frame and can play them back at their real timing (the Stage view).
        self.frames = collections.deque(maxlen=4)
        self.fixture_ctl = {}           # fixture name -> {"on": bool, "level": 0..1}
        # Tap clock: drives the lights when no deck is playing (looks or forced events only).
        self.tap_bpm = 128.0
        self.tap_anchor = self.tap_first = time.time()
        self.taps = []
        self.overrides_path = HERE / "overrides.json"
        try:
            self.overrides = json.loads(self.overrides_path.read_text())
        except (OSError, ValueError):
            self.overrides = {}         # title -> {"skip": [beats], "add": [beats]}
        self.state = {}
        self.sparks = []
        self.last_live = None
        self.frozen_progress = 0.0
        self.playing_since = {}         # player -> time it started playing (for hand-over)
        self.share_smooth = {}          # player -> smoothed share of the mix (from the DJM)
        self.dominant_since = {}        # player -> time its share went above the take-over threshold
        self.live_reason = ""
        self.outro_since = None
        self.last_beat_seen = {}        # player -> rx time of the last beat packet we measured
        self.phase_err = []             # recent (model - packet) errors in ms, for the diagnostic

    # --- position model ------------------------------------------------
    def position(self, p, t):
        """Track position in ms at time t for status p (interpolated while playing)."""
        pos = p.get("pos", -1)
        if pos is None or pos < 0:
            return None
        if p.get("playing"):
            pos += (t - p["_rx"]) * 1000 * (1 + p.get("pitch", 0) / 100)
        return pos

    @staticmethod
    def beat_at(tl, pos):
        """Fractional beat number (1-based) at track position pos, using the beat grid."""
        bm = tl["beatMs"]
        i = bisect.bisect_right(bm, pos)
        if i == 0:
            return 1.0 + (pos - bm[0]) / max(1, bm[1] - bm[0])
        if i >= len(bm):
            return float(len(bm))
        return i + (pos - bm[i - 1]) / max(1, bm[i] - bm[i - 1])

    @staticmethod
    def bar_of(tl, beat):
        fb = tl["barFirstBeat"]
        i = bisect.bisect_right(fb, int(beat))
        bar = max(1, i)
        return bar, int(beat) - fb[bar - 1] + 1    # (bar, beat within bar 1..)

    def section_of(self, p, t, timelines):
        """(section type, beat) for a deck right now, or (None, None) without a timeline."""
        tl = timelines.get(p.get("ref"))
        pos = self.position(p, t)
        if not tl or pos is None:
            return None, None
        beat = self.beat_at(tl, pos)
        sec = next((s for s in tl["sections"] if s["startBeat"] <= beat <= s["endBeat"] + 0.999), None)
        return (sec["type"] if sec else None), beat

    def mixer_pick(self, status, t):
        """Live deck from the DJM's post-fader levels. Returns a player, None (nothing audible),
        or False (no mixer data: fall back to the deck-state rules)."""
        m = self.decks.mixer_state()
        if m is None:
            return False
        cfg = CONFIG.get("mixer", {})
        chmap = {int(k): v for k, v in cfg.get("channels", {"1": 1, "2": 2}).items()}   # mixer ch -> player
        take, hold_s, alpha = cfg.get("takeover_share", 0.7), cfg.get("takeover_s", 2.0), cfg.get("smoothing", 0.15)
        silent = cfg.get("silent_db", -60.0)
        shares = {}
        for ch, player in chmap.items():
            raw = m.get("share", {}).get(f"ch{ch}", 0.0)
            if m.get("channels", {}).get(f"ch{ch}", {}).get("rms_db", -200) < silent:
                raw = 0.0
            prev = self.share_smooth.get(player, raw)
            shares[player] = prev + alpha * (raw - prev)
        self.share_smooth = shares
        if all(v < 0.05 for v in shares.values()):
            self.live_reason = "mixer: nothing audible"
            return self.last_live if self.last_live in status else None
        for player, v in shares.items():
            if v >= take:
                self.dominant_since.setdefault(player, t)
            else:
                self.dominant_since.pop(player, None)
        cur = self.last_live
        for player, since in self.dominant_since.items():
            if player != cur and player in status and t - since >= hold_s:
                self.live_reason = f"mixer: deck {player} holds {shares[player]:.0%} of the mix"
                return player
        if cur in shares and cur in status:
            self.live_reason = f"mixer: staying on deck {cur} ({shares[cur]:.0%})"
            return cur
        best = max(shares, key=shares.get)
        self.live_reason = f"mixer: deck {best} loudest"
        return best if best in status else None

    def live_deck(self, status, master, timelines=None, t=None):
        """Which deck the lights follow. Sticky: cueing or previewing another deck never steals it.

        Priority: manual follow > mixer on-air flags (if a DJM is on the link) > stay on the current
        deck while it plays > hand over when the current deck stops/ends/sits in its outro, or when
        the incoming deck hits a drop while the outgoing one is already in its outro.
        """
        timelines = timelines or {}
        t = t or time.time()
        if self.follow and self.follow in status:
            self.live_reason = "locked in Commander"
            return self.follow
        pick = self.mixer_pick(status, t)
        if pick is not False:
            return pick
        playing = {n: p for n, p in status.items() if p.get("playing")}
        on_air = [n for n, p in playing.items() if p.get("onAir")]
        self.live_reason = "deck state (no mixer data)"
        if on_air:                                   # real fader data wins when we have it
            cur = self.last_live if self.last_live in on_air else on_air[0]
            return cur
        cur = self.last_live
        if cur not in playing or status[cur].get("atEnd"):
            # Current deck stopped: take the deck that has been playing longest.
            if not playing:
                return None
            self.playing_since = {n: v for n, v in self.playing_since.items() if n in playing}
            for n in playing:
                self.playing_since.setdefault(n, t)
            return min(playing, key=lambda n: self.playing_since[n])
        for n in playing:
            self.playing_since.setdefault(n, t)
        for n in list(self.playing_since):
            if n not in playing:
                del self.playing_since[n]
        others = [n for n in playing if n != cur]
        if not others:
            return cur
        sec_cur, _ = self.section_of(status[cur], t, timelines)
        if sec_cur == "outro":
            self.outro_since = self.outro_since or t
        else:
            self.outro_since = None
        for n in others:
            sec_in, _ = self.section_of(status[n], t, timelines)
            # Incoming deck drops while outgoing is winding down: follow the drop.
            if sec_in == "drop" and sec_cur in ("outro", None):
                return n
            # Outgoing has been in its outro for 16+ s with the new deck running for 30+ s: mix is done.
            if self.outro_since and t - self.outro_since > 16 and t - self.playing_since.get(n, t) > 30:
                return n
        return cur

    # --- scene decision --------------------------------------------------
    def decide(self, t):
        status, master, beats, timelines = self.decks.snapshot()
        live = self.live_deck(status, master, timelines, t)
        ctx = {"t": t, "live": live, "scene": "IDLE", "hue": 0.83, "frac": 0.0, "bwb": 1, "bar": 0,
               "beat": 0.0, "progress": 0.0, "since_drop": 0.0, "beats_to_drop": None, "title": None,
               "bpm": 0.0, "section": None, "next_drop_bar": None,
               "section_progress": 0.0, "energy": 0.5}
        if live is None:
            self.last_live = None
            if self.look or (self.forced and self.forced["player"] is None):
                return self._free(ctx, t)
            return ctx
        if live != self.last_live:
            if self.last_live is not None:
                log(f"live deck -> {live}")
            self.last_live = live
            self.forced = None
        p = status[live]
        ctx.update(title=p.get("title"), bpm=p.get("bpm", 0), hue=key_hue(p.get("key")))
        tl = timelines.get(p.get("ref"))
        pos = self.position(p, t + self.lead_ms / 1000)

        if tl is None or pos is None:
            # No timeline yet: follow beat events only.
            b = beats.get(live)
            if b:
                period = 60 / max(1, b[2])
                ctx["frac"] = ((t + self.lead_ms / 1000 - b[0]) / period) % 1.0
                ctx["bwb"] = b[1]
            ctx["scene"] = "GROOVE" if p.get("playing") else "PAUSED"
            return ctx

        beat = self.beat_at(tl, pos)
        bar, bwb = self.bar_of(tl, beat)
        ctx.update(beat=beat, frac=beat % 1.0, bar=bar, bwb=bwb)

        # Diagnostic: at each real beat packet, where did the position model think we were?
        b = beats.get(live)
        if b and p.get("playing") and b[0] != self.last_beat_seen.get(live):
            self.last_beat_seen[live] = b[0]
            mpos = self.position(p, b[0])
            if mpos is not None:
                ph = self.beat_at(tl, mpos) % 1.0
                err = (ph if ph < 0.5 else ph - 1.0) * 60000 / max(1.0, b[2])
                self.phase_err = (self.phase_err + [err])[-32:]
        cal = self.overrides.get("_calibration", [])
        if cal:
            ds = sorted(c["delta_beats"] for c in cal)
            ctx["calibration"] = {"marks": len(ds), "median_delta_beats": ds[len(ds) // 2]}
        if self.phase_err:
            srt = sorted(self.phase_err)
            ctx["phase_err_ms"] = round(srt[len(srt) // 2], 1)
        if not p.get("playing"):
            ctx["scene"] = "PAUSED"
            return ctx

        section = next((s for s in tl["sections"] if s["startBeat"] <= beat <= s["endBeat"] + 0.999), None)
        ctx["section"] = section["type"] if section else None
        if section:
            span = max(1.0, section["endBeat"] + 1 - section["startBeat"])
            ctx["section_progress"] = max(0.0, min(1.0, (beat - section["startBeat"]) / span))
        en = tl.get("energy") or []
        ctx["energy"] = en[bar - 1] / 100 if 0 < bar <= len(en) else 0.5
        drops = self.drops_for(p.get("title"), tl)
        ctx["drops"] = [{"bar": d["bar"], "manual": bool(d.get("manual"))} for d in drops]

        # Forced events from the Commander take priority.
        if self.forced and self.forced["player"] == live:
            f = self.forced
            if f["kind"] == "build" and beat < f["drop"]:
                return self._build(ctx, beat, f["start"], f["drop"], p)
            if beat - f["drop"] < CONFIG.get("drop_bars", 16) * 4:
                return self._drop(ctx, beat - f["drop"])
            self.forced = None

        if self.mode == "manual":
            ctx["scene"] = "GROOVE"
            return ctx

        nxt = next((d for d in drops if d["beat"] > beat - CONFIG.get("drop_bars", 16) * 4), None)
        if nxt:
            ctx["next_drop_bar"] = nxt["bar"]
            if beat < nxt["beat"]:
                ctx["beats_to_drop"] = nxt["beat"] - beat
            if nxt["buildStartBeat"] <= beat < nxt["beat"]:
                return self._build(ctx, beat, nxt["buildStartBeat"], nxt["beat"], p)
            if nxt["beat"] <= beat:
                return self._drop(ctx, beat - nxt["beat"])
        ctx["scene"] = {"intro": "INTRO", "breakdown": "BREAKDOWN", "outro": "OUTRO"}.get(ctx["section"], "GROOVE")
        return ctx

    def drops_for(self, title, tl):
        """Timeline drops with this track's saved overrides applied."""
        ov = self.overrides.get(title or "", {}) if title != "_calibration" else {}
        skip = set(ov.get("skip", []))
        drops = [d for d in tl["drops"] if d["beat"] not in skip]
        fb = tl["barFirstBeat"]
        for beat in ov.get("add", []):
            bar = max(1, bisect.bisect_right(fb, beat))
            start_bar = max(1, bar - 8)
            drops.append({"bar": bar, "beat": beat, "ms": 0, "confidence": 1.0, "cue": False, "manual": True,
                          "buildStartBar": start_bar, "buildStartBeat": fb[start_bar - 1]})
        return sorted(drops, key=lambda d: d["beat"])

    def save_overrides(self):
        self.overrides_path.write_text(json.dumps(self.overrides, indent=1))

    def _build(self, ctx, beat, start, drop, p):
        ctx["beats_to_drop"] = drop - beat
        if drop - beat <= 1.0:
            ctx["scene"] = "PREDROP"
            return ctx
        progress = (beat - start) / max(1.0, (drop - 1) - start)
        if p.get("looping") or self.hold:
            ctx["scene"] = "HOLD"
            progress = self.frozen_progress
        else:
            self.frozen_progress = progress
            ctx["scene"] = "BUILD"
        ctx["progress"] = max(0.0, min(1.0, progress))
        return ctx

    def _drop(self, ctx, since):
        ctx["scene"] = "DROP"
        ctx["since_drop"] = since
        return ctx

    # --- tap clock (no deck playing) --------------------------------------
    def free_beat(self, t):
        """1-based fractional beat on the tap clock; beat 1 is the anchor (a downbeat)."""
        return (t - self.tap_anchor) * self.tap_bpm / 60 + 1

    def _free(self, ctx, t):
        beat = self.free_beat(t + self.lead_ms / 1000)
        ctx.update(scene="GROOVE", beat=beat, frac=beat % 1.0, bar=int((beat - 1) // 4) + 1,
                   bwb=int(beat - 1) % 4 + 1, bpm=self.tap_bpm, title="Tap clock", free=True,
                   energy=0.6, section_progress=0.5)
        f = self.forced
        if f and f["player"] is None:
            if f["kind"] == "build" and beat < f["drop"]:
                return self._build(ctx, beat, f["start"], f["drop"], {})
            if beat - f["drop"] < CONFIG.get("drop_bars", 16) * 4:
                return self._drop(ctx, beat - f["drop"])
            self.forced = None
        return ctx

    # --- performance layer -------------------------------------------------
    def shape(self, ctx, t):
        """Apply the Commander's latched look, speed and palette to the auto show's ctx."""
        if self.look and not self.forced:
            ctx["scene"] = self.look
            if self.look == "DROP":
                ctx["since_drop"] = (t - self.look_t) * max(60.0, ctx.get("bpm") or self.tap_bpm) / 60
        if self.speed != 1.0 and ctx["bar"] > 0:
            b = (ctx["beat"] - 1) * self.speed + 1
            ctx.update(beat=b, frac=b % 1.0, bwb=int(b - 1) % 4 + 1)
        if self.palette_mode == "lock":
            ctx["hue"] = self.palette_hue
        elif self.palette_mode == "cycle":
            step = (ctx["bar"] - 1) // 4 if ctx["bar"] > 0 else int(t / 8)
            ctx["hue"] = (ctx["hue"] + 0.125 * step) % 1.0
        return ctx
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

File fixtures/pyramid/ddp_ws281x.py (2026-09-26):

#!/usr/bin/env python3
"""DDP receiver for the WS2815 pyramid, driven from rave-box's SPI pin (GPIO10 / pin 19).

Receives DDP frames on UDP 4048 (same protocol as WLED and the panel receiver)
and writes them to the strip with rpi_ws281x over SPI (no root needed once the
user is in the `spi` group). A current limiter scales frames down so total draw
stays under --max-amps, and a dim idle animation shows when no frames arrive.

Signal path: Pi GPIO10 -> SP901E Signal In DAT 1 -> strip DI (BI tied to GND).

    ~/pyramid-venv/bin/python ddp_ws281x.py --leds 600 --max-amps 5
"""
import argparse
import colorsys
import math
import socket
import time

from rpi_ws281x import PixelStrip, ws

IDLE_S = 3.0
MA_PER_CHANNEL = 5.0      # WS2815 @ 12 V: roughly 15 mA per pixel at full white, ~5 mA per colour channel


def main():
    ap = argparse.ArgumentParser()
    ap.add_argument("--leds", type=int, default=600)
    ap.add_argument("--pin", type=int, default=10, help="10 = SPI MOSI (recommended), 18 = PWM (needs root)")
    ap.add_argument("--brightness", type=int, default=255)
    ap.add_argument("--max-amps", type=float, default=5.0, help="12 V current budget for the strips")
    ap.add_argument("--order", default="GRB", choices=["GRB", "RGB", "BRG", "RBG", "GBR", "BGR"])
    ap.add_argument("--port", type=int, default=4048)
    a = ap.parse_args()

    strip = PixelStrip(a.leds, a.pin, 800000, 10, False, a.brightness, 0,
                       getattr(ws, f"WS2811_STRIP_{a.order}"))
    strip.begin()
    n = a.leds
    budget_ma = a.max_amps * 1000

    sock = socket.socket(socket.AF_INET, socket.SOCK_DGRAM)
    sock.setsockopt(socket.SOL_SOCKET, socket.SO_RCVBUF, 1 << 20)
    sock.bind(("0.0.0.0", a.port))
    sock.settimeout(0.05)
    buf = bytearray(n * 3)
    last_rx, last_idle = 0.0, 0.0
    print(f"ddp_ws281x: {n} LEDs on GPIO{a.pin}, UDP {a.port}, limit {a.max_amps} A", flush=True)

    def show(data):
        # Current limiter: estimate draw from channel values, scale the whole frame if over budget.
        total = sum(data) / 255 * MA_PER_CHANNEL
        k = min(1.0, budget_ma / total) if total > 0 else 1.0
        for i in range(n):
            r, g, b = data[i * 3], data[i * 3 + 1], data[i * 3 + 2]
            if k < 1.0:
                r, g, b = int(r * k), int(g * k), int(b * k)
            strip.setPixelColorRGB(i, r, g, b)
        strip.show()

    while True:
        now = time.time()
        try:
            pkt = sock.recv(2048)
        except socket.timeout:
            pkt = None
        if pkt and len(pkt) >= 10:
            flags = pkt[0]
            hdr = 14 if flags & 0x10 else 10
            off = int.from_bytes(pkt[4:8], "big")
            ln = int.from_bytes(pkt[8:10], "big")
            data = pkt[hdr:hdr + ln]
            if off < len(buf):
                buf[off:off + len(data)] = data[:len(buf) - off]
            if flags & 0x01:
                show(buf)
                last_rx = now
        elif now - last_rx > IDLE_S and now - last_idle > 0.04:
            idle = bytearray(n * 3)
            for i in range(n):
                r, g, b = colorsys.hsv_to_rgb((i / n + now * 0.03) % 1.0, 1.0,
                                              0.06 + 0.04 * math.sin(now + i * 0.05))
                idle[i * 3:i * 3 + 3] = bytes((int(r * 255), int(g * 255), int(b * 255)))
            show(idle)
            last_idle = now


if __name__ == "__main__":
    main()

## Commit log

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2026-09-26 Show engine: read-ahead scenes driving tubes, HUB75 panel and DMX par
    showbrain turns deck timelines into groove/breakdown/build/drop scenes
    at 50 fps (numpy looks) over DDP and USB DMX, with a phone Commander,
    per-track drop overrides and calibration, sticky live-deck selection,
    and per-fixture delay compensation. Adds the panel DDP receiver, panel
    health test and fault log, and the par can DMX notes.
    [ddp.py, dmx.py, looks.py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]
2026-09-26 Name tubes rave-tube-1/2 and address fixtures by hostname
    WLED mDNS names now double as hostnames. DDP outputs resolve the name at
    start-up and refresh it every 30 s, so a new IP at a venue is picked up
    without per-frame lookups.
    [ddp.py]
2026-09-26 Pyramid: WS2815 over SPI from rave-box (DDP receiver + setup script)
    rave-box (Pi 3 A+) drives 600 WS2815 LEDs from GPIO10 (pin 19) through
    an SP901E, via rpi_ws281x over SPI (no root at runtime). Receiver has a
    current limiter and an idle animation; setup script enables SPI, fixes
    the core clock, enlarges the SPI buffer and installs a boot service.
    [ddp_ws281x.py]
2026-09-26 Rewrite README to describe the rig as built
    Replaces the original Engine DJ / StageLinQ weekend-plan README with a
    factual description: Pioneer XDJ-700 over Pro DJ Link, the CM4 services
    (deckdash, showbrain), fixtures, how to use and deploy, live-deck rules,
    known limitations and repo layout.
2026-09-26 Restructure repo around the system design; site config to .env; refresh docs
    Layout now mirrors the architecture:
    - brain/: deckdash, showbrain, provision, system (systemd units, udev,
    journald), tools, deploy.sh
    - fixtures/: tubes (scripts + enclosure CAD), pyramid, parcan, panel
    (receiver, health test, web UI)
    - docs/: brain.md, show-engine.md, fixtures/*, history/, manuals/
    Site-specific values move to a git-ignored .env (template in
    .env.example): Wi-Fi SSID/password for provisioning and WLED setup,
    optional host overrides. The show config uses ${VAR:-default} with
    .local hostnames, so no IPs remain in code. Network names, IPs and MACs
    are removed from the docs.
    Docs brought up to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
    [esp32_c3_zero_body.step, esp32_c3_zero_body.stl, esp32_c3_zero_lid.step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]
2026-09-27 Par can: channel map verified from the manual, enable W/Amber/UV
    Adds the fixture manual (V6 APP Battery Wireless) and documents the
    10-channel map, DMX/stand-alone menu modes and 2.4 GHz wireless DMX
    pairing. White, amber and UV are enabled in the show config.
2026-09-27 Stacked XDJ-style waveforms, lighting controller Commander, Serato-style library
    Dashboard (deckdash):
    - Stacked lanes are now the default waveform view (deck 1 on top, like the
    XDJ / rekordbox), with a header per deck and a phase meter between lanes.
    Overlay is still available. Old saved "overlay" preference is reset once.
    - New LIBRARY panel (Library.java + UI): crates/playlists from the rekordbox
    export via CrateDigger, search, genre / BPM-match / key-match filters,
    sortable columns, load to deck (buttons, double-click, shift+arrows), and
    PLAY/STOP, SYNC, MASTER per deck. Loading onto a playing deck needs
    confirmation. Load/transport over DJ Link is untested on the XDJ-700s.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
    [showbrain.py]
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2026-09-27 Projection mapping on :8100: surfaces, masks, live editor, presets
    - projector.py: pushes showbrain state to pages at ~20 Hz (SSE), layout API
    (validated, saved in layouts/, pushed live), presets, screen size report.
    - web/render.js: WebGL renderer, per-pixel inverse homography per surface
    (perspective-correct corner pin), masks and handles on an overlay, beat
    clock extrapolated with latency compensation. Contents: show (scene
    engine), pulse, tunnel, bars, title, solid, test.
    - web/index.html: projector output (fullscreen, test pattern, HUD).
    - web/edit.html: phone/laptop editor with live preview, corner dragging,
    nudging, surfaces, masks, output settings, presets.
    - docs/fixtures/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
2026-09-27 Smooth scrolling waveforms; keep the dashboard live when the event stream stalls
    Page:
    - Playhead timed by the Pi's clock (st.now) instead of arrival time, so
    Wi-Fi delay (0-90 ms, measured) no longer yanks the waveform back; small
    errors ease in, real jumps (cue, loop, load) still snap.
    - Waveform and grid scroll in whole device pixels, so columns keep
    sampling the same audio and peaks don't shimmer.
    - If /api/events goes quiet for 2 s, poll /api/state and keep retrying the
    stream. Measured on the rig: max 0.45 px per-frame wobble over 10 s.
    DeckDash.java:
    - The SSE and showbrain-feed tasks catch Throwable. A scheduled task that
    throws is cancelled for good, silently; after a res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
2026-09-27 Dashboard: drag tracks onto deck waveforms to load them
    - Drag a library row onto a deck's waveform lane, deck card or the deck
    chip above the library to load it there.
    - Drag a deck (its lane or chip) onto another deck to load the same track
    there (instant double).
    - Hold Shift while dropping to load and then play once the deck reports
    the track loaded.
    - The lane under the cursor is highlighted with what will happen, in red
    when that deck is playing; loading onto a playing deck still asks first.
    - Dropping a deck onto itself does nothing; the library table doesn't
    re-render mid-drag.
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2026-09-27 Visuals: field sketch (moving dots, links); smooth beat clock to stop jitter
    - New sketch, field: a lattice of independent dots that wander, drift across
    the surface, swell with a travelling wave and optionally link into a net.
    3x3-cell lookup per pixel, so thousands of dots stay cheap.
    - Jitter fix: the renderer no longer snaps to each ~20 Hz state update. The
    beat runs at tempo and eases towards the reported position (max 10% speed
    change), jumping only on seeks. Simulated with a noisy feed like the brain's:
    frame-to-frame wobble 149 ms -> 1.7 ms, same average timing.
    - The projector page and editor take the clock only from :8100; the :8110
    stream's state was a second, differen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
2026-09-27 Pi as tempo master: BPM reset, drop-aligned automix, tempo ramps
    deckdash (TempoMaster.java, /api/tempo, "tempo" in /api/state):
    - Off unless -Dtempo=on, which joins as a standard player number and
    sends status so the Pi can be master.
    - "take" waits for the current master's next beat, starts the Pi's beat
    clock on it (same tempo, same beat in the bar), then takes master, so
    the playing track doesn't jump. "ramp"/"reset" glide (eased, counted in
    beats); "reset" goes to a deck's original track BPM; "release" hands
    master to a deck.
    Dashboard:
    - Tempo row: RESET BPM (glide back to a deck's original BPM over
    16/32/64/128 beats) and MAKE MASTER.
    - Automix "Drop on outro end": starts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
2026-09-27 Fix show crash on beat jumps in breakdown; isolate fixture render errors
    The tube breakdown look kept sparks/droplets keyed to beat numbers. When
    the beat jumped back (live deck or track change mid-breakdown, loops, hot
    cues) exp(-(beat - b0) * 9) overflowed and crashed showbrain. Drop items
    'from the future' and clamp the exponent. Fixture.render now catches any
    look error, blacks out that fixture, logs once, and keeps the show running.
    Reproduced: 300-beat jump back raised OverflowError before, passes after.
    [looks.py, showbrain.py]
2026-09-27 Projector: adaptive render resolution, fps reporting, auto-reload after deploys
    - Output page measures its frame rate. With render_scale auto (new layout
    field, editor Output card), it drops the render resolution below 45 fps
    and climbs back above 57 fps; fixed 100-35% overrides.
    - It reports fps, render scale and GPU name every 2 s (/api/screen); the
    editor header shows them, red below 40 fps. The HUD shows them too.
    - Surfaces are drawn over their bounding box instead of a full-screen pass;
    the mask overlay is only cleared when something was drawn; no
    preserveDrawingBuffer.
    - projector.py and visuals.py send {"t":"hello","version"} (hash of the page
    files) first on every event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
2026-09-27 Automix KICK ALIGN: line up the kicks, not the rekordbox grids
    Both decks were in SYNC at the same BPM but the mixes flammed: SYNC aligns
    the rekordbox grids, and grids sit a few ms off their kicks. Measured on
    the rig from the detailed waveforms (bass-weighted onset per grid line in
    groove/drop sections), middle half of beats within ~7.5 ms.
    - gridError(n): each track's kick-vs-grid offset, trusted when consistent.
    - Before a mix: SYNC off on the incoming deck (only if it still holds the
    playing deck's BPM without it); start it on the playing deck's actual
    beat from its beat packets, shifted by the difference in grid errors.
    - 2.5 s in: measure where the grids landed from both decks' b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
2026-09-27 Beat squares: work out beat-in-bar every frame, so they don't skip
    The phase meter's and deck cards' beat squares used the decks' status
    beat-in-bar, which the XDJ-700s send a few times a second and we see at
    10 Hz: it lands late and skips. Measured on the rig over 12 s at 124 BPM:
    21 of 25 beats shown, beat 4 skipped four times ("123123...").
    liveBeatInBar() works it out every animation frame from the smoothed
    playhead and the track's beat grid (same source as the waveforms), and
    feeds the phase meter, the deck cards' squares and the "bar off by N
    beats" warning. Same 12 s on the rig: 25 of 25, none skipped.
2026-09-27 Dashboard: everything in the waveform lanes, no deck cards; page links at the top
    - The deck cards are gone. Each waveform lane now carries what they
    showed: artwork; title, artist, album, year, genre, label, rating and
    bitrate; status tags (PLAYING/CUED/PAUSED, LOOP, SYNC, MASTER, ON AIR,
    REVERSE, END); key, drop countdown, track BPM, pitch and a big
    effective BPM; hot and memory cues (with loops shaded) in their
    rekordbox colours on the scrolling waveform; and a whole-track
    overview strip with sections, drops, cues, playhead and elapsed · bar ·
    remaining. Both decks fit on one screen.
    - OVERLAY and the card layout buttons are removed; stacked lanes only.
    - Page links (Decks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
2026-09-27 Phase meter: sweep markers on every playing deck, none on paused ones
    The orange gauge marker showed the non-master deck's phase against the
    master, even when that deck was paused, so it sat on the wrong track.
    Now every playing deck gets a marker sweeping left to right through each
    beat, in its own colour; with both playing they move together when in
    phase, and the text gives the offset against the master. Paused and
    cued decks show no marker and say so.
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2026-09-27 Stage: colours that match the real lights; projector can show the visuals page
    Why the colours didn't match: the page read each LED's drive level as
    an sRGB colour (far too dark for dim levels), then boosted it x3 and
    clipped per channel, which shifted hues towards white; the preview also
    skipped the tubes' 60% brightness, sampled 40 of 60 LEDs, and updated
    at 10 Hz, so strobes and drop hits fell between samples.
    showbrain: the preview is what's actually sent (every strip LED, with
    the fixture's brightness; the par can's R/G/B/W/A/UV mixed with emitter
    tints, hue-preserving), every 2nd frame (25 Hz); state gains
    fixture_info (kind, LED count). projector: relays state at 25 Hz.
    Stage: drive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
    [showbrain.py]
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2026-09-27 visuals: Max Cooper set (seething, seed, orb, pipes; eye paper and lines)
    Simplified takes on five Max Cooper videos, each with presets:
    - seething (Andy Lomas): a lumpy ball of jittering Voronoi cells shaded
    as domes on a sphere, optional brain-like folds; grows through the
    section, breathes on the kick
    - seed (Vincent Houze): folded-fractal neon trees over glowing ground
    dots; sway in time, grow a level at a time through the section
    - eye gains a paper background and thin lines from the pupil for Third
    (Vicetto); new params default to 0, so existing presets are unchanged
    - orb (Whiskas fx, Harmonisch Serie): black glass orb and circling pearl
    on vintage paper; mirror, tile and R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
2026-09-27 Stage frames: each frame once, only to the Stage page; playback rides out bursty Wi-Fi
    On the rig the Stage page fell back to ~9 updates/s: every update carried
    four full frames as JSON string lists to every page on the projector
    (155 kB/s), the per-page queue overflowed and dropped updates (89 of 150
    in 6 s), delivery lagged up to 2 s in bursts, and the page gave up on
    timed playback when frames arrived late.
    - showbrain: frames compact, one hex string per fixture (6 chars/LED).
    - projector: sends each frame once, only to /api/events?frames=1 pages
    (bigger queue for them); drops the per-LED preview from the normal
    state stream; recovers if showbrain's clock jumps back (no RTC).
    - stage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
    [showbrain.py]
2026-09-27 System panel: brain health on the dashboard (click the logo)
    - deckdash: SystemInfo samples every 2 s (temperature, throttling and
    under-voltage, CPU per core, load, RAM/swap, disk and recordings, Wi-Fi
    signal and throughput, service state/CPU/memory/restarts, clients per
    page, USB devices, DJ Link devices, JVM heap), served at /api/system.
    - Dashboard: logo opens a full-screen System view in the current design;
    a health dot beside the logo shows the worst status every 10 s.
    - deploy.sh compiles SystemInfo.java; docs/api.md documents the fields.
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2026-09-27 Brand: stencil SEKTOR5 wordmark as the app logo
    Replaces the radar mark + Michroma wordmark in the top bar of every
    page (Decks, Lighting, Projection, Stage, Visuals) with the heavy
    stencil wordmark: SEKTOR in the text colour, the 5 in the accent orange.
    It's inline SVG paths (no PNG, font, mask or ids), so it stays sharp and
    follows the page theme. Favicon is now the orange stencil 5.
    docs/brand gains the stencil SVGs (current/white/black, favicon) and
    notes that it's the app logo.
2026-09-27 Admin PIN: view-only by default, one PIN unlock per browser (5 years)
    - brain/common/s5auth.py + brain/deckdash/Auth.java: the same signed-cookie
    scheme (HMAC-SHA256, PBKDF2 PIN hash in /srv/rave/auth.json). GET stays
    open; every POST on deckdash (/api/deck, /api/tempo), showbrain, projector
    and visuals returns 401 without the cookie (projector /api/screen exempt).
    /api/auth on every port; 0.5 s per check, 8 failures/10 min lock 10 min.
    - brain/common/web/s5auth.js on every control page: VIEW ONLY / ADMIN badge,
    PIN dialog on refused changes, automatic retry, lock-this-browser.
    - brain/tools/set_pin.py (hidden input; --sign-out, --off); deploy.sh ships
    the shared files and gains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
    [showbrain.py]
2026-09-27 Stencil logo everywhere; System view header matches the app
    - System view: the page's own logo in the same spot as the app header
    (cloned at open), SYSTEM and host to its right; clicking the logo returns
    to the app (replaces the old title and CLOSE button).
    - Visuals: header h1 sizes to the logo (the old radar logo was clipped by
    the heading's line box).
    - Reaction-diffusion lab page gets the stencil logo.
    - README uses the stencil wordmark (light/dark aware).
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2026-09-27 Tailscale: HTTPS page links, greyed out for viewers; Tailscale card in System
    - Browsers force HTTPS on ts.net, so http://host:8090 links broke over Tailscale.
    Pages now link via s5auth.js (a[data-port]): HTTPS keeps each port (served by
    tailscale serve), except the dashboard which is on 443.
    - Viewers see the page links greyed out (clicking asks for the PIN); admins see
    them greyed out only if the page isn't reachable from here (public link).
    - System panel: Tailscale card (state, name, address, devices online, public
    link) with admin buttons to turn the public link or Tailscale off/on
    (POST /api/system/tailscale, Tailscale.java).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
2026-09-27 One steady top bar on every page; System view from any page's logo
    - Shared .s5bar (set by s5auth.js in <head>): 64 px, never wraps, same
    padding/gaps; the logo box is 96 px everywhere so the page links never move.
    Page-specific bits in the bar and the page below fade in. Page links wait
    for Montserrat (cached) so they don't shift when it swaps in, and viewer
    greying starts from the last known state.
    - Dashboard master BPM and the Stage view controls move just under the bar
    (they made it wrap onto a second row).
    - System view moves to brain/common/web/s5system.js, served by deckdash and
    loaded on every page: the logo opens it anywhere, with the health dot.
    deckdash lets the rig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
2026-09-27 Projection and Visuals: the display as a full-width hero, controls in a panel below
    - The stage / preview sits on a full-width band at the top, as large as fits
    (up to ~62% of the screen height, projector aspect), with a status strip
    under it (connection, projector, show; Handles on wall and Test pattern).
    - Controls move into a hairline card grid underneath.
    - Visuals: the sketch picker leaves the top bar for a Sketch card that also
    holds its description, randomise/nudge/reset and presets.
2026-09-27 Synthetic rig: run the whole app locally with the hardware off
    brain/sim/run.sh starts showbrain, projector and visuals (the real code)
    against brain/sim/fakerig.py, which stands in for deckdash and the DJM:
    the dashboard API on :8080 and showbrain's UDP feed (20 Hz status, beat
    packets, mixer messages), same formats as the real services.
    fakerig plays an endless beat-matched set of 40 generated tracks with
    real phrase structure (intro, grooves, breakdowns, builds, drops, outro)
    and serves their timelines, waveforms and library. It auto-mixes each
    track in over the outgoing outro (fader up over 8 bars, bass and tempo
    master swap, fade out over 8 bars, reload), with mixer levels, share,
    bass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
2026-09-27 Argon fan: single-byte speed only, and opt-in after testing
    Writing a register address first (0x80, newer Argon scripts) wasn't
    understood by our case's firmware; the Pi dropped off right after a test.
    Speed is now the original one-byte protocol, clamped to 0-100 (other values
    are case commands, 0xFF cuts power). setup_brain.sh installs the service but
    doesn't enable it until the fan is tested in the case.
    [argon_fan.py]
2026-09-27 System view: only show power/clock flags that have actually happened
    Four green 'UNDER-VOLTAGE / THROTTLED / FREQ CAP / TEMP LIMIT' flags read as
    problems. Now a flag appears only when it's happening (red) or happened since
    boot (amber); otherwise one line says power and clock speed are normal.
2026-09-27 Mobile: tab bar at the bottom; lock icon and SIM pill in the top bar
    - Phones (<=760 px): the page links become a bottom tab bar with icons
    (Lighting, Projection, Decks in the middle, Visuals, Stage); the logo still
    opens System.
    - Viewer/admin is a lock icon at the right end of the top bar (orange view
    only, green admin) instead of the text badge bottom right.
    - Simulation: an amber SIM pill in the top bar replaces the page's LIVE pill
    and the bottom strip; tapping it opens sound on/off, volume and Back to real
    decks. With no decks, a NO DECKS pill offers Start simulation.
    - Stage: view controls on one scrolling row on phones; Lighting: scene name
    sized to fit.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
2026-09-27 Every page through the dashboard's address (/lighting/, /projection/, /visuals/)
    The public link (Tailscale Funnel) can only publish the dashboard, so admins
    there couldn't open the other pages. deckdash now passes /lighting/,
    /projection/ and /visuals/ through to showbrain, the projector and visuals
    (Proxy.java, event streams included). Over HTTPS the page links use these
    paths; pages loaded under one send their /api/... requests and event streams
    through it (s5auth.js). On the rig's network the ports work as before.
    Changes still need the PIN (the cookie is passed through). Also: no crash on
    browsers without AbortSignal.timeout.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
2026-09-27 Section tabs under the display (Projection, Visuals, Stage); Stage controls into a View section
    - s5auth.js: S5AUTH.sectionTabs: one tab per section of a page's controls,
    pinned under the display; only the chosen section shows; follows sections
    that change (a sketch's groups); remembers the choice per page.
    - Projection: Surfaces / Selected surface / Masks / Output / Presets.
    Visuals: Sketch + the sketch's groups. Stage: View / Rig / Add fixture /
    Selected / Match real lights / Layout; picking a fixture opens Selected.
    - Stage: camera, haze, lasers and glow move into the View section, so nothing
    sits between the top bar and the view; the panel toggle is a PANEL button
    on the view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
2026-09-28 Auto-update: the brain follows GitHub's main every 15 minutes
    - brain/system/s5_update.sh + s5-update.service/.timer: compare each target's
    deployed commit with main (for that target's files) and deploy what's
    behind, on the brain itself; wait while a real deck is playing; never
    touch /preview/; replaces itself when a newer version is on main.
    - deploy.sh: S5_BRAIN_HOST=local deploys on this machine; 'all' now records
    web, visuals and tools too; S5_DEPLOY_BY labels the deploy marker.
    - setup_brain.sh installs git and enables the timer. docs/brain.md.
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2026-09-29 Showbrain drives the leg pyramids: spiral builds, lasers on the drop
    A new fixture kind, "pyramid" (pyramidL / pyramidR in config.json): four legs of leds_per_leg,
    then the laser as an on/off pixel, over DDP (docs/fixtures/leg-pyramids.md). Its looks
    (looks.pyramid), mirrored left and right:
    - build: the spiral fill, the legs lighting from the feet in a spiral round the outside, led by
    a white head, reaching the apex as the build ends, flickering faster near the drop;
    - drop: a white burst down from the apex, then full colour pulsing on the kick with falling rings
    (and a highlight turning round the legs after 4 bars); the laser comes on with the drop, held a
    bar, then on the kick, then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
    [ddp.py, looks.py, showbrain.py]
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2026-10-03 Showbrain: pyramids wired as two diagonal pairs on two data lines
    "wiring": "diagonals": front-left + back-right on one data line, front-right + back-left on the
    other (an SP901E's DAT 1 and DAT 2 from two Pi pins), sent as two streams of one leg each to
    "ports" (default 4048, 4049). Looks for two pairs: the spiral steps round two stations (12 steps,
    alternating diagonals), groove comets and the drop's highlight swap diagonal each beat. The doc
    has the rave-box wiring (pyramid on GPIO 10 / 4048, pyramid2 on GPIO 18 / 4049).
    [looks.py, showbrain.py]
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2026-10-03 Lights: more energy through the whole track, not just the drops
    Outside drops and builds the looks mostly breathed slowly at 5-20%
    brightness, and intros ignored the beat entirely. On top of that the
    master intensity (0.8), the tubes' brightness (0.6) and the mixer-level
    dip (down to 35%) stacked, so the tubes peaked around 40%.
    - INTRO and OUTRO hit on every kick (tubes, pyramids, panel, par); the
    outro stays at 80% instead of halving.
    - GROOVE: harder kick, higher floor, an off-beat hi-hat flick.
    - The kick's punch scales with the bar's energy from the timeline
    (drive(): 0.8x quiet bars, 1.3x loud).
    - Breakdowns a little brighter, with more sparkles on the tubes.
    - PAUSED no longer ho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
    [looks.py, showbrain.py]
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
